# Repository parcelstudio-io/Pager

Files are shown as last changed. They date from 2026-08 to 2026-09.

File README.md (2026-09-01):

# Mochi Pager

Mochi Pager is a pager-sized, expressive voice AI companion. The first product target is a rounded handheld device with two large round eyes, curious idle gaze, a sliding live caption, microphone, speaker, Wi-Fi, BLE, and optional standalone 4G LTE—and exactly two physical controls: the top conversation button and a power slide switch. The conversation button deliberately opens or closes a visibly live session; while it is open, the user and assistant can speak in a full-duplex, voice-interruptible conversation without pressing for each turn, while the assistant's words slide through the caption below its face. A companion mobile app onboards the device over BLE (Wi-Fi credentials, cellular APN, account claiming) and shows an encrypted local cache of opt-in cloud conversation history. The pager connects through a private gateway to the OpenAI Realtime API; it does not run the language model on the device.

The current phase is V1 interaction implementation plus EVT (engineering validation) planning. A zero-dependency local session broker and browser device simulator now provide the first runnable full-duplex slice; embedded firmware, the mobile app, cloud history, and cellular work remain staged behind it.

## Start here

- [Product concept](docs/design/0001_mochi_pager_product_concept.md)
- [V1 prototype high-level design](docs/prototype/0001_v1_high_level_design.md)
- [V1 beginner build guide and exact materials](docs/prototype/0002_v1_beginner_build_guide.md)
- [Companion app and synchronization architecture](docs/design/0002_companion_app_and_sync_architecture.md)
- [Carrier board hardware design](docs/design/0003_mochi_carrier_board_design.md)
- [MVP requirements](docs/requirements/0001_mvp_requirements.md)
- [Component sources and staged BOM](docs/research/0001_component_sources_and_bom.md)
- [Shared-conversation and video source audit](docs/research/0002_reference_observations.md)
- [Independent verification and corrections](docs/research/0003_independent_verification_and_corrections.md)
- [35-project-day build plan plus companion-app track](scrum/20260830/task_0001/daily_plan.md)
- [Technical decision log](docs/decisions/README.md)
- [Beginner IoT and electrical-engineering course](edu/README.md)

## Current verdict

The interaction mule is already ordered: one full M5Stack CoreS3 K128, recorded in the [daily log](scrum/20260830/task_0001/daily_log.md). Confirm only a known-good data-capable USB-C cable now; do not buy a second CoreS3. First run the laptop V1-A slice, then use the K128's documented full-duplex audio path to measure simultaneous capture/playback, AEC feasibility, voice barge-in, on-device captions, and truthful session indication. Use Wi-Fi and then a phone hotspot before adding radio complexity. Buy the separate SIM7600G-H cellular mule only after the Wi-Fi full-duplex vertical slice passes its gate. Do not buy a final battery, custom display, bare cellular module, or 5G hardware yet.

This ordering protects the project from three expensive early mistakes: choosing an enclosure before measuring the parts, choosing a battery before measuring modem peaks, and integrating RF onto the first PCB.

The major load-bearing claims reviewed in the 2026-08-30/31 verification pass, its corrections, and its explicitly unverifiable items are logged in [research 0003](docs/research/0003_independent_verification_and_corrections.md). That pass also added requirements the first draft missed: the sliding caption, companion app, and two-control constraint.

## Run V1-A now

Node.js 20 or newer and an OpenAI API project are required. The standard API key stays in the local server process.

```bash
cp .env.example .env
# Edit .env and replace OPENAI_API_KEY=replace_me
npm test
npm start
```

Then open `http://localhost:3000`. No `npm install` is required because V1-A has no runtime package dependencies. The idle face begins calm and centered: its first curious gesture arrives after 3–5 seconds, later gestures follow 6–12 second pauses, and every synchronized up/down glance, side-to-side look-around, or clockwise/counterclockwise roll returns to center. Each gesture now uses brief saccades separated by still fixations instead of continuous pupil drift; the cream eye aperture follows vertical gaze like an eyelid opening, while speaking no longer produces a rhythmic eye bob. Conversation and battery state take priority. Face animation loads as an optional enhancement after Start/Stop is wired, so an animation import or initialization failure leaves a static face without disabling conversation control. The gateway renders the versioned [`prompt/mochi-realtime.ftl`](prompt/mochi-realtime.ftl) on the server, so the browser cannot inject history or system instructions. The localhost default has no real account/history service and truthfully marks that context unavailable. API use may incur charges; set a conservative project budget before testing. The [beginner build guide](docs/prototype/0002_v1_beginner_build_guide.md) contains the complete safety, setup, acceptance, and CoreS3 bring-up sequence.

## Repository organization

```text
docs/
  decisions/       numbered architecture decision records (ADRs)
  design/          product and industrial-design specifications
  requirements/    measurable product requirements
  research/        source audits, comparisons, and BOMs
edu/               progressive IoT and electrical-engineering course for software engineers
prompt/            version-controlled server-side Realtime instruction templates
scrum/
  YYYYMMDD/
    task_NNNN/      task brief, daily plan, evidence, and retrospective
hardware/           future PCB and mechanical source files
src/                production device, gateway, companion-app, and cloud code only
tests/              automated tests spanning production components
tools/              simulators, fixtures, flashing, and developer utilities
```

Create directories only when they gain real content. When implementation begins, a sensible source split is `src/device/`, `src/gateway/`, `src/app/` (the companion mobile app), and `src/cloud/`. Hardware design should live in `hardware/pcb/` and `hardware/mechanical/`, not under `src/`.

Task IDs are repository-wide, zero-padded, and monotonically increasing. Decision records have their own monotonically increasing sequence because a decision's history is independent of sprint/task history. Never renumber an accepted or superseded record.

## Reference boundary

The shared ChatGPT post exposes only one answer, which proposes a **95 × 60 × 30 mm** enclosure. The earlier conversation is not present in the public page, so this repository treats that size as a maximum envelope rather than inventing unavailable prior decisions.

The visual reference is Huy Vector's [Tiny Pocket AI Assistant](https://www.youtube.com/watch?v=25RGnr407PM) and its [build guide](https://www.huyvector.org/robots-kinetic/pocket-ai-assistant). We borrow its face-first charm, blinking eyes, compact status text, and cheeky personality. We do not copy its exposed battery, conductive frame, cloud service, or electronics as a product architecture.

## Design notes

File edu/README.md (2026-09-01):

# Educational notes

This folder is a small course for a software engineer who is new to electronics, embedded systems, and Internet of Things (IoT) products. It assumes you can read code, reason about APIs, and debug distributed software. It does **not** assume you know what voltage, ground, a GPIO pin, a modem, or a printed circuit board does.

Start with lesson `0000`. Do not skip it because its concepts are the vocabulary used by every later lesson.

## If your goal is to design a PCB in KiCad

Follow the [PCB design path](PCB_DESIGN_PATH.md). It turns the general course into staged work with evidence gates:

1. learn the electrical foundations in lesson `0000`;
2. learn the [core circuit patterns used in real schematics](CORE_CIRCUITS_FOR_PCB_DESIGN.md);
3. design, fabricate, and measure the [LED and button board](labs/0001_led_button_board.md);
4. design and bring up the [compute-module carrier](labs/0002_module_carrier_board.md); and
5. only then capture and review a modular Mochi carrier.

The goal is not merely to operate KiCad. It is to make a board whose circuit was calculated, whose exact parts and footprints were verified, whose manufacturing files were inspected, and whose physical behavior was measured safely.

## How these lessons teach

Each lesson should:

- define a physical or networking concept before using its acronym;
- connect it to a familiar software idea, then state where that analogy stops working;
- include a concrete Mochi example or calculation;
- separate general teaching from the exact product decision;
- end with questions you can answer without memorizing prose.

Hardware ultimately follows physics and component datasheets, not an analogy. Examples such as voltages, resistor values, current, and battery life are explicitly illustrative unless they cite a measured prototype or accepted requirement.

## Reading order

0. [Start here: IoT and electrical fundamentals](0000_start_here_iot_and_electrical_fundamentals.md) — circuits, voltage, current, power, ground, digital pins, regulators, sensors, actuators, safe measurements, and the device/network/service loop.
1. [System architecture from a button press](0001_system_architecture.md) — how to divide one physical product into local state, realtime data paths, networks, and services.
2. [Modules, buses, and embedded audio](0002_modules_buses_and_audio.md) — how boards and chips communicate, and how microphone and speaker samples move on time.
3. [Printed circuit boards and manufacturing](0003_pcb_fundamentals_and_manufacturing.md) — how a schematic becomes physical copper, an assembled board, and a controlled first power-on.
4. [Cellular, radio, power, and certification](0004_cellular_rf_power_and_certification.md) — how a modem reaches a carrier, why antennas and current bursts are physical design problems, and what module approval does not cover.
5. [Realtime voice, memory, and privacy](0005_realtime_voice_memory_and_privacy.md) — sampled sound, streaming, full duplex, echo cancellation, interruption, gateway trust, and distinct kinds of memory.
6. [Companion apps, Bluetooth setup, and synchronization](0006_companion_app_provisioning_and_sync.md) — provisioning, claiming, Bluetooth Low Energy, secret paths, authoritative revisions, history cursors, and deletion tombstones.
7. [Reading the Mochi carrier schematic](0007_reading_the_carrier_schematic.md) — pin budgets, voltage domains, burst-current arithmetic, tuned decoupling, and what desk verification can and cannot prove.

Use the [plain-language glossary](GLOSSARY.md) whenever a later document introduces an unfamiliar term. The lesson must still explain important terms inline; the glossary is a backup, not required pre-reading.

The [KiCad lab index](labs/README.md) links the hands-on exercises. These are fabrication exercises, so each has a completion gate; do not treat a clean screenshot, ERC, or DRC as a passing result.

## A practical first pass

If the complete course feels large, use this order:

1. Read sections 1–9 of lesson `0000` and answer its self-check.
2. Run the existing browser prototype; identify its device, network, and service boundaries using lesson `0001`.
3. With the purchased CoreS3 still unmodified, follow lesson `0000`'s measurement workflow and the beginner build guide. Do not begin by designing a battery charger or cellular PCB.
4. Read lessons `0002`–`0004` immediately before working with that hardware.
5. Read lessons `0005`–`0006` before changing the Realtime gateway, memory model, provisioning flow, or companion app.

When stuck on a hardware sentence, ask four questions:

```text
What supplies the energy?
What path does current take out and back?
Which component owns the signal or state?
What measurement would prove the claim?
```

Those questions turn words such as "rail," "bus," "ground," and "live" into testable statements.

## Teaching versus specification

Files in `edu/` explain mental models. They are not the product specification. Accepted product choices live in `docs/decisions/`, measurable requirements live in `docs/requirements/`, detailed designs live in `docs/design/`, and executable code lives in `src/` or `tools/`.

The primers link to those sources at the end. When a teaching example and an accepted requirement differ, the accepted requirement controls the product.

Add future lessons with the next monotonic prefix. Lesson `0000` is the one intentional prerequisite inserted before the original numbered series.

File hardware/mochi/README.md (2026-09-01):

# Mochi R1 Walter carrier

This directory contains a deterministic **electrical reference and placement study** for
the pager-size Mochi companion. It is intentionally useful for architecture review,
firmware pin contracts, component purchasing, and mechanical experiments. It is **not a
fabrication release**.

The current baseline is a 60 × 82 × 1.2 mm four-layer carrier around the orderable
QuickSpot Walter LTE-M/Wi-Fi/BLE/GNSS SoM. The previously proposed MIKROE-6396 Click was
removed because its official product page now reports it unavailable. The design decision
and alternatives are recorded in [ADR 0013](../../docs/decisions/0013_use_walter_family_for_rev_a_evt.md).

## Files

- [`mochi.kicad_sch`](mochi.kicad_sch) — KiCad system-level schematic.
- [`mochi.kicad_pcb`](mochi.kicad_pcb) — four-layer outline and reviewed component
  placement; intentionally unrouted.
- [`doc/design_manifest.json`](doc/design_manifest.json) — machine-readable electrical,
  configuration, and release-boundary contract.
- [`doc/bom.csv`](doc/bom.csv) — proposed parts and DNP state.
- [`doc/connectivity.csv`](doc/connectivity.csv) — exact named-net endpoints.
- [`doc/pin_map.csv`](doc/pin_map.csv) — Walter/ESP32 GPIO assignment.
- [`doc/bringup_and_validation.md`](doc/bringup_and_validation.md) — physical proof plan.
- [`doc/research_matrix.md`](doc/research_matrix.md) — dated primary-source comparison.
- [`reports/`](reports/) — KiCad/MCP and command-line check evidence.

The generated `Mochi_Reference.pretty` footprints are review geometry, except that the
Walter header pitch, pin order, pad centers, and antenna keepout follow QuickSpot's open
footprint. Every footprint must still be replaced or independently checked against the
exact ordered part and assembly process before fabrication.

## Reproduce the desk checks

From the repository root:

```bash
node tools/hardware/generate_mochi_reference.js
python3 tools/hardware/check_carrier_design.py
```

The current expected result is **66 passed, 2 warnings, 0 failed**. The warnings are
deliberate: the PCB has no routes, and the back-mounted Walter reference produces one
library-parity warning. KiCad ERC is zero. KiCad DRC otherwise reports the 168 expected
unconnected items and no unexpected physical-rule category.

KiCad MCP was also pointed at this exact project. Its full production quality gate is
expected to fail and is retained as useful evidence: a label-oriented system schematic
has zero explicit wires, the PCB is unrouted, and reference footprints are not a release
library. MCP did confirm clean ERC, 100% schematic-to-PCB named-pad transfer, matching
reference sets, a 60 × 82 mm frame, and zero courtyard issues.

## What the board connects

```text
USB-C charge only ─ protection ─ BQ25628E ─ SYS_ALWAYS ─ TPS22950 ─ SYS_SW ─ Walter VIN
                             │                    ▲                    └─ 200uF EVT reservoir
protected 1S pack + NTC ─────┘                    │
                                           latching slide

SYS_SW ─ TPS63802 ─ 3V3_PERIPH ─┬─ LCD + touch
                                ├─ MAX98357A ─ differential 8ohm speaker
                                ├─ TPS22918 ─ MIC_3V3 ─ PDM mic + isolation + cyan LED
                                └─ DNP TPS22918 ─ Arducam Mega + white LED
```

Walter contains the ESP32-S3, Wi-Fi/BLE, LTE-M/NB-IoT modem, nano-SIM, GNSS, RF front
end, and modem-to-ESP UART. The carrier therefore does not route a 50-ohm cellular trace,
SIM bus, 1.8 V modem GPIO, or user USB data.

## Stop conditions

Do not order a PCB from this directory until all of these are true:

- production symbols, footprints, land patterns, paste apertures, and exact order codes
  are frozen;
- the schematic is redrawn with conventional wires/hierarchy and peer-reviewed;
- the power stages are laid out from vendor reference layouts and the entire PCB is
  routed with zero unexplained ERC/DRC findings;
- enclosure CAD closes around the display, battery, speaker cavity, module, USB, switches,
  coax bends, and LTE antenna;
- a physical prototype passes the validation plan; and
- an RF/certification lab accepts the portable simultaneous-transmitter plan.

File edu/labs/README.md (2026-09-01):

# KiCad PCB labs

These labs convert the electrical lessons into fabrication evidence. Complete them in order:

1. [LED and button board](0001_led_button_board.md) — a low-voltage, through-hole, two-layer board whose behavior can be calculated and measured.
2. [Compute-module carrier](0002_module_carrier_board.md) — a modular embedded board with power, GPIO, connectors, debug access, decoupling, and test points.

Use the current stable KiCad release and the official [Getting Started in KiCad 10](https://docs.kicad.org/10.0/en/getting_started_in_kicad/getting_started_in_kicad.html) guide. The detailed [Schematic Editor](https://docs.kicad.org/10.0/en/eeschema/eeschema.html) and [PCB Editor](https://docs.kicad.org/10.0/en/pcbnew/pcbnew.html) manuals are the primary references for current controls. Menu names can move between versions, but the engineering sequence remains schematic → footprints → ERC → board rules → placement → routing/zones → DRC → fabrication outputs → inspection.

Do not skip a lab's gate. A rendered board image or clean DRC is not a working-board result.

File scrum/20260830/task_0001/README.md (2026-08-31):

# Task 0001 — Design and validate the Mochi Pager EVT path

Start date: 2026-08-30  
Status: In progress — Day 1 purchase made 2026-08-31, see [daily log](daily_log.md)
Owner: Project team

## Outcome

Produce an evidence-backed EVT that demonstrates a cute local face with a sliding live caption and a button-started, visibly live, full-duplex voice conversation through our secure OpenAI Realtime gateway. Inside the live session, capture and playback are concurrent and speech interrupts assistant output without a per-turn press; a second button press returns to private idle. The shipping interaction exposes exactly two physical controls: one illuminated conversation start/stop button and one latching power on/down switch. Also validate the hybrid companion architecture: foreground BLE for secure nearby provisioning/recovery, the gateway as the authority for account binding, non-secret settings, and opt-in history, Wi-Fi and phone-hotspot portability, and a separately measured standalone-LTE option. End with either a reviewed modular-carrier PCB order and validated assembled boards or a documented gate failure with the specific next experiment.

## In scope

- Product interaction and expression system, including the sliding caption (PR-07).
- ESP32-S3 interaction mule.
- Gateway and OpenAI Realtime integration.
- Companion-app Track B: foreground BLE provisioning (Security 2 with downgrade rejection), secure claiming/recovery, BLE/local-only custom Wi-Fi/APN/authentication secrets, cloud-delivered signed public carrier presets, binding-scoped revisioned configuration, and opt-in history synchronization (ADR 0007 and the companion-app requirements).
- Wi-Fi, hotspot, and conditional standalone 4G tests.
- Audio, latency, data, power, thermal, and reconnect measurements.
- Paper/foam and printed enclosure iterations.
- Conditional four-layer modular carrier PCB.
- Education, purchasing rationale, and ADR trail.

## Out of scope for this task

- Full 5G integration.
- Injection-mold tooling or production certification.
- Bare cellular LGA routing on the first PCB.
- Background always-listening/wake-word launch behavior or a production-grade guarantee that AEC works in every acoustic environment. Functional session-scoped full duplex is in scope and gated.
- A shipping/user-facing push-to-talk or half-duplex mode. Half-duplex may be measured only in developer fixtures to diagnose an acoustic failure; it fails Gate A rather than becoming a third interaction mode.
- General-purpose BLE pairing, audio, or accessory support; BLE is reserved for foreground commissioning/recovery in this EVT.
- Camera features, GPS-backed product features, and bulk component orders.
- Production launch, consumer data-policy sign-off, or carrier certification completion.

## Purchase ceilings before re-approval

- Gate A actual board purchase: one full CoreS3 K128 ($77.90 paid on 2026-08-31), plus a known-good cable ($5–10 observed if none is already available), tax/shipping. See the [daily log](daily_log.md).
- Acoustic mule, only after Day 8's concurrent local audio baseline: one compatible discrete digital mic ($8.95 observed), I²S amp ($5.95), speaker ($1.95), illuminated conversation control, latching power switch, and safe prototyping board/connectors; target $20–40 plus shipping after pin/power/reference-path review.
- Gate B, only after Day 13: one SIM7600G-H HAT ($97.99 observed), one compatible AUX/diversity LTE antenna (live quote), and **one** SIM/service path. Order a low-cost SIM first, read/check the received IMEI, then activate one month of suitable 5–10 GB-equivalent data. Soracom and direct-carrier plans are alternatives, not combined purchases.
- Instrumentation: a $15–30 USB meter may be bought for average energy only. Gate C peak evidence requires access to a bandwidth-appropriate oscilloscope/current probe or shunt/power analyzer and an adequate documented 5 V HAT supply; quote, borrow, or rent before purchase if these are not already available.
- Gate C: no PCB/enclosure order until a live quote, BOM, measured power budget, and DFM review are attached to the daily log. Quote rather than assume cost.
- 5G and bare production cellular modules: $0 in task 0001.

All prices were observed on 2026-08-30 and are not purchase guarantees. Recheck price, lead time, return policy, region, carrier/IMEI acceptance, and shipping at checkout.

## Success evidence

- A recorded live session with at least ten exchanges and no per-turn presses, concurrent capture/playback evidence, a caption that tracks speech and trims on interruption, speech-driven barge-in, explicit button stop, and recovery after network loss. The capture gate and its indicator fail low through reset, crash, bootloader, and OTA paths; hard-off prevents auto-resume and USB/debug/modem back-power.
- A recorded first-boot and recovery walkthrough: foreground Security 2 BLE provisioning with downgrade attempts rejected and no plaintext custom Wi-Fi/APN/authentication secrets in a BLE trace, cloud, durable app storage, or logs; provisioning remains alive through claim and new-recovery-proof acknowledgement; signed public carrier-preset metadata may come from the cloud; and the eight-second power-on boot chord is capture-gated but cannot steal or reclaim an owned pager. Factory bootstrap fails after first claim, every new binding rejects the prior owner's recovery code, and an online app opens claimed-device setup only after authenticated app→gateway authorization; offline setup uses the touchscreen or boot chord. Release/recovery erases local network/cellular credentials, and resale/loss/account-deletion flows handle physical-SIM removal or carrier deactivation explicitly.
- A recorded app synchronization walkthrough: binding-scoped app- and pager-origin `config_revision` conflict/idempotency handling plus default-off history opt-in/inspect/export/delete across two app installations, offline recovery, reinstall/restore, ordered cursor catch-up, and content-free deletion tombstones. It demonstrates expected-version conflicts, `oldest_available_seq` full reconciliation, a device-bound backup-excluded cache, retained-history access after future saving is disabled, derived-memory deletion cascades, and truthful account-deletion behavior across the at-most-24-hour offline authorization lease. Stored history contains only finalized machine transcripts, the assistant prefix known to have been heard (or an interruption marker), sanitized visible tool results, and no raw audio.
- Reviewed privacy copy that distinguishes Mochi-controlled storage from the current provider data-retention policy and does not promise zero provider retention without verified approved controls.
- At least 50 timed Wi-Fi speech segments, a 100-utterance endpoint-correctness corpus, 100 scripted barge-ins, 60 assistant-speaking minutes for false-interruption testing, a 65-minute duplex/provider-renewal soak, and a 30–60 minute phone-hotspot session.
- If Gate B opens: standalone LTE attach/reconnect, signal, data, average/peak current, temperature, GNSS trial, and one exact ESP32-S3 modem transport under concurrent encrypted voice/display/audio load.
- Current/energy measurements supporting the battery decision.
- Mechanical volume model plus measured AEC reference delay, residual echo, double-talk, false-interruption, and acoustic-layout observations.
- Reviewed schematic/layout/DFM evidence before any PCB purchase.
- Incoming inspection and bring-up records for any ordered PCBs.
- New ADRs for decisions that changed during execution.

## Planning sources

- [Product concept](../../../docs/design/0001_mochi_pager_product_concept.md)
- [Companion app and synchronization architecture](../../../docs/design/0002_companion_app_and_sync_architecture.md)
- [MVP requirements](../../../docs/requirements/0001_mvp_requirements.md)
- [Component research](../../../docs/research/0001_component_sources_and_bom.md)
- [Independent verification and corrections](../../../docs/research/0003_independent_verification_and_corrections.md)
- [Full-duplex interaction decision](../../../docs/decisions/0006_use_button_started_full_duplex_sessions.md)
- [Companion app decision](../../../docs/decisions/0007_use_companion_app_and_cloud_history_sync.md)
- [Two physical controls decision](../../../docs/decisions/0008_use_exactly_two_physical_controls.md)
- [Daily plan](daily_plan.md)

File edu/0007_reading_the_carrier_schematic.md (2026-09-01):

# 0007 — Reading Mochi's carrier design as a software engineer

This lesson teaches enough PCB/EE vocabulary to review the Mochi R0 reference without
pretending that reading a schematic makes someone an RF or power-layout engineer. Keep
the [design explanation](../docs/design/0003_mochi_carrier_board_design.md),
[schematic](../hardware/mochi/mochi.kicad_sch), and
[connectivity contract](../hardware/mochi/doc/connectivity.csv) open beside it.

## 1. Start with the right mental model

A schematic is closer to a typed dependency graph than to a map:

- a **component** is an object with named pins;
- a **net** is a shared variable connecting pins;
- a pin's electrical type is something like an interface contract;
- a data sheet is the component's API, limits, timing contract, and deployment guide;
- ERC is a type/lint check;
- a PCB is the physical implementation, where distance, geometry, heat, fields, and
  current return paths become behavior;
- DRC checks geometric rules, not whether the product has good RF, audio, or thermals.

Two wires with the same net label are electrically connected even if the schematic draws
them on different pages. Conversely, two traces that look close on a PCB are not connected
unless copper actually joins them.

R0 is intentionally a **module-level** graph. It names major ICs and high-risk interfaces
but omits the released inductors, feedback resistors, decoupling network, exact land
patterns, and routing that a fabrication design requires. Its PCB is a placement study
with ratsnest lines, not routed copper.

## 2. Voltage is state; current is flow; power is the bill

A software analogy that mostly holds:

- voltage resembles pressure or a value relative to a reference;
- current is the amount flowing per second;
- resistance impedes flow and creates voltage drop;
- capacitance stores a small amount of charge locally;
- power is `voltage × current` and turns into work or heat;
- energy is `power × time` and determines battery life.

Always ask “relative to which ground?” A net named `3V3` means about 3.3 V relative to
`GND`. Current also needs a **closed loop**: from a source, through the load, and back to
the source. PCB return-current geometry matters just as much as the outward signal trace.

Example: 900 mA at 3.8 V is 3.42 W. It is not the same claim as 900 mA at 5 V, and neither
is a battery-life number. If a converter supplies 5.5 W from a 3.3 V pack at 93%
efficiency:

```text
pack current = output power / (pack voltage × efficiency)
             = 5.5 W / (3.3 V × 0.93)
             ≈ 1.79 A
```

That is why a small LTE design can be limited by amperes and voltage sag even when its
average watt-hours look acceptable.

## 3. Read Mochi one rail at a time

Do not begin with every signal. Highlight the power rails in this order:

```text
VBUS_5V ── BQ25628E ── SYS_ALWAYS
PACK_P/N ─────┘             │
                            ├─ SW1/U5/U6 ── SYS_SW ── 3V3
                            └─ SW1/U7/U8 ── LTE_5V_RAW ── CELL_5V
3V3 ── U12 when CAPTURE_EN ── MIC_3V3
3V3 ── U15 when CAM_EN ────── CAM_3V3  (DNP)
```

`SYS_ALWAYS` is intentionally attached to the charger/power path, battery, fuel gauge,
and the inputs of the two switched trees. `SW1` drives enable pins; the large current goes
through semiconductor switches, not through a tiny front-panel contact.

When SW1 is off, all product/sensor rails must collapse. The charger and 7 µA-class gauge
may remain alive. This distinction prevents an imprecise promise such as “the battery is
physically disconnected.”

### Back-power is an unexpected import cycle

A supposedly dead rail can be energized backward through USB data protection, a debug
adapter, another module's I/O, or a second USB connector. This is called **back-powering**.
It can make a privacy claim false and can damage an unpowered IC.

Mochi's defenses are layered:

- TPS61236P truly disconnects its boost output in shutdown.
- TPS2001E blocks reverse current and discharges/limits `CELL_5V`.
- TS3USB3000 makes USB D+/D− high impedance when 3.3 V is absent.
- Fixture debug pins may not inject power.
- MIKROE-6396 diode D3 must be removed so its recovery USB cannot feed the modem.

The schematic says this should work. Verification means putting meters/supplies on every
entry path with SW1 off and measuring voltage/current, including fault cases.

## 4. Digital buses are protocols plus electrical rules

### UART: two streams, crossed names

UART has independent transmit and receive wires. A transmitter connects to the other
device's receiver:

```text
ESP IO41 TX  ── LTE_TX ──> Click physical RX
ESP IO42 RX  <── LTE_RX ── Click physical TX
ESP IO1  RTS ── LTE_RTS ─> Click RTS/CS
ESP IO2  CTS <── LTE_CTS ── Click CTS/INT
```

The first pair is crossed. RTS/CTS meanings depend on the modem contract, not a guess
based on English names; the official Click schematic confirms these directions. RTS/CTS
is hardware backpressure, analogous to a bounded queue signaling “stop writing.”

At 3 Mbaud with 8N1 framing, each payload byte consumes ten line bits:

```text
3,000,000 × 8 / 10 = 2,400,000 payload bits/s
```

That easily exceeds a compressed voice stream on paper. It does not prove PPP/socket
throughput, scheduling, or no dropped bytes while Wi-Fi, display, AEC, and flash run.

### I²C: one shared, addressed control bus

`I2C_SDA` carries data and `I2C_SCL` carries the clock. Devices share both wires and use
addresses, much like services sharing a bus with routing keys:

- BQ25628E charger: `0x6A`
- MAX17055 gauge: `0x36`
- TCA9534A expander: `0x20`
- CST816 touch controller: probably `0x15`; confirm the exact module variant

I²C lines are normally open-drain and need pull-ups. Their voltage domain, pull-up value,
bus capacitance, startup state, and behavior when one device is unpowered matter in the
released schematic even though the R0 module graph abstracts some of them.

### SPI: a fast shared bus with per-device selection

The LCD and DNP camera option share `SPI_SCK` and `SPI_MOSI`; each gets a distinct chip
select. The LCD does not need MISO, while a future camera might. Sharing saves GPIO, but
firmware must serialize transfers and each unselected device must release the bus.

### I²S and PDM: audio sample transport, not analog audio

I²S carries rendered samples from ESP32 to MAX98357A using bit clock, word clock, and data.
PDM carries a one-bit high-rate microphone stream using clock and data. The amplifier turns
samples into switched power for the speaker; the ESP decimates PDM into PCM samples.

The class-D output is **BTL (bridge-tied load)**. `SPK_P` and `SPK_N` both switch. Never
ground either speaker lead and never attach a normal ground-referenced oscilloscope probe
to one without a differential measurement plan.

## 5. Follow the privacy invariant in copper

The product invariant is:

```text
microphone can produce usable data  ⇒  cyan indicator is powered
```

In the schematic:

1. IO40 is `CAPTURE_EN`.
2. R7 pulls it down during reset, boot, and an undriven state.
3. U12 only creates `MIC_3V3` when that net is active.
4. `MIC_3V3` powers the microphone, the PDM isolation buffer, and D1's anode.
5. Therefore firmware has no second GPIO with which to lie about the cyan LED.

This is stronger than two adjacent software calls. It is not equivalent to a mechanical
microphone disconnect: malicious firmware can enable both truthfully, and an LED/load-
switch fault can break the implication. The latching system-power slide is the hard
physical boundary. Test the capture circuit through reset, crash, watchdog, recovery,
OTA, stuck pins, LED open, and switch short.

## 6. Understand the audio/AEC choice

Full-duplex conversation means the mic hears Mochi's own speaker. Acoustic echo
cancellation needs two time-aligned sequences:

- the microphone samples;
- the samples Mochi intended to render.

R0 sends the AEC the rendered PCM after software volume, mute, and cancellation decisions.
This is deterministic and does not require connecting an ADC to a switching BTL output.
It cannot capture every amplifier, speaker, enclosure, or clock imperfection. Only the
finished acoustic stack can answer whether echo return loss, double-talk, and barge-in are
good enough.

Software engineers should think about timestamps, bounded buffering, sample-rate
conversion, render cursor vs heard cursor, cancellation, and discontinuities. An EE or
acoustics engineer must also think about mic/speaker placement, leakage paths, chamber,
gaskets, distortion, clipping, and gain.

## 7. Read the component and GPIO contracts

Generated human-readable files are often easier to audit than clicking every KiCad pin:

- [`bom.csv`](../hardware/mochi/doc/bom.csv): exact proposed part/role, DNP state, source,
  and the warning that footprints are reference-only.
- [`connectivity.csv`](../hardware/mochi/doc/connectivity.csv): every net and endpoint.
- [`pin_map.csv`](../hardware/mochi/doc/pin_map.csv): ESP GPIO allocation.
- [`design_manifest.json`](../hardware/mochi/doc/design_manifest.json): machine-readable
  configurations, release status, limits, hard-off contract, and component pins.

When reviewing a net, ask:

1. Who drives it, and in which direction?
2. Who can pull it up or down before firmware runs?
3. What voltage domain is each endpoint in?
4. What happens if either side has no power?
5. Is it a fast edge or high current that layout can corrupt?
6. Is there a test point or measurable symptom?
7. Does a failure violate privacy, battery safety, or RF rules?

The full pin map avoids ESP IO35–37 because octal PSRAM uses them and avoids functional
loads on boot straps IO0/3/45/46. IO0 only reaches a pulled-up fixture boot net. USB is
fixed to IO19/20.

## 8. Schematic correctness is not PCB correctness

A routed PCB must add constraints the graph cannot express well:

- short, wide high-current loops around charger and converters;
- exact inductors/capacitors and their current/voltage/temperature derating;
- uninterrupted high-frequency return paths;
- USB 90 Ω differential geometry and ESD parts next to the connector;
- Kelvin sense traces that do not carry load current;
- ESP antenna keepout on every copper layer at a plastic edge;
- bottom microphone port with no copper/debris and an acoustic gasket;
- class-D output kept away from mic/PDM/RF;
- thermal copper and enclosure touch-temperature limits;
- verified production footprints, paste apertures, courtyard, assembly orientation, and
  accessible test points.

The carrier outline being 58 × 82 mm proves only two planar dimensions. The battery,
display, LTE Click, speaker chamber, sockets, antenna, cable bends, bosses, and plastics
must close in 3D.

## 9. The verification ladder

Each rung can catch a different class of mistake:

1. **Arithmetic/table audit** — addresses, GPIO, voltage, current, bandwidth, bands.
2. **Contract checker** — exact endpoints and invariants across generated artifacts.
3. **KiCad ERC** — parse/electrical rule consistency.
4. **KiCad DRC/visual review** — routing geometry, clearances, footprints, return paths.
5. **Manufacturer DFM/assembly review** — fabrication and placement capability.
6. **Bench power tests** — ramps, load steps, inrush, brownout, reverse/back-power, heat.
7. **Firmware integration** — USB, display/touch, audio, modem flow control and recovery.
8. **Acoustic/mechanical tests** — chamber, port, AEC, barge-in, drop/handling.
9. **RF tests** — VNA, TRP/TIS, desense, coexistence, hand/body effects.
10. **Compliance/carrier tests** — FCC/SAR/Part 15B, PTCRB, carrier, Bluetooth, battery.

Passing rung 3 cannot imply rung 10. R0 currently passes the desk contract and schematic
ERC. DRC deliberately reports unrouted connections because this is a placement reference.

Run the reproducible checks:

```bash
node tools/hardware/generate_mochi_reference.js
python3 tools/hardware/check_carrier_design.py
```

Expected current summary: 54 passes, two explicit warnings, zero failures. One warning is
that the PCB is not fabrication-ready; the other is that DRC remains non-zero for the
intentional opens/reference-footprint parity.

## 10. Review exercise

Without looking at the answer, trace these in `connectivity.csv`:

1. Which pins prove ESP transmit reaches Click receive?
2. Which downstream rail powers both microphone and cyan LED?
3. What components can still touch the pack with SW1 off?
4. Why does `CELL_5V` require both a true-disconnect boost and removal of the Click's D3?
5. Why can the speaker's `-` pin not connect to GND?
6. Which camera parts are DNP, and why is J6 not a promise of sensor compatibility?

Answers: `U10.IO41/J3.RX`; `MIC_3V3`; charger/power path and gauge; independent back-power
paths exist on both carrier and daughterboard; the amp is differential BTL; U15/J6/D3/R11
are DNP and the exact adapter/sensor pinout remains unfrozen.

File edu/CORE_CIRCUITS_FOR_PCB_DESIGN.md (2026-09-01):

# Core circuits for PCB design

This chapter turns the quantities in lesson `0000` into a small design toolkit. Treat a schematic as executable architecture with physical types: each wire has voltage, current, direction, timing, and ownership constraints.

All examples use low-voltage direct current. Numerical values are illustrative until verified against the exact component datasheet and measurement.

## 1. Nodes, branches, and loops

A **node** is a set of connected conductors that ideally share one voltage. A **branch** is one current path between nodes. A **loop** is a closed path that returns to its source.

Kirchhoff's current law (KCL) says current into a node equals current out. It is conservation of charge. If a 3.3 V regulator supplies a 20 mA sensor, 80 mA processor, and 10 mA LED in parallel, it supplies approximately `20 + 80 + 10 = 110 mA` before losses and transients.

Kirchhoff's voltage law (KVL) says voltage rises and drops around a closed loop sum to zero. For a 3.3 V supply, an LED dropping about 2.0 V, and a resistor dropping the rest:

```text
+3.3 V - 2.0 V - 1.3 V = 0 V
```

KCL finds missing current. KVL finds missing voltage. Both force you to draw the complete path rather than reason from a signal name alone.

## 2. A resistor limits LED current

An LED is polarized: its anode and cathode must be oriented correctly. Its forward voltage is not a fixed universal number, so use the exact LED datasheet.

For an illustrative 3.3 V rail, 2.0 V red LED, and desired 1.3 mA:

```text
R = (3.3 V - 2.0 V) / 0.0013 A ≈ 1000 Ω
resistor power = I²R ≈ 0.0017 W
```

A standard 1 kΩ resistor with a conventional 0.125 W or 0.25 W rating has ample power margin here. Repeat the calculation for minimum and maximum supply voltage and the LED's forward-voltage range. Never connect an ordinary LED directly across a supply.

## 3. Pull resistors define idle state

A digital input is high impedance: it observes voltage while drawing very little current. That makes an unconnected input vulnerable to leakage and coupled noise.

A common button circuit uses a 10 kΩ pull-up to 3.3 V and a normally open button to ground:

```text
released: input = 3.3 V, approximately no switch current
pressed:  input = 0 V, current through pull-up = 3.3 V / 10 kΩ = 0.33 mA
```

The button is **active-low** because pressing it produces logic low. Firmware can debounce the mechanical contacts, but the resistor supplies a safe state during reset before firmware runs.

## 4. Voltage dividers and loading

Two series resistors can produce a fraction of an input voltage:

```text
Vout = Vin × Rbottom / (Rtop + Rbottom)
```

For `Vin = 5 V`, `Rtop = 10 kΩ`, and `Rbottom = 20 kΩ`, the ideal unloaded output is about 3.33 V.

The word **unloaded** matters. A connected input draws some current and behaves like another resistance in parallel with the bottom resistor, changing the result. Dividers are suitable for measurement or bias when the receiving input impedance and transient behavior are known. They are generally not power supplies and are not automatically safe bidirectional logic-level translators.

## 5. Capacitors make circuits time-dependent

A capacitor stores charge. With a resistor it forms a resistance-capacitance (RC) network whose **time constant** is:

```text
τ = R × C
```

After one time constant a charging capacitor reaches about 63% of its final voltage; after roughly five it is near its final value. A 10 kΩ resistor and 100 nF capacitor have `τ = 1 ms`.

This explains why reset circuits, button filters, and power rails do not change instantaneously. It does not mean any random resistor-capacitor pair is a valid reset or debounce design: input thresholds, leakage, tolerances, startup ramps, and repeated presses matter.

A decoupling capacitor is a special use of local charge storage. Place it close to a chip's supply and ground pins so the fast current loop is physically small. Use the values and placement shown in the component's reference design.

## 6. Diodes protect direction and inductive loads

A diode conducts much more readily in one direction. Its schematic symbol, PCB footprint, and physical package must agree on polarity.

An inductive load such as a relay coil or motor resists a sudden current change. Switching it off can generate a damaging voltage. A **flyback diode** across a direct-current inductive load gives that current a controlled decay path. Its orientation, voltage rating, current rating, and effect on release time must be designed; copying a symbol without understanding the loop is not protection.

Protection diodes used for electrostatic discharge (ESD) are different parts selected for fast transients, capacitance, clamping behavior, and placement near the connector. Follow reference circuits for USB and exposed connectors.

## 7. A MOSFET lets a small signal control a larger load

A metal-oxide-semiconductor field-effect transistor (MOSFET) can act as an electronic switch. In a common low-side arrangement:

- the load connects to its positive supply;
- the load's other side connects to the MOSFET drain;
- the MOSFET source connects to ground; and
- a GPIO controls the gate through the documented network.

The GPIO controls the switch; it does not provide the load current. Choose a MOSFET whose on-resistance is specified at the actual gate voltage, not merely one whose threshold voltage looks low. Threshold means “barely begins conducting under a test condition,” not “fully on.” Check drain voltage, continuous and pulsed current, heat, startup state, and whether the load needs a flyback path.

For high-side switching, bidirectional power, audio, or protected load control, use a suitable load-switch or power-path integrated circuit rather than assuming the low-side pattern transfers unchanged.

## 8. Regulators trade voltage, current, efficiency, and heat

A linear regulator discards excess voltage as heat. Approximate dissipation is:

```text
Pheat = (Vin - Vout) × Iload
```

Converting 5 V to 3.3 V at 300 mA dissipates about `0.51 W`. Whether that is safe depends on the package, copper area, ambient temperature, and thermal resistance.

A switching regulator transfers energy with an inductor and switching elements and is usually more efficient for large voltage differences or current, but its layout and component selection are more demanding.

**Dropout voltage** is the minimum input-to-output headroom a regulator needs to maintain regulation under stated conditions. A “3.3 V regulator” cannot necessarily produce 3.3 V from a battery that has fallen to 3.4 V.

For either type, verify:

- input and output voltage range;
- peak load plus margin;
- dropout or duty-cycle limits;
- efficiency over the real load range;
- required input/output capacitor type, value, and placement;
- enable-pin default and shutdown leakage;
- thermal limits; and
- behavior during startup, short circuit, power-off, and reverse voltage.

## 9. Logic compatibility is a range comparison

Do not compare only labels such as “3.3 V logic.” Compare the driver's guaranteed output-low/output-high voltages with the receiver's guaranteed input-low/input-high thresholds under the stated supply and current conditions.

Also check:

- whether either side is open-drain and needs pull-ups;
- whether a powered device can drive an unpowered device;
- whether the signal is unidirectional or bidirectional;
- startup and reset states;
- maximum pin voltage; and
- speed and edge-rate requirements.

A resistor divider may work for one slow unidirectional signal under known loading. I²C, USB, SPI clocks, and bidirectional signals need interface-appropriate solutions.

## 10. Tolerance means design a range

A 10 kΩ resistor marked ±5% may be 9.5–10.5 kΩ. Supply voltage, LED forward voltage, capacitor value, regulator output, temperature, and component aging also vary.

Do not calculate only a typical case. For each limit:

1. identify variables that can increase stress or reduce margin;
2. use datasheet minimum and maximum values where available;
3. calculate credible worst cases;
4. compare them with recommended operating conditions; and
5. measure representative boards under expected modes.

Worst-case arithmetic is the hardware equivalent of testing boundary values, except several inputs may reach unfavorable values together.

## 11. Reading a datasheet in the right order

For every selected part, inspect:

1. **Part-number table:** confirms the exact variant, voltage, temperature grade, and package.
2. **Pin description:** defines direction, power domain, internal pulls, and special startup behavior.
3. **Absolute maximum ratings:** damage boundaries, not design targets.
4. **Recommended operating conditions:** the range where normal behavior is promised.
5. **Electrical characteristics:** guaranteed thresholds, currents, accuracy, leakage, timing, and test conditions.
6. **Typical application and reference design:** required external parts and layout intent.
7. **Power-up/down sequence:** conditions that avoid undefined behavior or back-powering.
8. **Package drawing:** body dimensions, pin numbering, exposed pads, and orientation mark.
9. **Recommended land pattern:** starting dimensions for the footprint; reconcile these with assembly capabilities.

Create a one-row design record for each critical component:

| Exact manufacturer part number | Supply | Peak current | Logic | Package | Datasheet revision/link | Verified by/date |
|---|---:|---:|---|---|---|---|
| Fill this before fabrication | | | | | | |

## 12. Copper is not an ideal wire

A PCB trace has resistance. Current through it causes voltage drop and heat:

```text
Vdrop = I × Rtrace
Pheat = I² × Rtrace
```

Trace resistance depends on copper thickness, length, width, and temperature. Required width also depends on permitted temperature rise and the fabricator's process. Use an accepted calculator and the chosen fabricator's constraints, then measure voltage at the load during peak current. A wide outgoing power trace with a poor return path is still a poor circuit.

Fast digital signals add capacitance and inductance effects, so geometry and return continuity matter even when average current is tiny. Start from module and chip layout guidance; do not invent USB, antenna, or switching-regulator layout from appearance.

## 13. Connector failures are system failures

For each connector document pin 1, mating orientation, polarity, voltage, maximum current, signal direction, hot-plug behavior, cable construction, and what happens when either side is off.

Check for:

- a reversed or one-pin-shifted insertion;
- exposed power pins touching ground;
- back-power through signal pins;
- ESD from a user-accessible cable;
- insufficient current rating;
- missing strain relief; and
- silkscreen labels hidden after assembly.

Connectors cross ownership boundaries, so review them like public APIs with an adversarial client.

## Readiness self-check

Before beginning the first KiCad lab, explain and calculate:

1. Where does current flow when the LED is on?
2. Why does KCL make parallel load currents add at the regulator?
3. Why does a button input need a hardware default before firmware starts?
4. Why does a voltage divider's result change when loaded?
5. What does a 1 ms RC time constant say—and not say—about a digital input?
6. Why is MOSFET threshold voltage not proof that a 3.3 V GPIO fully turns it on?
7. What happens thermally when a linear regulator drops 5 V to 3.3 V at 300 mA?
8. Why is an absolute maximum rating not a normal operating target?
9. Which physical documents prove that a symbol pin and footprint pad represent the same lead?
10. Why must power integrity be measured at the load, not only at the bench supply?

If any answer is vague, repeat that section with an actual datasheet and a hand-drawn current loop. Then proceed to [Lab 1](labs/0001_led_button_board.md).

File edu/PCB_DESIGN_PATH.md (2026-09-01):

# PCB design path: from software engineer to a reviewed Mochi carrier

This path has one concrete outcome: design, order, assemble, and bring up a small printed circuit board (PCB), then apply the same process to a modular Mochi carrier in KiCad.

Learning KiCad's controls is the smaller part. The larger job is learning enough electronics to know what to draw and enough manufacturing discipline to know whether the drawing matches a real part. A passing electrical rules check (ERC) or design rules check (DRC) is like a clean compile: useful evidence, not proof that the product behaves correctly.

## What transfers from software engineering

| Software concept | PCB equivalent | Where the analogy stops |
|---|---|---|
| Architecture diagram | Schematic | A schematic also declares physical voltages and current paths. |
| Function or module | Circuit block | Blocks interact through power, heat, noise, and timing as well as named signals. |
| Variable or connection | Electrical net | A physical net has resistance, capacitance, inductance, and a return path. |
| Package API | Symbol and component pins | Connecting legal pin names can still violate electrical limits. |
| Package implementation | Physical part and footprint | A one-digit package or pin-number error can make the board unusable. |
| Compiler checks | ERC | ERC checks declared rules, not whether the circuit is fit for purpose. |
| Static analysis | DRC | DRC checks geometry against configured rules, not signal or power quality. |
| Build artifact | Gerbers, drill files, BOM, and placement file | The artifact can be manufactured exactly and still embody a design mistake. |
| Deployment | Fabrication and assembly | Hardware changes require rework or a new board revision. |
| Logs and debugger | Test points, multimeter, oscilloscope, and debug header | Observability must be designed into the board before it fails. |

## A realistic progression

These are learning estimates, not deadlines. Prior experience, board complexity, assembly method, and review quality change them substantially.

| Goal | Focused learning time |
|---|---:|
| Navigate KiCad and read schematics | 3–6 hours |
| Create a schematic and simple two-layer PCB | 10–20 hours |
| Order and bring up a basic working board | 25–50 hours |
| Design a reviewed modular four-layer Mochi carrier | 80–160 hours |
| Design integrated cellular radio-frequency circuitry | Not a suitable first solo PCB; involve an RF engineer |

Working part-time, a first reviewed carrier may take 6–12 weeks. Plan for at least one board revision. The schedule is less important than passing each evidence gate below.

## The staged path

### Stage 0 — Learn the physics you will use

Read:

1. [IoT and electrical fundamentals](0000_start_here_iot_and_electrical_fundamentals.md).
2. [Core circuits for PCB design](CORE_CIRCUITS_FOR_PCB_DESIGN.md).
3. Sections 1–8 of [PCB fundamentals and manufacturing](0003_pcb_fundamentals_and_manufacturing.md).

Gate: you can calculate LED current, explain a pull-up, identify a complete current loop, distinguish a pin's recommended conditions from its absolute maximum ratings, and explain why a GPIO cannot power a speaker.

### Stage 1 — Make a deliberately simple board

Complete [Lab 1: LED and button board](labs/0001_led_button_board.md). It uses only an externally regulated low-voltage supply, through-hole parts, a button, an LED, connectors, and mounting holes.

Learn symbols, footprints, net labels, annotation, board outline, placement, routing, ground fill, ERC, DRC, 3D inspection, 1:1 paper inspection, and fabrication outputs. Do not make Mochi your first KiCad project.

Gate: the assembled board passes its documented unpowered and powered measurements, and the measured LED current agrees reasonably with the calculation.

### Stage 2 — Build a module carrier

Complete [Lab 2: compute-module carrier](labs/0002_module_carrier_board.md). This introduces a replaceable microcontroller module, debug access, decoupling, test points, connectors, and a controlled external load without adding a charger or radio-frequency layout.

Gate: every pin and footprint has been checked against the exact module documentation, all rails pass bring-up, the button and indicator work, and each connector is exercised independently.

### Stage 3 — Capture the provisional Mochi schematic

Divide the product into hierarchical sheets:

- power input, power switching, and regulated rails;
- ESP32 compute module;
- display and touch;
- microphones and speaker interface;
- listening button and capture indicator;
- USB, programming, and debug; and
- modular cellular connector and power control.

Each sheet needs named voltage domains, expected typical and peak current, interface direction, test points, exact part numbers, and links to primary datasheets. Mark every unverified block:

```text
TBD — DO NOT FABRICATE
```

Gate: no such marker remains; every interface has a voltage, owner, startup state, current budget, exact pinout, and validation result from modules or a breadboard.

### Stage 4 — Lay out and review Mochi Revision A

Use the measured module prototype to validate pinouts, voltage levels, startup states, audio behavior, and current peaks. Then:

1. Configure the board stack-up and design rules from the chosen fabricator before routing.
2. Place mechanics, connectors, switches, display, module keep-outs, and antennas first.
3. Place power conversion and decoupling around the loads they serve.
4. Route critical and high-current loops, then ordinary signals.
5. Preserve continuous return paths and inspect every layer transition.
6. Run ERC and DRC, resolving rather than hiding every exception.
7. Compare every footprint with its datasheet and, for large parts, the physical component.
8. Inspect the board in 3D and print it at 1:1 scale.
9. Inspect exported Gerbers and drill files in an independent viewer.
10. Obtain review from an experienced electrical engineer before ordering 5–10 boards.

Gate: the [pre-order workflow](0003_pcb_fundamentals_and_manufacturing.md#12-beginner-pre-order-workflow) is complete and the reviewer has no unresolved safety, power, footprint, or interface findings.

## Subjects you must be able to use, not merely recognize

- voltage, current, resistance, power, and energy;
- Kirchhoff's current and voltage laws;
- pull resistors, voltage dividers, and loading;
- capacitors, resistance-capacitance timing, and decoupling;
- diodes and transistor or metal-oxide-semiconductor field-effect transistor (MOSFET) switches;
- regulators, dropout, efficiency, and heat;
- logic thresholds and level translation;
- I²C, SPI, I²S, UART, and USB electrical roles;
- ground planes and return-current paths;
- trace current, resistance, voltage drop, and temperature rise;
- battery charging and power-path management at the integration level;
- footprints, tolerances, assembly clearances, and test access; and
- reference schematics, datasheets, ERC, DRC, and manufacturing outputs.

## Scope boundaries for the first Mochi PCB

- Keep cellular on a certified, replaceable module with its intended antenna connection and keep-out rules.
- Reuse a proven protected battery pack and reviewed charging/power-path solution; do not invent a lithium-cell charger.
- Do not route mains voltage.
- Do not connect a speaker, motor, bright lamp, or radio power rail directly to a GPIO.
- Use an external current-limited supply for first power-on.
- Do not order a board with an unverified pinout, footprint, polarity, voltage domain, or `TBD — DO NOT FABRICATE` marker.

The attainable first goal is a modular carrier that connects proven modules safely and observably. A compact production LTE product remains a multidisciplinary electrical, radio-frequency, mechanical, compliance, firmware, and manufacturing project.

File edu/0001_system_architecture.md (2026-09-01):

# 0001 — System architecture: from a button press to a live conversation

## Prerequisite

Read [0000 — Start here: IoT and electrical fundamentals](0000_start_here_iot_and_electrical_fundamentals.md) first. It introduces voltage, current, power, energy, digital signals, firmware, networks, and the basic shape of an Internet of Things (IoT) system.

This lesson assumes you can build a web service, but not that you have written firmware or designed electronics.

## Learning goals

By the end, you should be able to:

- draw Mochi as a set of physical and software components;
- decide which behavior belongs on the device and which belongs in the cloud;
- describe a conversation with states and events;
- explain why listening and speaking are independent, concurrent activities—a pattern called full duplex;
- trace audio, control messages, credentials, history, and electrical power separately;
- turn a vague requirement such as “it should feel fast” into a latency budget; and
- predict safe behavior when one component fails.

## Start with one user action

Imagine the user presses Mochi's conversation button and says, “What should I cook tonight?” Several different systems participate:

1. A physical switch changes an electrical signal.
2. Firmware on the device notices that signal and changes local state.
3. The device establishes an encrypted network session with Mochi's gateway, the server-side mediator between the pager and outside services.
4. The gateway authenticates the device—verifies its claimed identity—and connects to OpenAI Realtime, the provider's live audio conversation service.
5. A microphone continuously converts sound into digital samples.
6. Those samples travel to the model while returned speech travels in the other direction.
7. The device plays the reply, moves the eyes, and scrolls the caption.
8. If the user interrupts, the device must stop the old reply while continuing to capture the correction.

To the user, this is one conversation. Architecturally, it is concurrent work across electronics, firmware, networks, backend services, and an artificial-intelligence provider.

**System architecture** is the map of those components, their responsibilities, and their boundaries. It is comparable to a service diagram for a distributed application, except some components are constrained by batteries, clocks, wires, radios, and physical safety.

## The first useful system map

The arrows below are data paths unless marked as power:

```text
                         Internet
                  encrypted audio + events
                 ┌──────────────────────────┐
                 │                          v
person       ┌──────────┐              ┌───────────┐        ┌─────────────────┐
voice ─────> │          │              │ Mochi     │ <────> │ OpenAI Realtime │
button ─────>│  pager   │ <==========> │ gateway   │        │ live session    │
eyes/speaker │          │              └─────┬─────┘        └─────────────────┘
<────────────│          │                    │
             └────┬─────┘                    │ durable configuration/history
                  ^                          v
                  │ short-range setup   ┌───────────┐
                  └ - - - - - - - - -  │ companion │
                    Bluetooth only      │ app/cloud │
                                       └───────────┘

battery ── electrical power ──> pager electronics
```

`<====>` represents a long-lived, two-way network connection. The dotted Bluetooth path is for nearby setup, not for live conversation audio.

This diagram is deliberately incomplete. Its job is to answer “what talks to what?” before we discuss implementation details.

## Boundaries are more important than boxes

A **boundary** is a place where assumptions change. In software, crossing from one process to another changes latency and failure behavior. Hardware adds more kinds of boundaries.

### Execution boundary: device versus network

The pager must own behavior that has to remain immediate or truthful when the network is slow:

- reading the conversation button;
- opening and closing the physical microphone capture path;
- rendering the face and caption;
- stopping local playback when the user interrupts; and
- showing that the connection is unavailable.

The gateway owns work that requires Internet connectivity or a protected server environment:

- keeping the OpenAI credential off the pager;
- authenticating devices and accounts;
- translating provider events into Mochi's stable protocol;
- validating tool requests; and
- synchronizing opted-in history and configuration.

This resembles choosing between browser code and backend code. The analogy stops at the physical boundary: a browser cannot usually energize a microphone rail or continue emitting sound after its process crashes, but embedded hardware can do both unless the circuit and firmware are designed to fail safely.

### Trust boundary: model output is a proposal

The model may generate speech, an expression hint, or a request to use a tool. It is not allowed to decide whether the microphone is electrically enabled, whether the network is healthy, or whether a purchase should occur.

The gateway validates a proposed tool's name, input shape, user authorization, idempotency identifier, timeout, and result size. **Idempotency** means that retrying the same request does not repeat a side effect. This is the same rule used around payment or job-processing APIs: generated output is untrusted input until deterministic code accepts it.

### Persistence boundary: live context versus durable history

A live model session is **ephemeral**: it exists for the current connection and then disappears. Conversation history is **durable** only if Mochi deliberately stores it in its own service with user consent.

The pager may hold a small working context in memory during a session. The gateway and companion app handle opted-in durable records. Bluetooth setup does not become a hidden history channel. Keeping these roles separate makes deletion, account transfer, and offline behavior understandable.

### Electrical privacy boundary: software “mute” versus no capture

A user-visible “not listening” state must mean more than “the application promises not to upload samples.” A **capture gate** is an electronic switch that permits or blocks the microphone signal or power path. Mochi uses a hardware capture-enable command that defaults inactive before firmware starts. Reset, a crash, recovery, or a failed update must leave it inactive. The same command controls the visible listening indicator so the indicator and capture path cannot intentionally disagree.

The latching power switch is stronger still: **latching** means the switch mechanically remains in its chosen position. Its off position physically removes system power, including microphone power. This is a circuit property, not a user-interface animation.

> **Mochi product decision:** The shipping device has exactly two physical controls: one conversation start/stop button and one latching power switch. Power-on returns to private idle. It does not resume listening automatically. See [architecture decision record (ADR) 0008](../docs/decisions/0008_use_exactly_two_physical_controls.md).

## Model behavior as a state machine

A **state machine** describes a component using:

- a finite set of states;
- events that arrive while it is in a state;
- transitions caused by those events; and
- actions performed during a transition.

This is familiar from reducers, workflow engines, or a connection protocol. The important embedded difference is that some transition actions change physical outputs.

Mochi's top-level conversation state can begin simply. Writing each event next to its own transition avoids hiding which event causes which move:

```text
PRIVATE_IDLE
  └── button press ───────────────────────> CONNECTING

CONNECTING
  ├── session ready before deadline ──────> LIVE
  └── failure or timeout ─────────────────> PRIVATE_IDLE

LIVE
  └── button press or unsafe failure ─────> PRIVATE_IDLE

POWER_OFF
  └── physical switch on ──> boot ────────> PRIVATE_IDLE

any powered state
  └── physical switch off ────────────────> POWER_OFF
```

While `CONNECTING`, the face may immediately show that work started, but microphone capture remains closed. Capture opens only after device authentication and the live provider session are ready. The measured electrical and audio settling time then passes before the first microphone frame is sent.

Why not represent everything with one large enum such as `USER_TALKING` or `MOCHI_TALKING`? Because full-duplex conversation permits both at once. Inside `LIVE`, use independent state dimensions:

| Dimension | Possible states | Question answered |
|---|---|---|
| Input | `QUIET`, `USER_SPEAKING` | What is arriving from the microphone? |
| Output | `IDLE`, `GENERATING`, `PLAYING` | What is Mochi producing or playing? |
| Connection | `READY`, `RECONNECTING` | Can media safely reach the current session? |

`USER_SPEAKING + PLAYING` is valid for a short time when the user interrupts. Treating it as impossible creates bugs in interruption handling.

### Decide who owns each truth

Distributed systems become unreliable when two components believe they are authoritative for the same state. For Mochi:

| Truth | Authority |
|---|---|
| Physical power is on | Latching power circuit |
| Microphone capture is enabled | Device gate and local firmware |
| Samples have actually reached the speaker | Device playback cursor |
| Device/account is authenticated | Gateway |
| Model response exists | OpenAI live session, mediated by gateway |
| Durable history order | Mochi history service |
| Suggested emotional accent | Model or local mood system, below safety/activity state |

A **playback cursor** is a counter of samples actually rendered by the speaker path. Bytes downloaded or queued are not proof that the user heard them.

## Full duplex means two pipelines run at once

**Full duplex** means Mochi can capture input and play output simultaneously. It is like a video call, not like sending alternating voice messages.

Firmware usually expresses concurrent work as **tasks**: independently scheduled loops with narrow responsibilities. They are similar to operating-system threads or asynchronous workers, but they run with tighter memory and timing limits.

The audio paths look like this:

```text
CAPTURE
air -> microphone -> digital samples -> echo/noise processing
     -> bounded capture queue -> network upload

PLAYBACK
network download -> response-specific jitter queue -> decoder
     -> volume limiter -> speaker samples -> speaker -> air
                               |
                               └──> synchronized echo reference
```

A **queue** lets a producer and consumer run at slightly different moments. A **bounded queue** has a fixed maximum size. The bound matters because an unbounded queue can consume all memory or make a reply seconds late.

A **jitter queue** absorbs small variations in network arrival time. More queued audio reduces gaps but increases delay. “Add buffering” is therefore a trade-off, not a universal fix.

The **decoder** turns the received audio representation back into speaker samples. The **limiter** caps their maximum level. The synchronized echo reference is a time-aligned copy of those playback samples used to recognize Mochi's own sound in the microphone.

Media should not share one blocking loop with caption, configuration, or network-control work. If a configuration request stalls the microphone task, the result is not merely a slow API response; samples are permanently lost.

## Audio frames and control events are different data

An **audio frame** is a short block of samples. It is high-volume, ordered, and time-sensitive. A **control event** is a small structured message such as:

- session opened or closed;
- user speech started or stopped;
- response generation began;
- caption text arrived;
- response was interrupted at a playback position; or
- network health changed.

Separating media and control is similar to separating a video stream from its player commands. They can share one secure connection, but they need different queueing and retry rules. Retrying a configuration update may be safe; replaying old microphone audio after an outage is not.

Useful event fields include:

- `conversation_id`: which conversation owns the event;
- `session_epoch`: which connection attempt within that conversation;
- `input_segment_id`: which user utterance;
- `response_id`: which assistant response;
- `sequence`: ordering within one stream; and
- `device_timestamp`: when the device observed it.

These identifiers play the same role as trace identifiers and sequence numbers in backend services. They let us reject a late audio chunk from a canceled response rather than accidentally play it during the next response.

## Walk through one live conversation

Now we can expand the original button press without hiding the important boundaries:

1. The device **debounces** the button, meaning it turns several rapid electrical transitions from one physical press into one software event.
2. Firmware enters `CONNECTING` and updates the face locally. The capture gate remains inactive.
3. The device authenticates to Mochi's gateway over an encrypted connection. The gateway establishes the OpenAI live session.
4. When both sessions are ready, firmware enables the coupled capture-and-indicator signal. After the hardware settles, microphone frames begin flowing.
5. OpenAI detects speech boundaries and returns generated audio. The gateway tags each response and streams it to the pager.
6. The device buffers a small amount, plays the audio, advances the playback cursor, and scrolls transcript text as a caption. It also gives a copy of the played samples to acoustic echo cancellation, processing that removes Mochi's own speaker sound from its microphone input.
7. If local post-cancellation voice detection sees the user during playback, the device stops the current response immediately. It records the heard playback position and removes unheard caption text. The gateway cancels the generation and rejects late chunks.
8. Capture remains active for the correction. The user does not press again between utterances.
9. The next conversation-button press closes capture first, cancels active work, clears queued output, and returns to `PRIVATE_IDLE`.

As introduced above, the **gateway** is Mochi's Internet-facing backend. It protects service credentials, authenticates clients, applies product policy, and adapts provider-specific messages. The pager talks to the gateway instead of embedding a valuable provider credential in firmware.

## Latency is a sum, not one mystery number

**Latency** is elapsed time between a cause and a visible or audible effect. Different interactions have different latency budgets.

The button should feel immediate because the face update is local. A spoken reply must cross several boundaries:

```text
speech-end-to-reply = speech-end detection
                    + device and gateway handling
                    + model first-audio generation
                    + downlink travel
                    + playback buffering
```

**Downlink** means network data traveling toward the pager; **uplink** means data traveling from the pager toward the service.

Interruption has another budget:

```text
speech-onset-to-stop = local voice detection after echo cancellation
                     + audio-task scheduling
                     + queued Direct Memory Access (DMA) playback clear
```

Do not measure only “request duration.” Timestamp each phase and attach the identifiers from the previous section. Device and server clocks are not automatically identical, so prefer durations whose start and end use the same clock. If clocks are synchronized, record the expected synchronization error as part of the measurement.

> **Mochi product decision:** The local face acknowledges a conversation-button press within 100 milliseconds. During a recoverable live connection failure, capture closes immediately. A single non-extendable 10-second deadline allows authenticated reconnection; after that, live intent is cleared and another press is required. These are requirements to verify, not universal IoT constants.

## Connectivity and setup are separate from conversation

**Bluetooth Low Energy (BLE)** is a short-range radio protocol designed for low-power devices. **Wi-Fi** provides the pager's normal Internet route. A future **Long-Term Evolution (LTE)** modem could provide fourth-generation cellular fallback.

On first setup, the phone sends Wi-Fi credentials to the nearby pager using Espressif's authenticated `protocomm Security 2` setup protocol over BLE. The pager stores private network credentials in its protected local credential store. The app does not persist custom Wi-Fi passwords or cellular authentication secrets, and Mochi's cloud does not need them.

After setup, BLE shuts down. Live audio and history use their authenticated Internet services instead. This reduces the number of protocols that can access sensitive content.

Changing from Wi-Fi to cellular is not like changing a local variable. The old network connection is no longer valid. The device must close capture, discard uncommitted input and stale output, choose a route, perform name resolution—turning a service name into a network address—set up encryption, and authenticate again. It then reconstructs only committed context. It must never record speech during the gap for later automatic upload.

> **Mochi product decision:** A factory-fresh pager may advertise setup automatically while capture remains closed. An already-owned pager requires an authorized, time-limited setup window or the documented boot-time **recovery chord**, a physical button-and-power gesture recognized only during startup. BLE setup cannot transfer ownership or reveal old history. See [ADR 0007](../docs/decisions/0007_use_companion_app_and_cloud_history_sync.md).

## Durable synchronization is its own distributed system

The companion app and pager are two clients of Mochi's gateway. The gateway gives accepted configuration changes a revision number and durable history events a server sequence. A client asks for events after its last **cursor**, which is a token marking its synchronization position.

Retries can deliver the same source event more than once, so the service deduplicates it before assigning a durable identifier. Deletion is synchronized with a content-free **tombstone**: a record saying an item was deleted without retaining its deleted content. A client whose cursor is too old performs a complete authenticated reconciliation: it downloads and compares the current authorized state instead of trusting an incomplete event range.

This is intentionally more like database replication than Bluetooth file copying. The pager remains authoritative for physical capture and playback; the cloud remains authoritative for durable record ordering.

## Failure behavior is part of the architecture

For each component, ask: “If this stops responding now, what state is still truthful?”

| Failure | Safe, understandable behavior |
|---|---|
| Network or live session disappears | Close capture, discard uncommitted input and stale output, show reconnecting, then require a new press if the deadline expires |
| Echo cancellation becomes unreliable | End the live session and return to private idle rather than pretending full duplex still works |
| Provider stalls | Cancel on timeout and restore a usable local state |
| Authentication is rejected | Stop aggressive retries and enter a service/setup state |
| Speaker queue runs dry | Record the underflow, recover playback, and keep buttons responsive |
| History or tool service fails | Continue the conversation without that optional capability |
| Firmware update fails | Boot a previously verified image with capture inactive |

The face is an operational signal. Honest offline or reconnecting eyes are better than a cheerful frozen face.

## Names used in the design documents

Other Mochi documents group the responsibilities above into five **planes**. A plane is a conceptual category, not necessarily a process, task, server, or circuit:

| Plane | Responsibilities already introduced |
|---|---|
| Interaction | Button semantics, face, caption, local user-visible state |
| Media | Timed microphone and speaker frames, buffers, playback cursor |
| Control | Versioned session, speech, caption, interruption, and health events |
| Connectivity | BLE setup, Wi-Fi/cellular routes, reconnect behavior |
| Service | Gateway authentication, provider adapter, tools, configuration, durable history |

Starting with the end-to-end flow makes these names useful labels instead of abstract boxes.

## Applying this architecture to the prototype

Do not test every unknown at once. Here a **mule** is an intentionally rough prototype that isolates one risky subsystem, and a **carrier board** is a custom circuit board that mechanically and electrically connects prebuilt modules:

- The interaction mule tests the button, eyes, caption, capture truth, and full-duplex audio over Wi-Fi.
- A desktop client tests gateway events and OpenAI integration before constrained embedded hardware is involved.
- The companion-app slice tests secure BLE setup, account binding, configuration revisions, and cursor-based history synchronization.
- The cellular mule later tests route changes, antenna behavior, peak power, latency, and data use.
- A custom carrier board tests the final power, connector, acoustic, and mechanical integration.

This is the hardware equivalent of testing a database adapter, application programming interface (API), and user interface independently before one large integration test.

## Self-check

Try to answer these before opening the answers:

1. Why must the face react to the conversation button before the cloud responds?
2. Why are `USER_SPEAKING` and `PLAYING` not mutually exclusive?
3. Which component is authoritative for how much assistant audio the user actually heard?
4. Why should old microphone frames be discarded rather than retried after reconnection?
5. What is the difference between a live model session and durable Mochi history?
6. Why can the model suggest an eye expression but not enable microphone capture?

<details>
<summary>Answers</summary>

1. Local feedback stays responsive even when the network is slow or unavailable, and it truthfully reports the device's own transition.
2. Full duplex allows the user to interrupt while assistant audio is still playing.
3. The device's playback cursor, because it counts samples rendered rather than downloaded.
4. Retrying stale speech can violate privacy, confuse ordering, and cause the model to act on words spoken during an outage.
5. The live session is temporary provider state; durable history is an explicit, consented Mochi service record.
6. Capture is a privacy and hardware state governed by deterministic local policy; model output is untrusted input.

</details>

Continue with [0002 — Modules, pins, buses, and real-time audio](0002_modules_buses_and_audio.md). For the formal product decisions, see [ADR 0003](../docs/decisions/0003_use_secure_realtime_gateway.md), [ADR 0006](../docs/decisions/0006_use_button_started_full_duplex_sessions.md), the [companion-app and synchronization architecture](../docs/design/0002_companion_app_and_sync_architecture.md), and the [minimum viable product (MVP) requirements](../docs/requirements/0001_mvp_requirements.md).

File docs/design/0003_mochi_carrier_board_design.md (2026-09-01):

# Mochi R0 carrier — modular pager companion reference design

Status: Reference design only — **not released for fabrication**
Date: 2026-09-01
KiCad project: [`hardware/mochi/`](../../hardware/mochi/)

## 1. Outcome

The safest first custom Mochi board is a **58 × 82 mm, four-layer modular carrier**. It
integrates the ESP32-S3, charging, switched power, microphone, speaker amplifier,
display connector, controls, and test access. North-American cellular is a removable
**MIKROE-6396 4G LTE 3 Click** on the back of the carrier, not a raw LGA modem.

This keeps the first board debuggable and agrees with
[ADR 0005](../decisions/0005_build_modular_carrier_before_integrated_rf.md). It also
keeps a Wi-Fi-only build valid. The raw-radio integration proposed earlier is deferred
until a cellular mule, antenna, enclosure, and US compliance plan pass their gates.

The checked-in KiCad files are useful now for electrical review, firmware pin contracts,
mechanical stacking, and purchasing experiments. They are deliberately a **module-level
schematic and unrouted placement study**. Generated footprints, regulator support
passives, stack-up-specific routing, and antenna/enclosure work are not production
released. Sending this directory to a PCB factory would be a category error.

### Recommended configurations

| Configuration | Populate | Use |
|---|---|---|
| **A — Wi-Fi/BLE first** | Everything except J3, U2, U15, J6, D3, R11 | First power, USB, display, audio, privacy, and AEC bring-up |
| **B — North-America LTE EVT** | A plus MIKROE-6396 at J3; its logic jumper at 3.3 V | AT&T/Verizon lab and field experiments after power tests |
| **C — camera experiment** | DNP U15/J6/D3/R11 plus a reviewed adapter | Future still images only; prohibited in the MVP by PR-06 |
| **D — Type-C current detection** | U2 fitted and R1/R2 removed | Later engineering option; not verified in R0 |

Configuration B has one mandatory daughterboard ECO: **remove the MIKROE-6396's D3
(Click USB VBUS to regulator-input diode), then verify it is open circuit**. The Click's
USB-C connector must not be exposed in the enclosure. This prevents a second USB cable
from energizing the modem while Mochi's power slide is off.

## 2. System architecture

```text
                    Mochi USB-C
                 5 V power + USB 2
                          │
                 ESD / TVS protection
                          │
           ┌──────────────┴───────────────┐
           │ BQ25628E charger + NVDC path │
           └────────┬───────────┬─────────┘
                    │ BAT       │ SYS_ALWAYS
     protected 1S 1500 mAh      ├── MAX17055 fuel gauge
          pack + NTC             │
                                SW1 latching slide
                                  │ PWR_SW_ON
                 ┌────────────────┴────────────────┐
                 │                                 │
        TPS22992S load switch             TPS61236P 5 V boost
                 │ SYS_SW                          │ LTE_5V_RAW
        TPS63802 3.3 V buck-boost         TPS2001E limit/gate
                 │ 3V3                             │ CELL_5V
       ┌─────────┼───────────┐                     │
       │         │           │               MIKROE-6396
 ESP32-S3    touch LCD   audio/privacy        LEXI-R10401D
 Wi-Fi/BLE                               Cat 1bis + SIM + U.FL
       │                                      │
       └──────── 3 Mbaud UART + RTS/CTS ──────┘
```

The board has two radio systems with different jobs:

- The **ESP32-S3-WROOM-1-N16R8** supplies compute, 2.4 GHz Wi-Fi, and Bluetooth LE.
- The **LEXI-R10401D on MIKROE-6396** supplies LTE data and SMS. It does not replace
  ESP Wi-Fi, and its Wi-Fi scan capability is positioning assistance rather than a Wi-Fi
  data link. This design does not claim native phone calls, VoLTE, or GNSS.

Wi-Fi is preferred; LTE is failover. Firmware should avoid simultaneous maximum Wi-Fi
transmit, LTE transmit, full-volume playback, and battery charging because the small pack
has limited current and thermal margin.

## 3. Why these parts

| Function | Baseline part | Reason and tradeoff |
|---|---|---|
| Compute/Wi-Fi/BLE | [ESP32-S3-WROOM-1-N16R8](https://www.espressif.com/sites/default/files/documentation/esp32-s3-wroom-1_wroom-1u_datasheet_en.pdf) | Module reduces RF-layout risk; 16 MB flash and 8 MB octal PSRAM support assets, networking, and audio buffers. It is not a Linux computer: local large-model inference is out of scope. |
| US cellular | [MIKROE-6396](https://www.mikroe.com/4g-lte-3-click-for-north-america) | Replaceable Cat 1bis daughterboard with LEXI-R10401D, SIM, logic translation, 3.8 V regulator, bulk capacitance, U.FL, and recovery USB. It costs thickness and board area but removes raw-LGA, SIM, RF-trace, and 1.8 V translator risk from Rev A. |
| Charger/power path | [BQ25628E](https://www.ti.com/product/BQ25628E) | Current 1-cell, 2 A NVDC charger with input limiting, NTC support, ADC, and I²C. R0 remains conservative at 500 mA USB input and no more than 1.0 A battery charge. |
| Main 3.3 V | [TPS63802](https://www.ti.com/product/TPS63802) | Buck-boost keeps 3.3 V while a 1S pack moves above and below 3.3 V. Its real output capability and thermal margin depend on input voltage, inductor, layout, and load—not the headline current alone. |
| LTE 5 V | [TPS61236P](https://www.ti.com/product/TPS61236P) + [TPS2001E](https://www.ti.com/product/TPS2001E) | Dedicated boost gives regulated 5 V in battery and USB modes, true disconnect, soft-start/current limiting, reverse blocking, discharge, and fault reporting. It is less compact than reusing a charger boost node but has much clearer handoff behavior. |
| Fuel gauge | [MAX17055](https://www.analog.com/en/products/MAX17055.html) + 10 mΩ Kelvin shunt | Counts current and estimates time/age. Its low-side sense polarity is `CSP = pack negative`, `CSN = system ground`; reversing those silently reverses current sign. |
| Microphone | [IM69D129F](https://www.infineon.com/part/IM69D129F) | Small, high-SNR PDM microphone with a bottom acoustic port. It avoids an analog codec but makes PCB/enclosure port geometry important. |
| Playback | [MAX98357A](https://www.analog.com/en/products/max98357a.html) | I²S-input mono class-D amplifier; no codec control bus or MCLK needed. Its output is bridge-tied: neither speaker lead is ground. |
| Speaker | [PUI AS01808AO-SC18-WP-R](https://puiaudio.com/file/specs-AS01808AO-SC18-WP-R.pdf) | 18 × 13 × 2.5 mm, 8 Ω, 1 W, spring-contact part. Plan roughly a 1 cm³ sealed rear chamber and validate the final gasket/vent. |
| Display/touch | [Waveshare SKU 27057](https://www.waveshare.com/wiki/1.69inch_Touch_LCD_Module) | 1.69-inch, 240 × 280 ST7789V2 SPI LCD with CST816S/T I²C touch. At about 33.13 × 41.13 mm, it is a realistic face/display module for this enclosure. |
| EVT battery | [BatterySpace CU-J450-V3](https://www.batteryspace.com/Polymer-Li-Ion-battery-3.7V-1500mAh-5.55Wh-3A-rate-703562-2C-2.aspx) | Protected 1S, 1500 mAh/5.55 Wh, nominally 68 × 35 × 7.5 mm, 10 kΩ NTC, 1.4 A max charge, 3 A max discharge. It is an EVT source, not yet production-qualified. |

The pack uses housing `5023510300`: pin 1 `PACK+`, pin 2 `NTC`, pin 3 `PACK−`.
The carrier uses the right-angle [Molex 5023520300](https://www.molex.com/en-us/products/part-detail/5023520300)
mate. Obtain the exact assembled-pack UN 38.3 test summary, IEC 62133-2 evidence,
protection thresholds/delays, full NTC curve, traceability, and change-notification terms
before DVT.

## 4. Power and true-off behavior

### 4.1 USB and charging

Two 5.1 kΩ `Rd` resistors make J1 a basic Type-C sink. They do not magically grant a
particular current. R0 therefore fixes the charger's hardware input limit at a conservative
500 mA until firmware and source detection are proven. The BQ25628E charge current must
be programmed to **≤ 1.0 A**, below the selected pack's 1.4 A maximum.

U2, a TUSB320LAI current-advertisement detector, is DNP. If it is later used, R1/R2 are
removed because the controller supplies the Type-C termination. That option needs a
reviewed truth table plus a safe hardware fallback if firmware is absent.

USB D+/D− go only to the ESP32-S3 native USB pins through TPD4E05U06 ESD protection and
a TS3USB3000 switch. For normal operation the switch has `SEL=0`, `OE=0`; when its 3.3 V
supply disappears its `Ioff` behavior makes every data path high impedance. Charger
D+/D− detection is not shared with this port.

### 4.2 The power slide

SW1 does not carry every ampere. It applies `SYS_ALWAYS` to `PWR_SW_ON`, which enables
the main load switch, 3.3 V converter, LTE boost, and LTE current-limit switch. A 100 kΩ
pull-down makes the default off.

With SW1 off, `SYS_SW`, `3V3`, `MIC_3V3`, `LTE_5V_RAW`, `CELL_5V`, and `CAM_3V3` are
dead. The BQ25628E power path and the MAX17055 remain attached to the pack intentionally;
“off” means that the system and sensors are electrically isolated, not zero battery
current. Bench tests must try to back-power the board from all USB ports, debug pads, and
the modem socket.

R0 cuts LTE immediately. That is private and deterministic, but it gives the modem no
graceful network/power-down interval. A production revision may add a hardware off
sequencer with a bounded timeout; it must never turn “off” into an indefinitely
firmware-controlled promise.

### 4.3 LTE current budget

The current LEXI-R10 data sheet reports about **540 mA typical and 900 mA maximum averaged
over connected LTE data Tx/Rx at maximum transmit power** on the module's 3.8 V rail.
Those are not described as microsecond “peaks.” The integration guidance asks for at least
twice typical current, or 1.08 A, at the modem supply. R0 targets 1.5 A on `CELL_5V` to
cover the Click regulator, bulk-capacitor charging, cable/copper loss, and uncertainty.

At low state of charge, an illustrative LTE-only pack current is:

```text
5.0 V × 1.1 A / (0.93 boost efficiency × 3.3 V pack) ≈ 1.79 A
```

Adding ESP32, display, audio, and conversion loss makes **2.6–2.9 A plausible**, nearly
the selected pack's 3 A protection rating. This arithmetic says “EVT may be possible,”
not “the power design works.” Cold and aged cells, connector resistance, load steps,
boost start-up, and thermal limits must be measured. Firmware needs load shedding.

The earlier idea of feeding LTE from a BQ25895 `PMID` node is rejected for R0. With USB
present, PMID can follow an input whose automated charger negotiation may exceed 5 V;
battery OTG also has a handoff delay. A dedicated boost avoids putting a possible 9/12 V
node on a 5 V Click board.

## 5. Cellular connection, pin by pin

The [MIKROE schematic](https://download.mikroe.com/documents/add-on-boards/click/4g-lte-3-click-north-america/4g-lte-3-click-schematic.pdf)
shows an easy-to-miss naming convention: the physical mikroBUS `TX` pin carries data
*from* the Click to the host, and physical `RX` carries data *to* the Click. The carrier
therefore crosses TX/RX but not RTS/CTS names:

| ESP32-S3 | Carrier net | J3 physical pin | Direction/purpose |
|---|---|---|---|
| IO41 UART TX | `LTE_TX` | `RX` | ESP → Click → module RXD |
| IO42 UART RX | `LTE_RX` | `TX` | module TXD → Click → ESP |
| IO1 UART RTS | `LTE_RTS` | `RTS/CS` | ESP output → module RTS input |
| IO2 UART CTS | `LTE_CTS` | `CTS/INT` | module CTS output → ESP input |
| IO38 | `LTE_RI` | `RI/PWM` | ring/URC indication → ESP |
| TCA9534 P2 | `LTE_PWR_PULSE` | `PWR/AN` | active-high host command; Click transistor pulls module `PWR_ON` low |
| TCA9534 P3 | `LTE_RESET` | `RESET` | reset control; confirm inactive default at bring-up |
| U8 output | `CELL_5V` | `5V` | modem power through the Click's 3.8 V LDO |
| 3.3 V | `3V3` | `3V3` | Click TXB0106 host-side logic only; set JP1 to 3.3 V |

The `RTS/CS` signal is shared with ClickID access. Firmware must never talk to ClickID
while modem hardware flow control is active.

LEXI-R10 supports up to 3 Mbaud. With 8N1 framing, `3,000,000 × 8/10 = 2.4 Mbit/s` of
payload in each full-duplex direction before PPP/AT/socket overhead. That is ample on
paper for 20–64 kbit/s Opus audio, but it is below the radio's advertised 10.3 Mbit/s
downlink. Stress-test the exact firmware path with RTS/CTS, encrypted sockets, display,
AEC, and reconnects; do not infer full Cat 1bis throughput from the radio badge.

## 6. Audio and capture truth

```text
IO40 CAPTURE_EN ─┬─ 100 kΩ pull-down
                 └─ TPS22918 ── MIC_3V3 ─┬─ IM69D129F microphone
                                         ├─ SN74LVC2G125 PDM isolation
                                         └─ cyan LED + resistor

ESP I2S rendered PCM ── MAX98357A ── OUTP/OUTN ── 8 Ω speaker
             └──────── same post-volume/post-mute PCM ── AEC reference
```

`CAPTURE_EN` is a direct ESP pin with a hardware pull-down. When it is inactive, the mic
has no power and the PDM clock/data paths are isolated. The cyan LED is powered from the
downstream `MIC_3V3` rail, so firmware cannot turn on the mic without also energizing the
indicator or command the indicator independently.

That is a strong **electrical truth coupling**, not a malware-proof privacy switch: hostile
firmware could assert both, and component faults can disagree. The latching power slide is
the certain physical privacy control. Fault-injection tests still need to cover open LED,
shorted load switch, stuck GPIO, boot, crash, watchdog, recovery, and OTA.

The AEC reference is the rendered digital stream **after software volume, mute, and
cancellation decisions**. Do not connect an ADC divider casually to MAX98357A's class-D
speaker outputs: both leads switch and neither is ground. A digital reference misses some
amplifier/speaker nonlinearity, so final enclosure work must prove echo-return loss,
double-talk, barge-in, clock alignment, and acoustic isolation. If it fails, choose a
synchronized codec/reference design from measurements rather than asserting that a
post-class-D tap is automatically better.

## 7. Display, controls, camera, and buses

Mochi exposes exactly two exterior controls:

- SW1: latching power slide.
- SW2: active-low conversation button on IO39 with a pull-up.

The display shares SPI clock/MOSI with the DNP auxiliary camera connector. Each device has
its own chip select. Touch, charger, gauge, and the slow GPIO expander share I²C:

| Device | Address |
|---|---:|
| BQ25628E | `0x6A` |
| MAX17055 | `0x36` |
| TCA9534A | `0x20` |
| CST816 touch | likely `0x15`; confirm the exact populated S/T variant |

TCA9534 P0/P1 are fault inputs; P2/P3 command modem power/reset; P4/P5 reset LCD/touch;
P6 drives the amber session-intent indicator; P7 enables the DNP camera rail. Fast modem
UART/flow-control, PDM, I²S, touch IRQ, conversation, and privacy signals stay on direct
ESP GPIO.

The optional J6 connector is only a **generic SPI/I²C experiment contract**. No camera
sensor or production pinout is selected. A module requires its own adapter review and a
white indicator powered from the downstream camera rail. The common Arducam M0031 OV2640
is a 24-pin DVP camera consuming roughly twelve GPIO and is not directly compatible with
J6. Camera absence remains the production/MVP decision.

The complete GPIO assignment is generated in
[`hardware/mochi/doc/pin_map.csv`](../../hardware/mochi/doc/pin_map.csv). IO35–37 are
unused because N16R8's octal PSRAM consumes them. IO3/45/46 are avoided as strapping pins;
IO0 reaches only a pulled-up fixture test net. Native USB remains on IO19/20.

## 8. Mechanical and RF layout plan

The 58 × 82 mm carrier fits the maximum 95 × 60 × 30 mm product envelope. It does not yet
prove the 80 × 56 × 26 mm stretch target. The 57.15 × 25.4 mm Click, 68 × 35 × 7.5 mm
battery, display, speaker chamber, connectors, antenna cable, and fasteners form a stacked
mechanical system that is likely to consume most of the 30 mm height.

Four layers should ultimately be used as:

1. top: components and short critical signals;
2. inner 1: uninterrupted ground reference;
3. inner 2: power distribution, with controlled breaks only after return-path review;
4. bottom: LTE daughterboard/socket and low-risk routing.

The checked-in PCB has a no-copper keepout on all four layers under the ESP module antenna
and places it at a board edge. The final design also needs the exact Espressif land pattern,
edge/antenna clearance, stitching vias, USB 90 Ω differential routing, short switcher
loops, Kelvin shunt routing, a clean bottom-port microphone opening, and a gasketed speaker
chamber. None is released in R0.

For LTE EVT, use the Click's U.FL and start with a known external antenna covering 617 MHz.
The [Taoglas FXUB16](https://www.taoglas.com/product/fxub616-wideband-cellular-flex-pcb-antenna-617-6000mhz-with-90-feed-black-150mm-1-37-cable-and-i-pex-mhf1/)
covers 617–6000 MHz but its roughly 90 × 15 mm flex is mechanically awkward. The compact
[PCS.55.A](https://www.taoglas.com/product/pcs-55-a-small-fr4-wideband-4g-lte-antenna/)
is easier to package but its published low-band efficiency is weak; it is a measurement
candidate, not a verified choice. The final antenna must be tuned in the real plastic,
next to the battery/display/speaker and a hand/body, then tested for VNA match, TRP/TIS,
Wi-Fi/LTE desense, coexistence, and SAR.

## 9. US network and certification reality

The current MIKROE/LEXI configuration covers LTE bands 2, 4, 5, 12, 13, 14, 66, and 71,
which is a much better North-American starting set than many small global modules. Public
sources show module-level AT&T/FirstNet and Verizon work, including a
[Verizon Open Development listing](https://opendevelopment.verizonwireless.com/design-and-build/approved-modules/module/32280).
Freeze the exact LEXI order code, hardware revision, firmware, TAC, FCC identifier, and
carrier applicability in writing before buying a lot. A current public, exact T-Mobile
approval for this module was not located, so T-Mobile remains unverified rather than
assumed.

Most importantly, **module approval is not finished-product approval**. The LEXI modular
grant/integration conditions are for mobile/fixed separation and a certified antenna/feed
implementation. A pocket/body-worn pager plus a Click, U.FL cable, internal antenna,
four-layer host, Wi-Fi transmitter, and new enclosure changes the RF exposure and
simultaneous-transmitter case. Plan for:

- FCC intentional-radiator integration review, host Part 15B, labeling/manual language,
  permissive-change or new certification path, and portable-device SAR;
- PTCRB device certification and each target carrier's device/onboarding process;
- simultaneous LTE + Wi-Fi/Bluetooth transmitter evaluation and coexistence;
- Bluetooth SIG qualification/declaration;
- battery transport/safety evidence and charger/system safety review.

Use the FCC's [KDB 996369 module guidance](https://apps.fcc.gov/oetcf/kdb/forms/FTSSearchResultPage.cfm?id=44637&switch=P),
[KDB 447498 RF-exposure guidance](https://apps.fcc.gov/oetcf/kdb/forms/FTSSearchResultPage.cfm?id=20676&switch=P),
[PTCRB certification process](https://www.ptcrb.com/get-certified/),
[AT&T IoT device process](https://iotdevices.att.com/iot-accelerator.aspx), and
[Verizon certification process](https://opendevelopment.verizonwireless.com/get-certified)
with an accredited lab early. These are design inputs, not paperwork to add after routing.

LEXI-R10401D also lacks band 25 and is not a basis for claiming current T-Mobile/Starlink
Direct-to-Cell compatibility. Any satellite feature needs explicit module, firmware, SIM,
plan, carrier, and certification evidence.

## 10. Alternatives researched

| Alternative | What it improves | Why not R0 |
|---|---|---|
| Raw LEXI-R10401D | Smallest eventual board, exact band set | Reintroduces 1.8 V translation, SIM/ESD, RF feed, transient supply, assembly, antenna-equivalence, and certification risk simultaneously. Revisit after Gate D. |
| [Telit LE310Q1-SN](https://www.telit.com/devices/le310q1/) | Compact 15 × 18 mm Cat 1bis second-source candidate | Not footprint/firmware/certification drop-in; public power and exact carrier evidence need a fresh freeze review. |
| [Quectel EG800Q-NA](https://www.quectel.com/product/lte-standard-eg800q-series/) | Widely supported Cat 1bis family | North-American variant lacks bands 14 and 71; heavier source requirement. |
| [SIMCom SIM7672G](https://www.simcom.com/product/SIM7672G.html) | Global Cat 1bis alternative | Larger and the public band set lacks 14/71 for this baseline. |
| LTE-M module | Lower average power and potentially GNSS | Half-duplex radio scheduling, latency, sustained session behavior, and carrier plan must be field-proven against full-duplex interaction. It is not rejected on bitrate arithmetic alone. |
| Cat 4 module | Mature broadband and USB | More power, area, and usually a second antenna; unnecessary for compressed conversational audio. |

## 11. Updates to the earlier proposal

The earlier Claude research made several durable contributions: choose Cat 1bis rather
than Cat 4, reserve octal-PSRAM GPIO, use four layers, keep hardware flow control, make
power integrity and certification first-class, and preserve a real capture indicator.
R0 changes the implementation where later evidence exposed risk:

- raw LEXI integration → removable MIKROE-6396 for the first carrier;
- battery-direct modem rail → isolated, regulated 5 V Click rail;
- “900 mA peak” → 900 mA maximum **averaged connected LTE data current**;
- modem-side 1.8 V translators → the Click's validated onboard TXB0106;
- analog post-class-D AEC tap → known rendered digital PCM reference;
- 1.28-inch round display → exact 1.69-inch touch module;
- assumed SPI camera → DNP generic connector, no MVP sensor;
- vague small LiPo → exact protected 1500 mAh EVT pack and mating connector;
- inherited module certification → explicit portable-device US certification program.

[ADR 0011](../decisions/0011_integrate_lexi_r10401d_on_four_layer_carrier.md)
records why the integrated proposal was rejected for Rev A; [ADR 0012](../decisions/0012_use_modular_north_american_cat1bis_click_for_rev_a.md)
records the modular choice.

## 12. What has actually been verified

| Check | Result | Meaning |
|---|---|---|
| Deterministic contract check | 54 pass, 2 expected warnings, 0 fail | BOM/manifest/net parity, exact LTE directions, hard-off topology, MAX17055 polarity, capture coupling, GPIO/address budgets, current/throughput arithmetic |
| KiCad schematic ERC | 0 violations | KiCad parses the schematic and sees no rule violation at this module-level abstraction |
| KiCad PCB DRC | Expected `unconnected_items` and one generated-library mismatch only | Placement geometry has no additional detected error; the board is intentionally unrouted and reference footprints are unreleased |
| Four-layer/outline/keepout audit | 58 × 82 × 1.6 mm, four copper layers, four ESP antenna keepouts | The generated placement contract matches the document |
| Primary-source review | Current vendor data, Click schematic, carrier/FCC processes checked 2026-09-01 | Selected interfaces and risks are traceable; commercial approvals still need written confirmation |

Reproduce the desk checks with:

```bash
node tools/hardware/generate_mochi_reference.js
python3 tools/hardware/check_carrier_design.py
```

The check intentionally returns success while warning that PCB DRC is non-zero for
unrouted nets. It would be misleading to suppress those opens or call the board DRC-clean.

No physical PCB exists, so the configuration is **not verified to work in hardware**.
Before fabrication release, all of the following remain blocking:

1. complete vendor-reference inductors, feedback/limit networks, bypassing, ESD, pull-ups,
   exact production symbols/footprints, and derating calculations;
2. obtain the exact Click, modem, display, pack, speaker, switches, and connector samples;
3. continuity/back-power matrix with battery, Mochi USB, Click USB, and debug fixture;
4. 3.0–4.35 V battery emulator plus 500 mA/1.5 A/3 A USB source tests, LTE load steps,
   inrush, charger/boost stability, cold/low-SOC sag, and thermal soak;
5. Wi-Fi-only full-duplex audio/AEC/barge-in and privacy fault-injection gates;
6. modem attach, SIM/APN, PPP/socket, 3 Mbaud RTS/CTS, recovery, handoff, and reconnect;
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

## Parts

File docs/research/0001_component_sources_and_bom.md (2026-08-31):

# 0001 — Component sources, staged BOM, and online tests

Status: Purchase research complete; prices and stock must be rechecked at checkout  
Observed: 2026-08-30  
Working checkout assumption: United States, inferred only from the workspace timezone. Confirm the actual test country, carriers, and future markets before Gate B; the North American production options below are exploratory.

## Purchase summary

### Buy now — Gate A

| Qty | Item | Observed price | Source | Why now |
|---:|---|---:|---|---|
| 1 | M5Stack CoreS3, K128 — **purchased 2026-08-31, $77.90** | $59.90 list | [Amazon, M5Stack Official Store](https://www.amazon.com/M5Stack-CoreS3-ESP32S3-IoT-Develpment/dp/B0C7G5GPGC) (bought); [DigiKey K128](https://www.digikey.com/en/products/detail/m5stack-technology-co-ltd/K128/18839257) at list | Integrated screen, touch, dual microphones, speaker/amp, synchronized speaker-feedback input, battery, microSD, Wi-Fi/BLE, IMU, and ESP32-S3 let us validate the concurrent interaction/audio path without breadboard noise. The full K128 was chosen over the K128-LITE for its 500 mAh cell (vs 200 mAh) and additional expansion; see the [ADR 0001 amendment](../decisions/0001_use_esp32s3_interaction_mule.md). |
| 1 | Known-good USB-C data cable | $5–10 | Existing cable or reputable local supplier | Power-only cables cause misleading flash/debug failures. |

The CoreS3 family shares one design (M5Stack publishes a single `Sch_M5_CoreS3_v1.0.pdf` schematic across it): a 2-inch 320 × 240 capacitive display, 16 MB flash, 8 MB PSRAM, two microphones, I²S audio, a 1 W speaker, Wi-Fi, BLE, GC0308 camera, BMI270 IMU, and AXP2101 PMIC. The Lite (K128-LITE, 54 × 54 × 16.5 mm) carries a 200 mAh cell and a magnetic backplate; the full K128 carries a 500 mAh cell and M5Stack's base module. The audio subsystem — the part this project actually depends on — is identical. M5Stack describes its ES7210/AW88298 path as a [full-duplex audio solution](https://docs.m5stack.com/en/core/CoreS3-Lite), and its [reference implementation](https://github.com/m5stack/StackChan/blob/main/firmware/main/hal/board/cores3_audio_codec.cc) opens simultaneous receive/transmit and selects the ES7210 MIC3 reference lane. Those facts justify an early AEC experiment; they do not prove usable double-talk in Mochi's enclosure. The internal cell is for untethered demonstrations, not evidence for final runtime.

Do **not** add a separate display, audio board, final battery, custom PCB, GPS board, or 5G modem to this order.

### Buy only after the CoreS3 concurrent-audio baseline — Gate A acoustic/privacy mule

If Day 8 verifies simultaneous I²S receive/transmit, the MIC3 reference lane, and enough resource headroom, order one compatible relocatable digital microphone, I²S amplifier, 8-ohm speaker, illuminated conversation control, a switched-microphone gate with state-coupled indicator (bench instrumentation for capture-gate/fault-injection measurements per [ADR 0008](../decisions/0008_use_exactly_two_physical_controls.md) — not a product control), and safe prototyping interconnect. The current target is $20–40 plus shipping. Recheck pins, voltage, clocks, reference strategy, capture-gate/indicator topology, stock, and landed price before purchase; take a shipping pause rather than advancing to the cellular gate without this evidence.

### Buy after the Wi-Fi full-duplex voice gate — Gate B

| Qty | Item | Observed price | Source | Purchase condition |
|---:|---|---:|---|---|
| 1 | SIM7600G-H 4G HAT, 56.21 × 65.15 mm | $97.99 | [Waveshare](https://www.waveshare.com/product/iot-communication/sim7600g-h-4g-hat.htm) | End-to-end Wi-Fi full-duplex voice passes its acoustic/privacy/stability gate and region/model compatibility is checked. This is an external bench mule, not an enclosure board. The listed package includes one LTE MAIN antenna and one GNSS antenna; its AUX/diversity connector needs a separate compatible LTE antenna. |
| 1 | Compatible LTE AUX/diversity antenna | Live quote required | Confirm connector, bands, gain, cable, and approval with Waveshare/seller | Cat 4 evaluation should use the vendor-recommended MAIN plus diversity receive configuration rather than treating the included GNSS antenna as a second LTE antenna. |
| 1 | **One** SIM/service path: Soracom plan-US **or** a direct-carrier SIM/plan | Soracom physical SIM $5 plus usage; T-Mobile prepaid data-only $20/month for 5 GB or $30/month for 10 GB plus a one-time $25/line connection charge; AT&T prepaid data-only from $35/month (15 GB); Verizon from $40/month (5 GB); T-Mobile-network MVNOs from about $10–15/month (observed 2026-08-31) | [Soracom plan-US](https://store.soracom.io/product/soracom-plan-us-iot-ecosim-card/), [carrier/plan coverage](https://developers.soracom.io/en/docs/reference/carriers/), [T-Mobile](https://prepaid.t-mobile.com/prepaid-internet), [AT&T](https://www.att.com/prepaid/mobile-hotspot-tablet/), or [Verizon](https://www.verizon.com/prepaid/plans/data-only-plans/) | These are alternatives, not stackable plans. The observed plan-US store SKU includes only a 1 MB monthly allocation and base coverage is US-only; voice needs a permitted larger bundle. Canada needs a suitable international/local profile. Commit after reading the modem IMEI and confirming acceptance. |
| 1 | Average-energy meter and access to transient instrumentation | USB meter $15–30 typical; scope/current probe/shunt varies | Reputable electronics/test supplier or borrowed/rented lab equipment | A USB meter can measure input average/energy. A bandwidth-appropriate oscilloscope plus suitable probe/shunt or specified logger is required to claim modem-rail peak evidence. |

SIM7600G-H remains purchasable and vendor-supported in 2026 (not EOL; observed 2026-08-31), but it is a previous-generation Qualcomm design, and community reports document T-Mobile "registration denied" for SIM7600-based devices with uncertified IMEIs — which is why the IMEI-acceptance check below precedes any plan purchase. Two current alternatives are worth quoting at Gate B: the Waveshare SIM7670G LTE Cat-1/GNSS HAT ($44.99 direct, observed 2026-08-31 — an earlier ~$28 figure in this document was wrong and did not match any current SKU) rehearses the single-antenna Cat 1bis-class architecture the production direction targets at under half the price, and the Sixfab Raspberry Pi 4G/LTE Modem Kit ($140 observed) offers the US-carrier-certified Telit LE910C4-NF, which directly de-risks IMEI acceptance. SIM7600G-H provides broad regional LTE Cat 4 coverage, USB/UART, antenna connectors, and GNSS for evaluation; “global” does not guarantee carrier acceptance. The bare modem's [hardware design guide](https://files.waveshare.com/upload/5/52/SIM7600G%28-H%29_SIM7600NA%28-H%29_Hardware_Design_V1.08.pdf) specifies a 3.4–4.2 V rail capable of roughly 2 A transients, while the evaluation HAT accepts its documented 5 V input. Do not feed 3.4–4.2 V into the HAT's 5 V input. Follow its manual and use a known-good adequately rated source/cable. A laptop USB test can prove basic networking, but it proves neither the final battery supply nor the ESP32-S3's modem interface/driver capacity.

Use a phone hotspot before buying this stage. It cheaply screens how the experience behaves over mobile backhaul, but the phone may be using 4G or 5G, another carrier/profile, and completely different RF hardware. Log the phone's carrier and radio access technology when available; target-modem coverage and acceptance remain unresolved until physical modem tests.

## Deferred or gate-conditioned candidates

| Subsystem | Candidate and source | Observed price/status | Verdict |
|---|---|---|---|
| Compact compute | [Seeed XIAO ESP32-S3, 113991114](https://www.seeedstudio.com/XIAO-ESP32S3-p-5627.html) | $7.49; 21 × 17.8 mm; observed available | Good later Wi-Fi/BLE compute module for a custom carrier; it lacks the integrated UX needed now. |
| Narrow all-in-one | [M5StickS3, K150](https://shop.m5stack.com/products/m5sticks3-esp32s3-mini-iot-dev-kit?variant=47548831072513) | $21.50; 48 × 24 × 15 mm; observed available | Too narrow for the selected face and weaker for acoustic experiments. |
| Rounded display | [Waveshare 1.69-inch Touch LCD, SKU 27057](https://www.waveshare.com/1.69inch-Touch-LCD-Module.htm) | $14.99; board about 33.13 × 41.13 mm; observed available | Attractive 240 × 280 touch candidate after face/layout measurements; do not lock it now. |
| Audio reference | [Seeed ReSpeaker Lite, 107990273](https://www.seeedstudio.com/ReSpeaker-Lite-p-5928.html) | $24.90; 35 × 86 mm; observed in stock | Optional independent USB/I²S AEC/noise/AGC comparator if the CoreS3 result needs diagnosis; too long for the product and not part of the initial order. |
| Digital mic | [Adafruit ICS-43434, product 6049](https://www.adafruit.com/product/6049) | $8.95; observed available | Day 8-conditioned I²S candidate for the relocatable acoustic mule. **Design flag (2026-08-31): Adafruit's own page states the ICS-43434 is discontinued by TDK and names the SPH0645LM4H ([product 3421](https://www.adafruit.com/product/3421)) as the replacement.** Buying 6049 for a bench mule is fine; do not carry a discontinued MEMS part into the carrier BOM without an explicit lifetime decision. Evaluate the SPH0645LM4H, or a currently-produced TDK/Knowles equivalent, before Gate C freezes the microphone. |
| I²S amp | [Adafruit MAX98357A, product 3006](https://www.adafruit.com/product/3006) | $5.95; observed available | Day 8-conditioned acoustic-mule module. Its bridge-tied outputs must never be grounded. |
| Speaker | [Adafruit 8 ohm, 1 W speaker, product 3923](https://www.adafruit.com/product/3923) | $1.95; observed available | Day 8-conditioned acoustic test part; enforce volume/amplitude so a 5 V amplifier cannot overdrive it. Enclosure cavity matters more than its catalog line. |
| Battery | [Adafruit protected 2500 mAh LiPo, product 328](https://www.adafruit.com/product/328) | $14.95; 50 × 60 × 7.3 mm; observed available | Energy/volume reference, not a production recommendation. It has protection but no thermistor, must be charged at no more than 1.2 A per the supplier, must not be charged/used unattended, and needs external temperature policy/power-path validation. |
| Power slide switch | [C&K JS102011SAQN](https://www.digikey.com/en/products/detail/c-k/JS102011SAQN/1640095) | $0.85 observed 2026-08-31 | Latching-slide candidate, recast per [ADR 0008](../decisions/0008_use_exactly_two_physical_controls.md) as the product power switch (off de-energizes the system). The Day-12 bench rig (ordered after Day 8) still uses a switched microphone gate for instrumentation, not as a product control. |
| Conversation button | [C&K PTS645VL39-2 LFS, DigiKey CKN9103-ND search](https://www.digikey.com/en/products?keywords=PTS645VL39-2%20LFS) | ~$0.31 observed 2026-08-31 (search-snippet price; DigiKey blocks automated fetches — confirm in browser at checkout) | Day 8-conditioned tactile mechanism candidate for start/stop; force and cap geometry require an ergonomic mock-up, and the live-state light and capture-enable coupling require separate parts and circuitry. |
| GNSS | [u-blox MAX-M10 series](https://www.u-blox.com/en/product/max-m10-series?legacy=Current) | Exact regional MPN, stock, and price not selected | Only if the SIM7600 GNSS trial proves a user feature worth the power/privacy cost. |

An approximate 2,500 mAh, 3.7 V cell stores 9.25 Wh. At 85% conversion efficiency that is only about 3.9 hours at a 2 W average load or 2.0 hours at 4 W. Those are arithmetic examples, not a runtime forecast; modem bursts, sleep duty cycle, conversion loss, temperature, aging, and usable cutoff all matter.

## Production cellular direction, not a shopping order

For a North American integrated prototype, the 16 × 16 mm LEXI-R10 LTE Cat 1bis family is the leading size/power architecture candidate. The cellular business has transferred from u-blox to Trasna; [Trasna reports the family in production](https://www.trasna.io/blog/u-blox-cellular-modules), and current documentation is now obtainable (observed 2026-08-31): the [Trasna LEXI-R10 product page](https://www.trasna.io/product/lexi-r10-cellular-iot-module) and R18 public data sheet confirm the 16 × 16 mm, 133-pin LGA form factor, with regional order codes including LEXI-R10401D for North America — the module carried by the [MIKROE 4G LTE 3 Click for North America](https://www.mikroe.com/4g-lte-3-click-for-north-america), a $129-class evaluation board, not a final form factor. Cat 1bis offers one receive antenna and sufficient nominal throughput for compressed voice. Before using it, revalidate regional SKU, operator approvals, supply, and reference design with Trasna. Treat SGP.32 support as a later modem/eUICC/carrier-system evaluation, not a Gate B dependency; the physical-SIM EVT comes first ([ADR 0007](../decisions/0007_use_companion_app_and_cloud_history_sync.md)).

Do not purchase a tray of bare LGA modules. Distributor availability observed during this research ranged from no stock/MOQ 500 to small authorized quantities, which is a supply-chain risk as much as an electrical decision. Telit's [LE910Cx-NF certification announcement](https://www.telit.com/press/telit-le910cx-nf-lte-iot-modules-now-certified-by-the-three-largest-u-s-mobile-network-operators/) documents another mature US-carrier fallback.

The first custom PCB keeps cellular on a replaceable breakout. Before PCB freeze, one exact host path—not an ambiguous “USB/UART” placeholder—must demonstrate independently flowing encrypted uplink/downlink audio plus simultaneous capture, playback, AEC, and display load on the intended embedded host. The carrier should mechanically support the selected vendor board and leave RF on that board's documented antenna connectors unless a reviewed interface says otherwise. Only a later EVT integrates a bare module, after attach, host-driver, power, heat, RF placement, carrier, and compliance risks have been measured.

### Why not 5G now

The [Quectel RM520N series](https://www.quectel.com/product/5g-rm520n-series/) is approximately 30 × 52 mm before its carrier, requires multiple RF paths and a demanding high-speed/power/thermal design, and is already much of a pager's footprint. A [Sixfab Raspberry Pi 5G development kit](https://sixfab.com/product/raspberry-pi-5g-development-kit-5g-hat/) is useful for network experiments but is not an enclosure path — the kit is now sold as "5G Development Kit v2" at $195 excluding the 5G module itself, so a working setup lands in the $300+ range (observed 2026-08-30).

5G RedCap may eventually fit the product better. The [Quectel RG255C series](https://www.quectel.com/product/5g-redcap-rg255c-series/) is smaller and retains LTE fallback, but current evaluation hardware is expensive (the DigiKey-listed 5G-REDCAP-EVB-KIT is ~$421 and excludes the module; observed 2026-08-30) and availability is immature. LTE is the decision until measured latency, coverage, carrier sunset policy, or a customer requirement disproves it. Standard Starlink can only be an external dish/router whose Wi-Fi the pager uses. Starlink Direct to Cell is now a conditional participating-carrier IoT path for compatible Cat-1/Cat-1-bis/Cat-4 modems and bands, but it is not the MVP baseline until an exact country, partner carrier, SIM/plan, modem, and realtime-session profile pass Gate B; see [ADR 0002](../decisions/0002_use_wifi_first_and_4g_lte_failover.md).

### Companion app: no hardware purchase, native-bridge spike required

The [ADR 0007](../decisions/0007_use_companion_app_and_cloud_history_sync.md) companion app adds nothing to the hardware BOM. React Native is only the current UI candidate. Bridge Espressif's official iOS and Android provisioning libraries and prove Security 2, custom endpoints, permissions, foreground behavior, failure recovery, memory use, and licenses on both platforms before freezing the stack. Third-party wrappers may be evaluated as spike accelerators, but none is a selected production dependency.

## Reference build: inspiration, not BOM

Huy Vector's [build guide](https://www.huyvector.org/robots-kinetic/pocket-ai-assistant) text lists an ESP32-C3, OLED, microphone module, a “98357BGA”-labelled amplifier entry, phone speaker, battery, Type-C charger, and switch. Its current linked products, diagram, and video resolve these to an ESP32-C3 SuperMini, 0.96-inch OLED, INMP441-class I²S microphone, MAX98357A-class I²S amplifier, and 14250 cell. The guide links browser flashing; the video demonstrates temporary-AP/captive-portal provisioning. The video does not demonstrate cellular, GPS, OpenAI, battery life, acoustic echo cancellation, certification, or production safety.

The guide links a compiled firmware binary but does not supply corresponding source or a license for that artifact. Treat it as untrusted reference-only: do not use it on a trusted network, redistribute it, or base product firmware on it until provenance, license, endpoints, credentials, and network behavior are audited. The upstream [XiaoZhi ESP32 project](https://github.com/78/xiaozhi-esp32) is MIT-licensed, but that does not establish the license of Huy's binary or rights to the xiaozhi.me hosted service. The video's hosted-service UI also labels its “Open Source” tier for learning/noncommercial use and warns that commercial features may require licensing; treat that as service UI evidence, not an interpretation of the upstream firmware license.

Do not reproduce the visible removal of the cell wrapper, direct soldering to a cell, or use of an exposed metal frame as a ground bus. Use a protected/tabbed cell or approved connector, insulation, strain relief, a qualified charger/power path, and an RF-aware enclosure.

## New York sourcing: where to actually buy each part

Observed 2026-08-31 for a New York City buyer. Amazon, DigiKey, Mouser, Waveshare, and Micro Center all block automated fetches, so prices marked *unconfirmed* came from search snippets or could not be read at all; confirm in a browser at checkout. **Amazon is not an authorized Adafruit distributor** ([distributor list](https://www.adafruit.com/distributors) names DigiKey, Mouser, Jameco, and Micro Center), so every "Adafruit" Amazon listing is a third-party reseller.

### The headline: Micro Center Brooklyn changes the plan

[Micro Center Brooklyn](https://www.microcenter.com/site/stores/brooklyn.aspx), 850 3rd Ave, Sunset Park, is the only place in New York City where this project's parts can be bought over a counter. Mon–Sat 10:00–21:00, Sun 11:00–18:00, 18-minute in-store pickup. It stocks **genuine Adafruit-branded** product, including every acoustic-mule part: [ICS-43434 mic](https://www.microcenter.com/product/691530/adafruit-industries-i2s-mems-microphone-breakout-ics-43434), [MAX98357A amp](https://www.microcenter.com/product/613583/adafruit-industries-max98357a-i2s-3w-class-d-amplifier-breakout) at $5.95, [Mini Oval Speaker](https://www.microcenter.com/product/612827/adafruit-industries-mini-oval-speaker-8-ohm-1-watt), and the [2500 mAh LiPo](https://www.microcenter.com/product/454401/adafruit-industries-lithium-ion-polymer-battery-37v-2500mah) at $14.99. Buying the cell in person also sidesteps lithium shipping rules entirely. Always check the Brooklyn store's stock toggle before travelling — a catalog listing is not shelf stock.

### Per-part sourcing

| Part | Amazon? | Best source for NYC | Delivery |
|---|---|---|---|
| CoreS3 interaction mule — superseded sourcing note | The original Lite search found no Amazon listing | **Do not buy another board.** The full CoreS3 K128 was purchased from M5Stack's official Amazon storefront on 2026-08-31; see the purchase record above and [daily log](../../scrum/20260830/task_0001/daily_log.md). The former K128-LITE/DigiKey option is retained only as historical research. | Purchased K128 arrival was recorded for 2026-09-02 |
| USB-C data cable | Yes, commodity | Amazon Same-Day, Best Buy, or B&H | Same day |
| Adafruit ICS-43434 (6049) | **No US listing.** Every cheap "I²S MEMS mic" on Amazon is a different chip (usually INMP441) | Micro Center Brooklyn, or [Adafruit direct](https://www.adafruit.com/product/6049) $8.95 | Same day walk-in, or next-day ground from Brooklyn |
| Adafruit MAX98357A (3006) | [B01K5GCFA6](https://www.amazon.com/Adafruit-I2S-Class-Amplifier-Breakout/dp/B01K5GCFA6), third-party reseller, price unconfirmed | Micro Center Brooklyn or Adafruit direct, both $5.95 | Same day walk-in |
| Adafruit speaker (3923) | [B07KKP4YP7](https://www.amazon.com/Adafruit-Mini-Oval-Speaker-Watt/dp/B07KKP4YP7), reseller | Add to the Adafruit order, $1.95 | With the rest |
| Adafruit 2500 mAh LiPo (328) | [B01NAX9XYG](https://www.amazon.com/Adafruit-328-Battery-Lithium-Polymer/dp/B01NAX9XYG), reseller — **high risk** | Micro Center Brooklyn $14.99 (no shipping rules), or Adafruit $14.95 ground-only | Same day walk-in |
| C&K JS102011SAQN power switch | [B00M1S2NUO](https://www.amazon.com/dp/B00M1S2NUO), unconfirmable seller/price | [DigiKey 1640095](https://www.digikey.com/en/products/detail/c-k/JS102011SAQN/1640095) $0.85, no minimum — buy ~10 in one order with the tactile switch | Next day |
| C&K PTS645VL39-2 LFS | [B0748MGX1J](https://www.amazon.com/COMPONENTS-PTS645SL502LFS-Compact-Through-Tactile/dp/B0748MGX1J), reseller | [DigiKey CKN9103-ND](https://www.digikey.com/en/products/detail/c-k/PTS645VL39-2-LFS/1146765) ~$0.31 | Next day |
| Illuminated conversation button (prototype) | — | [Adafruit 16 mm illuminated pushbutton #1477](https://www.adafruit.com/product/1477) $1.95, LED independently drivable | Next day |
| Waveshare SIM7600G-H HAT | [B0BD544MRN](https://www.amazon.com/dp/B0BD544MRN) $120.99 from Waveshare's **official** store | [Waveshare direct](https://www.waveshare.com/sim7600g-h-4g-hat.htm) $97.99 — Amazon is a 23.5% markup with no speed benefit | Direct: 5–10 days from Shenzhen |
| Waveshare SIM7670G HAT | [B0CXP7ZPVL](https://www.amazon.com/dp/B0CXP7ZPVL) $59.99 official store | Waveshare direct $44.99 — Amazon is a 33% markup | 5–10 days |
| LTE AUX/diversity antenna | [B07ZYXDSDK](https://www.amazon.com/dp/B07ZYXDSDK) Bingfu 2-pack $9.89, brand storefront, FBA | Same — best option. **Does not cover Band 71 (600 MHz)** | Prime next-day |
| USB power meter | [B0D9B93YDQ](https://www.amazon.com/dp/B0D9B93YDQ) Eversame PD3.1 $15.99, accumulates mAh/Wh | Same; B&H stocks a Plugable VAMETER3 at $29.95 for same-day, but it does not accumulate | Next day |
| Sixfab 4G Modem Kit | Listing exists but **out of stock**, and cannot be configured with the Telit module | [Sixfab direct](https://sixfab.com/product/raspberry-pi-4g-lte-modem-kit/) $140, ships from Texas via UPS | Next-day available |
| Seeed XIAO ESP32-S3 | Official Seeed store exists; multiple confusable ASINs | [DigiKey 113991114](https://www.digikey.com/en/products/detail/seeed-technology-co-ltd/113991114/19285530) $7.49, zero markup. **The plain board already has 8 MB PSRAM — do not pay for Sense**, which only adds a camera/PDM mic/SD | Next day |
| Seeed ReSpeaker Lite | **No Amazon listing** | [Seeed direct](https://www.seeedstudio.com/ReSpeaker-Lite-p-5928.html) $24.90, select US warehouse | Domestic |
| Waveshare 1.69" Touch LCD | [B0D17CN13C](https://www.amazon.com/1-69inch-LCD-Module-Touch-Communication/dp/B0D17CN13C) official store | Amazon is genuinely best here — next-day beats a China ship. **Verify the ASIN is the touch version**; several near-identical Waveshare 1.69" ASINs are SPI-only non-touch | Next day |

### Cellular antenna trap

The plain SIM7600G-H HAT (P/N 17372) uses **SMA female** jacks; the **(B) variant uses IPEX-1/u.FL** and costs the same $97.99. The two are easy to confuse and need different antennas. Confirm which variant is in the cart before ordering antennas.

### Adafruit logistics

Adafruit moved out of Manhattan in 2024 and is now at Industry City, Brooklyn ([announcement](https://blog.adafruit.com/2024/08/08/adafruit-industry-city/)). **There is no will-call or public storefront** — do not travel there. Orders placed by 11:00 ET ship the same day, and Brooklyn-to-NYC ground is a one-zone lane that typically lands next day. A [$30 flat same-day courier](https://www.adafruit.com/sameday) exists (11:00 cutoff, Mon–Fri, all four boroughs) but is rarely worth it given next-day ground. Free shipping starts at $199.

### Instrumentation: borrow the oscilloscope

Gate C requires a bandwidth-appropriate oscilloscope for modem transient capture — a significant purchase. [Fat Cat Fab Lab](https://fatcatfablab.org/electronics), 224 W 4th St in the West Village, publishes an equipment list including an oscilloscope, bench power supplies, a function generator, soldering stations, and a reflow oven, with 24/7 member access at a reported ~$99–110/month (confirm directly; their site blocks automated checks). One month of membership costs far less than a scope. [NYC Resistor](https://www.nycresistor.com/participate/) in Boerum Hill runs free public Craft Nights every Monday and Thursday at 18:30 — the cheapest way to meet people with test gear, though a current bench scope there was not confirmed.

### Venues to rule out

- **Tinkersphere's Lower East Side storefront is closed.** Their site states the current office "is not open to the public." Online-only; do not travel there.
- **Best Buy** is, for this BOM, essentially a cable-and-storage backstop. Its Arduino/Pi listings are largely third-party Marketplace fulfilment, not shelf stock.
- **B&H Photo** is useful for cables, power supplies, storage, and some test gear with 30-minute Midtown pickup, but carries no breakout boards — and it is **closed every Saturday and after 14:00 Friday**, with the website also offline over that window.
- **NYU and Columbia makerspaces** are restricted to affiliates.
- **Amazon Same-Day** is fine for cables, enclosures, and tools, but its inventory skews to anonymous marketplace sellers — precisely the channel through which cloned ESP32 boards and mislabelled I²S microphones enter.

## Online and pre-hardware test matrix

| Question | Cheapest valid test | What it cannot prove |
|---|---|---|
| Does the face feel alive? | Build the state machine in the [LVGL PC simulator](https://docs.lvgl.io/9.1/integration/ide/pc-simulator.html); test timings and screen recordings. | Display viewing angle, touch feel, GPU/MCU contention, and physical scale. |
| Does the conversation/prompt work? | Use the [OpenAI Realtime Playground](https://platform.openai.com/playground/realtime), then a desktop/browser client through our gateway; exercise semantic VAD, speech-driven interruption, cancellation, and truncation. | Embedded AEC/audio drivers, render-cursor accuracy, enclosure acoustics, and real network transitions. |
| Does event/network logic fit ESP32? | Use [Wokwi ESP32 simulation](https://docs.wokwi.com/guides/esp32) for the session toggle, parallel input/output states, generation/cursor handling, Wi-Fi logic, and failure injection. | Cellular RF, real audio fidelity/AEC, current peaks, antennas, and thermals. |
| Is the schematic electrically coherent? | Run ERC and simple analog/power checks in [EasyEDA](https://docs.easyeda.com/en/Simulation/Chapter1-Introduction/) or KiCad plus a circuit simulator. | RF certification, acoustic feedback, and layout-dependent power integrity. |
| Does the board fit? | Exchange STEP models between ECAD and CAD; print a 1:1 paper/foam model; order a cheap shell from [JLC3DP](https://jlc3dp.com/3d-printing-quote) or [Xometry](https://www.xometry.com/). | Drop life, RF detuning, finish, and injection molding behavior. |
| Does voice tolerate mobile backhaul? | First use a phone hotspot and log its carrier/RAT when available. Then use SIM7600G-H by USB with one selected SIM/service path. Log latency, data, signal, reconnects, average energy, and temperature. | The phone does not prove target-modem LTE coverage. Linux USB does not prove the embedded host/interface, final antenna, carrier approval, peaks, SAR, or battery life. |

No online simulator honestly validates antenna placement, network attach, RF coexistence, acoustic echo, enclosure vibration, modem current spikes, heat, or battery runtime. These require physical mules and instrumentation.

## PCB suppliers for the later gate

- [JLCPCB order flow](https://jlcpcb.com/help/article/how-do-i-place-an-order) and [PCBA pricing components](https://jlcpcb.com/help/article/pcb-assembly-price): good low-quantity economics and integrated parts/3D-print workflow; obtain a live quote.
- [PCBWay assembly](https://www.pcbway.com/pcb-assembly.html): useful second quote and assembly option.
- [MacroFab](https://www.macrofab.com/platform): higher-touch North American prototype/production option.
- [Seeed Fusion PCBA FAQ](https://support.seeedstudio.com/knowledgebase/topics/150804-fusion-pcb-assembly-faq): another small-batch comparison.

At Gate C, quote 5–10 assembled four-layer carrier boards plus two bare boards. Compare landed cost, component substitutions, inspection/X-ray, stencil/NRE, electrical test, lead time, and import/shipping—not the headline PCB promo alone.
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

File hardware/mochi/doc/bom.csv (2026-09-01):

reference | value_or_mpn | manufacturer | role | population | datasheet | footprint_status
J1 | USB4105-GF-A | GCT | User USB-C charge-only receptacle | FIT | https://gct.co/connector/usb4105 | REFERENCE_ONLY_VERIFY_BEFORE_FAB
U1 | TPD2EUSB30 | Texas Instruments | USB-C CC1/CC2 ESD protection | FIT | https://www.ti.com/product/TPD2EUSB30 | REFERENCE_ONLY_VERIFY_BEFORE_FAB
D4 | ESDA7P60-1U1M | STMicroelectronics | USB VBUS TVS | FIT | https://www.st.com/en/protections-and-emi-filters/esda7p60-1u1m.html | REFERENCE_ONLY_VERIFY_BEFORE_FAB
F1 | 1206L075/24 | Littelfuse | Resettable USB input fuse | FIT | https://www.littelfuse.com/products/polyswitch-resettable-pptcs/surface-mount/1206l | REFERENCE_ONLY_VERIFY_BEFORE_FAB
R1 | 5.1k 1% | Generic | USB-C CC1 Rd | FIT |  | REFERENCE_ONLY_VERIFY_BEFORE_FAB
R2 | 5.1k 1% | Generic | USB-C CC2 Rd | FIT |  | REFERENCE_ONLY_VERIFY_BEFORE_FAB
U3 | BQ25628E | Texas Instruments | 1-cell 2A NVDC charger and power path | FIT | https://www.ti.com/lit/ds/symlink/bq25628e.pdf | REFERENCE_ONLY_VERIFY_BEFORE_FAB
L1 | 1uH XGL4020-102 | Coilcraft | BQ25628E power-path inductor | FIT | https://www.coilcraft.com/en-us/products/power/shielded-inductors/xgl/xgl4020/ | REFERENCE_ONLY_VERIFY_BEFORE_FAB
C1 | 1uF 25V X7R | Generic | BQ VBUS bypass | FIT |  | REFERENCE_ONLY_VERIFY_BEFORE_FAB
C2 | 10uF 25V X7R | Generic | BQ PMID bulk | FIT |  | REFERENCE_ONLY_VERIFY_BEFORE_FAB
C3 | 100nF 25V X7R | Generic | BQ PMID high-frequency bypass | FIT |  | REFERENCE_ONLY_VERIFY_BEFORE_FAB
C4 | 47nF 25V X7R | Generic | BQ bootstrap capacitor | FIT |  | REFERENCE_ONLY_VERIFY_BEFORE_FAB
C5 | 4.7uF 10V X7R | Generic | BQ REGN bypass | FIT |  | REFERENCE_ONLY_VERIFY_BEFORE_FAB
C6 | 10uF 10V X7R | Generic | BQ SYS bulk 1 of 2 | FIT |  | REFERENCE_ONLY_VERIFY_BEFORE_FAB
C7 | 10uF 10V X7R | Generic | BQ SYS bulk 2 of 2 | FIT |  | REFERENCE_ONLY_VERIFY_BEFORE_FAB
C8 | 10uF 10V X7R | Generic | BQ BAT bypass | FIT |  | REFERENCE_ONLY_VERIFY_BEFORE_FAB
R3 | 4.99k 1% | Generic | BQ input-current limit, about 500mA | FIT | https://www.ti.com/lit/ds/symlink/bq25628e.pdf | REFERENCE_ONLY_VERIFY_BEFORE_FAB
R4 | 5.23k 1% | Generic | BQ TS upper resistor for 103AT-class NTC | FIT | https://www.ti.com/lit/ds/symlink/bq25628e.pdf | REFERENCE_ONLY_VERIFY_BEFORE_FAB
R5 | 30.1k 1% | Generic | BQ TS lower resistor for 103AT-class NTC | FIT | https://www.ti.com/lit/ds/symlink/bq25628e.pdf | REFERENCE_ONLY_VERIFY_BEFORE_FAB
J2 | Molex 5023520300 | Molex | Protected pack connector | FIT | https://www.molex.com/en-us/products/part-detail/5023520300 | REFERENCE_ONLY_VERIFY_BEFORE_FAB
RS1 | 10m 1% Kelvin | Vishay or equivalent | Fuel-gauge low-side shunt | FIT |  | REFERENCE_ONLY_VERIFY_BEFORE_FAB
U4 | MAX17055ETB+T | Analog Devices | Fuel gauge with current and time estimation | FIT | https://www.analog.com/en/products/MAX17055.html | REFERENCE_ONLY_VERIFY_BEFORE_FAB
C9 | 100nF 10V X7R | Generic | Fuel-gauge bypass | FIT |  | REFERENCE_ONLY_VERIFY_BEFORE_FAB
SW1 | LATCHING POWER SLIDE | C&K or Alps TBD | Only latching hardware power control | FIT |  | REFERENCE_ONLY_VERIFY_BEFORE_FAB
R6 | 100k 1% | Generic | Power-enable fail-safe pull-down | FIT |  | REFERENCE_ONLY_VERIFY_BEFORE_FAB
U5 | TPS22950 | Texas Instruments | Reverse-blocking adjustable-current-limit master load switch | FIT | https://www.ti.com/lit/ds/symlink/tps22950.pdf | REFERENCE_ONLY_VERIFY_BEFORE_FAB
R7 | 523R 1% | Generic | TPS22950 nominal about 2.4A current limit | FIT | https://www.ti.com/lit/ds/symlink/tps22950.pdf | REFERENCE_ONLY_VERIFY_BEFORE_FAB
C10 | 1uF 10V X7R | Generic | Master-switch input bypass | FIT |  | REFERENCE_ONLY_VERIFY_BEFORE_FAB
C11 | 10uF 10V X7R | Generic | Master-switch output bulk | FIT |  | REFERENCE_ONLY_VERIFY_BEFORE_FAB
U6 | TPS63802 | Texas Instruments | 2A 3.3V peripheral buck-boost | FIT | https://www.ti.com/lit/ds/symlink/tps63802.pdf | REFERENCE_ONLY_VERIFY_BEFORE_FAB
L2 | 0.47uH XFL4015-471 | Coilcraft | TPS63802 buck-boost inductor | FIT | https://www.coilcraft.com/en-us/products/power/shielded-inductors/xfl/xfl4015/ | REFERENCE_ONLY_VERIFY_BEFORE_FAB
R8 | 511k 1% | Generic | TPS63802 3.3V feedback upper | FIT |  | REFERENCE_ONLY_VERIFY_BEFORE_FAB
R9 | 91k 1% | Generic | TPS63802 3.3V feedback lower | FIT |  | REFERENCE_ONLY_VERIFY_BEFORE_FAB
C12 | 10uF 10V X7R | Generic | TPS63802 input bulk | FIT |  | REFERENCE_ONLY_VERIFY_BEFORE_FAB
C13 | 22uF 6.3V X7R | Generic | TPS63802 output bulk | FIT |  | REFERENCE_ONLY_VERIFY_BEFORE_FAB
R10 | 4.7k 1% | Generic | I2C SDA pull-up | FIT |  | REFERENCE_ONLY_VERIFY_BEFORE_FAB
R11 | 4.7k 1% | Generic | I2C SCL pull-up | FIT |  | REFERENCE_ONLY_VERIFY_BEFORE_FAB
U10 | WALTER P000000100 N16R2 | QuickSpot/DPTechnics | ESP32-S3 Wi-Fi/BLE plus Sequans GM02SP LTE-M/NB-IoT/GNSS SoM | FIT | https://quickspot.io/datasheet/walter_datasheet.pdf | REFERENCE_ONLY_VERIFY_BEFORE_FAB
C14 | 100uF 6.3V low-ESR | Panasonic or equivalent | Walter VIN EVT reservoir 1 of 2 | FIT |  | REFERENCE_ONLY_VERIFY_BEFORE_FAB
C15 | 100uF 6.3V low-ESR | Panasonic or equivalent | Walter VIN EVT reservoir 2 of 2 | FIT |  | REFERENCE_ONLY_VERIFY_BEFORE_FAB
C16 | 10uF 10V X7R | Generic | Walter VIN local bypass | FIT |  | REFERENCE_ONLY_VERIFY_BEFORE_FAB
C17 | 100nF 10V X7R | Generic | Walter VIN high-frequency bypass | FIT |  | REFERENCE_ONLY_VERIFY_BEFORE_FAB
SW2 | ILLUMINATED CONVERSATION BUTTON | TBD | Only momentary user control; amber LED is D2 | FIT |  | REFERENCE_ONLY_VERIFY_BEFORE_FAB
R12 | 10k 1% | Generic | Conversation-button pull-up | FIT |  | REFERENCE_ONLY_VERIFY_BEFORE_FAB
D2 | AMBER BUTTON LED | TBD | Connecting and session-intent indicator inside SW2 | FIT |  | REFERENCE_ONLY_VERIFY_BEFORE_FAB
R13 | 1.5k 1% | Generic | Amber LED current limit | FIT |  | REFERENCE_ONLY_VERIFY_BEFORE_FAB
U12 | TPS22918 | Texas Instruments | Hardware microphone rail gate | FIT | https://www.ti.com/lit/ds/symlink/tps22918.pdf | REFERENCE_ONLY_VERIFY_BEFORE_FAB
R14 | 100k 1% | Generic | Capture-enable fail-safe pull-down | FIT |  | REFERENCE_ONLY_VERIFY_BEFORE_FAB
C18 | 1uF 6.3V X7R | Generic | Switched microphone-rail bypass | FIT |  | REFERENCE_ONLY_VERIFY_BEFORE_FAB
U13 | SN74LVC2G125 | Texas Instruments | PDM clock and data isolation with Ioff | FIT | https://www.ti.com/lit/ds/symlink/sn74lvc2g125.pdf | REFERENCE_ONLY_VERIFY_BEFORE_FAB
MK1 | IM69D129F | Infineon | Bottom-port PDM microphone | FIT | https://www.infineon.com/part/IM69D129F | REFERENCE_ONLY_VERIFY_BEFORE_FAB
D1 | CYAN CAPTURE LED | TBD | Hardware-coupled capture truth indicator | FIT |  | REFERENCE_ONLY_VERIFY_BEFORE_FAB
R15 | 1.5k 1% | Generic | Cyan LED current limit | FIT |  | REFERENCE_ONLY_VERIFY_BEFORE_FAB
U14 | MAX98357AETE+T | Analog Devices | I2S mono class-D amplifier | FIT | https://www.analog.com/en/products/max98357a.html | REFERENCE_ONLY_VERIFY_BEFORE_FAB
R16 | 100k 1% | Generic | Amplifier shutdown pull-down | FIT |  | REFERENCE_ONLY_VERIFY_BEFORE_FAB
C19 | 10uF 6.3V X7R | Generic | Amplifier local bulk | FIT |  | REFERENCE_ONLY_VERIFY_BEFORE_FAB
C20 | 100nF 6.3V X7R | Generic | Amplifier high-frequency bypass | FIT |  | REFERENCE_ONLY_VERIFY_BEFORE_FAB
J4 | AS01808AO-SC18-WP-R | PUI Audio | 8ohm 1W spring-contact speaker | FIT | https://puiaudio.com/file/specs-AS01808AO-SC18-WP-R.pdf | REFERENCE_ONLY_VERIFY_BEFORE_FAB
J5 | WAVESHARE 1.69IN TOUCH LCD 27057 | Waveshare | GH1.25 12-pin 240x280 ST7789V2 LCD and CST816S touch module | FIT | https://www.waveshare.com/wiki/1.69inch_Touch_LCD_Module | REFERENCE_ONLY_VERIFY_BEFORE_FAB
U15 | TPS22918 DNP CAMERA | Texas Instruments | Optional camera rail gate | DNP | https://www.ti.com/lit/ds/symlink/tps22918.pdf | REFERENCE_ONLY_VERIFY_BEFORE_FAB
R17 | 100k 1% DNP | Generic | Camera-enable fail-safe pull-down | DNP |  | REFERENCE_ONLY_VERIFY_BEFORE_FAB
J6 | ARDUCAM MEGA 3MP B0400 DNP | Arducam | Six-wire SPI still-camera experiment; too large for baseline enclosure | DNP | https://docs.arducam.com/Arduino-SPI-camera/MEGA-SPI/MEGA-SPI-Camera/ | REFERENCE_ONLY_VERIFY_BEFORE_FAB
D3 | WHITE CAMERA POWER LED DNP | TBD | Hardware-coupled camera-power indicator | DNP |  | REFERENCE_ONLY_VERIFY_BEFORE_FAB
R18 | 1.5k 1% DNP | Generic | Camera indicator current limit | DNP |  | REFERENCE_ONLY_VERIFY_BEFORE_FAB
TP1 | DEBUG_TX | Generic | Factory UART TX pad; never supply power | FIT |  | REFERENCE_ONLY_VERIFY_BEFORE_FAB
TP2 | DEBUG_RX | Generic | Factory UART RX pad; verify no off-state injection | FIT |  | REFERENCE_ONLY_VERIFY_BEFORE_FAB
TP3 | WALTER_DFU_N | Generic | Factory boot and DFU pad | FIT |  | REFERENCE_ONLY_VERIFY_BEFORE_FAB
TP4 | WALTER_RESET_N | Generic | Factory reset pad | FIT |  | REFERENCE_ONLY_VERIFY_BEFORE_FAB
TP5 | MAIN_FAULT_N | Generic | Master-switch fault pad | FIT |  | REFERENCE_ONLY_VERIFY_BEFORE_FAB
TP6 | 3V3_POWER_GOOD | Generic | Peripheral-rail validation pad | FIT |  | REFERENCE_ONLY_VERIFY_BEFORE_FAB
TP7 | BQ_INTERRUPT | Generic | Charger-interrupt validation pad | FIT |  | REFERENCE_ONLY_VERIFY_BEFORE_FAB
TP8 | GROUND | Generic | Factory measurement ground | FIT |  | REFERENCE_ONLY_VERIFY_BEFORE_FAB
TP9 | WALTER_3V3_OUT | Generic | Walter switched 3.3V output measurement only; never tie to 3V3_PERIPH | FIT |  | REFERENCE_ONLY_VERIFY_BEFORE_FAB
TP10 | GAUGE_ALERT | Generic | Fuel-gauge alert validation pad | FIT |  | REFERENCE_ONLY_VERIFY_BEFORE_FAB
TP11 | BQ_POWER_GOOD | Generic | Charger power-good validation pad | FIT |  | REFERENCE_ONLY_VERIFY_BEFORE_FAB

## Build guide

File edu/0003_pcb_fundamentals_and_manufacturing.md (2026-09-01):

# 0003 — Printed circuit board fundamentals: from a diagram to a working board

Start with [0000 — Internet of Things and electrical fundamentals](0000_start_here_iot_and_electrical_fundamentals.md). It introduces voltage, current, resistance, power, ground, regulators, and the idea that current always needs a complete loop. This chapter assumes those ideas, but not previous printed circuit board experience. [0002 — Modules, buses, and audio](0002_modules_buses_and_audio.md) is also useful before choosing Mochi's connectors.

## Prerequisites

You should be able to:

- distinguish voltage from current;
- use a multimeter to measure a low-voltage direct-current rail;
- explain why a load needs both a supply path and a return path; and
- recognize that a 3.3 V pin must not automatically be connected to a 5 V pin.

Do not design a lithium-battery charger from this chapter alone. For an early Mochi prototype, use a protected cell and a documented charger or power module, then validate the exact combination on the bench.

## Learning goals

By the end, you should be able to:

1. explain the difference between a schematic and a board layout;
2. read the path from a component pin, through a **net**, to another pin;
3. explain why a schematic symbol and a physical **footprint** are separate;
4. describe what copper layers, ground planes, return paths, and decoupling capacitors do;
5. name the files used to fabricate and assemble a board; and
6. bring up a new board in small, measurable steps instead of powering everything at once.

## 1. What a printed circuit board actually does

A **printed circuit board (PCB)** is a rigid or flexible sheet that holds components and connects them with patterned copper. The fiberglass material provides mechanical support and electrical insulation. The copper replaces most of the loose jumper wires used on a breadboard.

A populated board is a **printed circuit board assembly (PCBA)**. The extra `A` matters:

```text
PCB   = the manufactured board, with copper and holes but no parts
PCBA  = the PCB after components have been soldered onto it
```

A PCB does not decide what the circuit should do. It makes a circuit repeatable, compact, and mechanically stable. A wrong connection becomes a repeatable wrong connection.

For a software engineer, a useful first analogy is:

| Hardware artifact | Software analogy | Where the analogy stops working |
|---|---|---|
| Schematic | Typed source code | Wires have physical resistance and noise that the drawing does not show |
| Electrical rules | Type checker or linter | A valid connection can still be badly placed or under-sized |
| Layout | Compilation plus resource placement | Millimetres, heat, fields, and current paths affect behavior |
| Manufacturing files | Build artifacts | Fabricating another revision costs money and days, not seconds |
| Board bring-up | Integration test on real hardware | A bad test probe can itself change or damage the circuit |

Use the analogy to organize the workflow, not to assume hardware is deterministic software drawn with lines.

## 2. The small vocabulary that unlocks a schematic

Consider the simplest indicator circuit. `3V3` is a conventional net name for a 3.3 V supply, and `GND` is the name of its ground return:

```text
3V3 ---- R1, 1 kΩ ---->| D1 ---- GND
                   light-emitting diode
```

Current can flow from the 3.3 V supply, through resistor `R1`, through light-emitting diode `D1`, and back through ground (`GND`). The resistor limits current so the diode is not damaged.

The drawing introduces the core objects:

| Term | Meaning | Example |
|---|---|---|
| **Component** | A real part with an electrical job | resistor, display connector, microcontroller |
| **Reference designator** | A unique name for one component | `R1`, `C7`, `U2`, `J3` |
| **Pin** | One electrical connection on a component | pin 1 of `J3` |
| **Schematic symbol** | The logical drawing of a component and its pins | a zig-zag resistor symbol |
| **Net** | Every pin intended to be electrically connected together | the `3V3` net or `GND` net |
| **Pad** | Exposed copper where a component lead is soldered | pad 1 under `R1` |
| **Footprint** | The physical pattern of pads, holes, outline, and clearances for a part | the exact land pattern for a board-edge connector |
| **Trace** | A routed strip of copper joining pads on one layer | copper from `R1` to `D1` |
| **Via** | A plated hole that connects copper on different layers | a connection from a top trace to the ground plane |

### A net is a connection, not a packet stream

In software, a network link carries messages between endpoints. In a schematic, a **net** means that its pins are the same electrical node. These two drawings state the same intent:

```text
U1 pin 8 -------- U2 pin 3

U1 pin 8 --[BUTTON_SIGNAL]  [BUTTON_SIGNAL]-- U2 pin 3
```

The second form uses matching net labels to avoid a long line. Renaming only one label silently disconnects the intended circuit, so net names deserve the same care as public application programming interface (API) names.

Power names such as `VBAT` (battery voltage), `5V0` (5.0 V), `3V3` (3.3 V), and `GND` are nets too. They are not global magic. A board can deliberately have several grounds or supplies, and joining or separating them is an engineering decision.

## 3. Schematic: describe electrical intent

The **schematic** records:

- which exact components exist;
- which pins connect to which nets;
- resistor, capacitor, and other component values;
- supply voltages and power domains;
- connector pin assignments;
- required pull-up, pull-down, reset, and boot behavior; and
- notes that a reviewer or assembler must know.

The schematic should be readable as a story. For example:

```text
battery -> protection -> charger/power path -> regulators -> loads
                                                     |-> compute module
                                                     |-> display
                                                     |-> audio amplifier
                                                     `-> cellular module connector
```

This is Mochi's **power tree**. Drawing it before detailed circuitry makes it easier to find missing rails, incompatible voltages, and unrealistic current budgets.

An **electrical rules check (ERC)** is an automated schematic check. It can catch an output connected to another output, an input left unconnected, or a power pin that appears unpowered. It cannot know that:

- a connector has been drawn backwards;
- an amplifier return current will add noise to the microphone path;
- the cellular supply is too weak for a short transmit burst; or
- a power-off Universal Serial Bus (USB) path can accidentally keep the device partly alive.

Treat ERC like a compiler warning pass: run it, resolve every warning deliberately, and still perform a human design review.

## 4. Symbol versus footprint: logic meets mechanics

A symbol says what pins mean. A footprint says where copper pads physically exist.

```text
schematic symbol       footprint on the PCB       real component

  1 --[ U1 ]-- 4       o  ############  o        must match pad pitch,
  2 --[    ]-- 3       o  ############  o        pin numbering, and body
```

One schematic symbol can map to several packages. A 10 kΩ resistor could be a large through-hole part or a tiny surface-mount part; its logical job is unchanged, but its footprint is completely different.

A wrong footprint can pass ERC and the board layout rules, yet make assembly impossible. This is similar to calling a native library with the right function name but the wrong application binary interface: the logical interface looks plausible while the physical contract is incompatible.

Before using a footprint:

1. confirm the exact manufacturer part number, not just a product family;
2. compare pad numbers with the datasheet's pin table;
3. compare pad sizes and pitch with the recommended land pattern;
4. verify pin 1 and polarity marks;
5. check connector mating direction and board-edge location;
6. check the real body height and keep-out area; and
7. print the board view at 1:1 scale and place large connectors/modules on it.

Manufacturer-provided computer-aided design models are useful starting points, not proof. Independently inspect them.

## 5. Layout: turn ideal nets into physical copper

The **layout** places each footprint at an exact coordinate and turns each net into copper. This is where an ideal schematic connection gains length, resistance, capacitance, inductance, heat, and electromagnetic coupling.

**Inductance** is a property of a current path that resists rapid changes in current; among other effects, it can create a voltage disturbance when current changes quickly. **Electromagnetic coupling** means a changing electric or magnetic field around one conductor transfers unwanted energy into another conductor. In software terms, layout creates hidden shared channels between otherwise separate-looking interfaces. Unlike a software dependency, the strength of that channel changes with distance, geometry, current, and switching speed.

The usual flow includes a three-dimensional (3D) mechanical review:

```text
requirements and measurements
          |
          v
power tree -> schematic -> ERC -> assign/verify footprints
                                      |
                                      v
mechanical outline -> placement -> routing -> DRC -> 3D review
                                                   |
                                                   v
                                          manufacturing files
```

A **design rules check (DRC)** tests physical rules: trace width, spacing, hole size, copper-to-edge clearance, and whether all required nets were routed. Like ERC, it verifies configured rules, not whether those rules fit the product.

### Placement comes before routing

Routing a poor placement produces a neatly connected poor board. Place in this order:

1. board outline, mounting holes, display, buttons, external connectors, and antennas;
2. compute, audio, power, and modem-module connector blocks;
3. decoupling and local support parts next to the pins they support;
4. short high-current and noise-sensitive loops;
5. slower control signals and remaining passive components.

For Mochi, mechanics, antenna clearances, microphone/speaker acoustics, power paths, and the final two physical controls constrain placement before most signal traces are drawn.

## 6. Copper layers and why Mochi starts with four

A board can contain multiple copper sheets separated by insulating material. In the cross-section below, `L1` means layer 1, and so on:

```text
outside
  L1  components + short critical signals
       insulating material
  L2  mostly continuous GND copper plane
       insulating core
  L3  power distribution + slower signals
       insulating material
  L4  components + remaining signals
outside
```

The complete material and thickness definition is the **stack-up**. The board fabricator supplies supported stack-ups. Trace geometry and its nearby reference plane together determine impedance for fast interfaces, so do not invent a stack-up after routing.

For Mochi's first custom carrier, the decision is a four-layer board with a mostly continuous ground plane on layer 2. Four layers cost more than two, but make power distribution and predictable return paths much easier. This is especially valuable around audio, USB, radios, and bursty loads.

### A plane is just a large copper region

A **ground plane** is a broad sheet of copper connected to `GND`. It reduces the resistance and inductance of the shared return path and gives fast-changing signals an adjacent reference.

A **power plane** is a broad copper region for a supply such as `3V3`. It can carry more current with less voltage drop than a narrow trace, although its exact capacity still depends on copper thickness, geometry, temperature, vias, and airflow.

## 7. Return paths: every outgoing current comes back

This is the most important physical idea in board layout.

When a signal changes, current travels out through its signal conductor and returns through some path, usually the nearby ground plane. The circuit is a loop:

```text
driver ---- outgoing trace ---- receiver
  ^                                |
  `------- nearby GND return ------'
```

At low frequency, current tends toward paths with low resistance. As edge speed increases, the return current tends to stay close beneath the outgoing trace because that loop has lower impedance. **Edge speed**, not merely how often messages are sent, makes a digital trace electrically fast.

If the outgoing trace crosses a gap in its ground reference, the return current must detour:

```text
good:  signal  -------------------->
       GND     =====================

bad:   signal  -------------------->
       GND     ======= gap ========
                         ^ return detours, loop grows
```

The larger loop can radiate more noise, receive more interference, and distort the signal. Therefore:

- keep the ground plane continuous beneath USB and other fast signals;
- do not split the reference plane under a fast trace;
- use nearby ground vias when a signal changes layers and its return needs to follow; and
- keep high-current loops short and wide so their voltage drops do not disturb audio or logic.

Ground is a shared reference and a return conductor, not a hole into which current disappears.

## 8. Decoupling: a tiny local energy buffer

A microcontroller does not draw perfectly steady current. Millions of internal transistors switch, creating very short current demands. A long path back to the regulator cannot respond instantly because every trace has some resistance and inductance.

A **decoupling capacitor** is placed between a component's supply pin and ground, physically close to those pins:

```text
regulator ---- 3V3 trace -----------+---- integrated-circuit supply pin
                                    |
                                  [ C ]  decoupling capacitor
                                    |
GND plane --------------------------+---- integrated-circuit ground pin
```

During a fast demand, the capacitor supplies some current through a very small local loop. The regulator replenishes it afterward. A software analogy is a small local cache in front of a slower backing service. The analogy stops at sizing: a capacitor's value, construction, voltage bias, placement, and loop inductance all matter.

Practical rules:

- start with the component vendor's reference schematic and layout;
- place each small ceramic decoupling capacitor next to the supply pins it serves;
- route its supply-to-capacitor-to-ground loop with short, wide copper and a close ground via;
- add larger **bulk capacitance** near loads that change current more slowly, such as a modem; and
- do not treat a large capacitor as a substitute for a capable battery, regulator, connector, or power path.

Capacitor values are not universal decoration. Follow the exact regulator, codec, compute-module, and modem documentation, then verify the rail with measurements.

## 9. Mochi's first carrier board: what is intentionally modular

Mochi's first custom board is a **carrier**: it connects already-tested modules and implements product-specific power, controls, audio, connectors, and test access. It does not put a bare cellular modem chip and a custom radio-frequency path directly on revision A.

That decision limits the number of new problems introduced at once. A bare cellular modem would add fine-pitch assembly, multi-amp transient power, subscriber identity module protection, high-speed USB, radio-frequency feed geometry, antenna matching, regional variants, and carrier approval simultaneously.

The first carrier should preserve these Mochi decisions:

- use four copper layers with a mostly continuous ground plane;
- keep the large SIM7600G-H board as an external cellular bench mule, then choose an exact smaller replaceable modem module before enclosure commitment;
- prove the exact compute-to-modem interface before freezing the carrier;
- use one fail-low capture-enable command that also drives the cyan listening indicator;
- use a latching power switch that physically de-energizes the system and prevents USB, debug, or modem connections from back-powering it;
- expose labelled test access for power rails, reset, boot, programming, slow buses, and modem controls; and
- avoid casual test-pad stubs on USB differential pairs or future radio-frequency traces. Those need impedance-safe probe structures reviewed with the stack-up.

The finished product has exactly two physical controls: conversation start/stop and power. Temporary development connectors and test points are instrumentation, not extra user controls.

See [architectural decision record 0005 — Build a modular carrier before integrated radio frequency](../docs/decisions/0005_build_modular_carrier_before_integrated_rf.md) and [architectural decision record 0008 — Use exactly two physical controls](../docs/decisions/0008_use_exactly_two_physical_controls.md).

## 10. From layout files to an assembled board

Two different businesses may be involved:

1. A **board fabricator** makes the bare PCB: copper, insulation, drilled holes, solder mask, and printed labels.
2. An **assembler** applies solder paste, places components, heats the board in a reflow oven, adds special hand-soldered parts, inspects it, and may program or test it.

Some vendors provide both services. A low bare-board quote does not include components or assembly.

### What the colored board features are

| Feature | Purpose |
|---|---|
| Copper | Carries current and signals |
| Plated hole or via | Connects copper layers; some holes also hold component leads |
| Solder mask | Insulating coating that exposes only intended solder areas |
| Silkscreen | Printed reference names, polarity, warnings, and board identity |
| Surface finish | Protects exposed pads and makes them solderable |

### Manufacturing outputs

| Output | Plain-language purpose |
|---|---|
| Gerber or ODB++ files | Geometry for each copper, solder-mask, and silkscreen layer |
| Drill files | Hole locations, sizes, and plated/non-plated intent |
| Bill of materials (BOM) | Exact manufacturer part numbers, quantities, references, and approved substitutions |
| Component placement list (CPL) | X/Y position, rotation, and board side for each machine-placed part |
| Assembly drawing | Human-readable polarity, orientation, special handling, and do-not-fit notes |
| Stack-up and impedance notes | Required layer construction and any controlled trace geometry |
| Test specification | What should be powered, programmed, measured, or inspected before shipment |

Open the generated fabrication files in an independent viewer. Check that the outline, holes, copper, text, and solder-mask openings match the source design. Generated files are release artifacts; keep them tied to a source revision and exact BOM.

### Three reviews with different questions

- **Design for manufacture (DFM):** Can the fabricator reliably make these trace widths, gaps, holes, clearances, and layers?
- **Design for assembly (DFA):** Can the assembler orient, place, solder, inspect, and rework the selected components?
- **Design for test (DFT):** After assembly, can we safely measure important rails and control signals and program the board?

These acronyms are not paperwork for its own sake. They are three attempts to make failures observable before ordering boards.

## 11. Test points are hardware observability

Test points are the hardware equivalent of logs, metrics, and debugger attachment points. Add them while designing; they are difficult to add after a failure.

For the modular Mochi carrier, provide accessible, labelled points for:

- ground clips;
- battery input and every regulated power rail;
- reset, boot, and programming signals;
- the capture-enable/cyan-indicator command and the actual gated microphone rail;
- appropriate low-speed buses and interrupts;
- modem enable, reset, and power control; and
- current-measurement jumpers or zero-ohm links around major load branches.

Do not put them under an installed battery or another module. Do not add ordinary branch stubs to radio-frequency or USB traces just to fit a probe; fast-net observability must be designed with signal integrity in mind.

## 12. Beginner pre-order workflow

### The current KiCad project workflow

In current KiCad projects, the `.kicad_pro` file stores project settings, `.kicad_sch` stores the schematic, and `.kicad_pcb` stores the physical board. Keep them together in version control.

Use this tool sequence:

```text
Create project
  → draw and annotate schematic
  → select and verify exact footprints
  → run ERC and manually review the circuit
  → update PCB from schematic
  → configure stack-up and fabricator design rules
  → define outline and place components
  → route traces and fill copper zones
  → run DRC and manually inspect return/power paths
  → inspect 3D and print at 1:1
  → generate Gerbers, drills, BOM, and required placement data
  → inspect manufacturing outputs independently
```

ERC is the **electrical rules check** for declared schematic relationships. DRC is the **design rules check** for configured board geometry. Neither determines whether a resistor value is sensible, a regulator handles a transient, a connector is viewed from the correct side, or a chosen footprint matches the ordered part.

Configure board clearances, widths, holes, vias, annular rings, copper-to-edge limits, and stack-up from the selected fabricator before routing. Defaults are not a manufacturing contract. For practice, follow [Lab 1](labs/0001_led_button_board.md) and [Lab 2](labs/0002_module_carrier_board.md) rather than beginning with the complete Mochi board.

Perform this workflow before paying for assembly:

1. **Freeze measured interfaces.** Record the exact module, connector, cable, voltage, current, pinout, and host/device role used on the bench.
2. **Draw the power tree.** List every rail and each load's typical and peak current. Treat initial numbers as estimates until measured.
3. **Capture the schematic.** Use exact manufacturer part numbers and documented alternates.
4. **Run ERC.** Resolve every warning; then manually review connector direction, polarity, voltage domains, boot pins, and power-off paths.
5. **Verify footprints.** Compare pin numbers and dimensions with each datasheet and actual large parts.
6. **Bench-test risky circuits.** Validate charger, regulator, fuel gauge, power path, protection, and capture gate before copying them onto the carrier.
7. **Place from constraints.** Begin with mechanics, antenna keep-outs, audio, connectors, and high-current loops.
8. **Route and run DRC.** Inspect return paths and power widths manually; a passing DRC is necessary but not sufficient.
9. **Review in 3D and at 1:1.** Check enclosure clearances, cable exits, button access, battery space, and assembly order.
10. **Generate and inspect outputs.** View fabrication files independently and reconcile the BOM and placement list.
11. **Ask for DFM/assembly review.** Do this before ordering, and approve every component substitution deliberately.
12. **Order a learning quantity.** Mochi's plan is 5–10 assembled carriers plus two bare boards. Expect a second revision.

A revision that produces a clear measurement and an unambiguous correction is useful engineering, not failure.

## 13. Bring-up: first power without the smoke

**Bring-up** is the controlled process of turning a newly assembled board into a known-working system. Do not attach the battery, modem, display, audio, and USB simultaneously and hope.

Useful equipment:

- schematic and board layout on-screen;
- magnifier or microscope and bright light;
- digital multimeter with sharp probes;
- current-limited bench power supply;
- USB programmer/debugger and a known-good data cable;
- oscilloscope for startup droop, ripple, clocks, and fast faults;
- temperature probe or thermal camera if available; and
- insulated tweezers and appropriate soldering/rework tools.

Use eye protection and a nonflammable work surface. Stop if a lithium cell swells, heats unexpectedly, leaks, or is physically damaged. Do not learn battery-pack construction by experimenting on the product board.

### Bring-up sequence

1. **Record identity.** Photograph both sides and record board revision, serial number, BOM variant, and assembler substitutions.
2. **Inspect unpowered.** Look for solder bridges, missing parts, shifted packages, reversed diodes/capacitors, and connector damage.
3. **Check rails against ground.** Measure resistance from each power rail to ground and compare boards. A brief low reading that rises can be a capacitor charging from the meter; investigate rather than relying only on the continuity beeper.
4. **Remove optional loads.** Leave the modem and other replaceable modules disconnected.
5. **Apply current-limited power.** Start with the documented voltage and a conservative current limit. If the limit engages or a part heats, switch off and investigate.
6. **Measure the power tree.** Confirm each rail at its test point, in dependency order, and record current draw.
7. **Check reset and boot.** Confirm reset level and clocks where appropriate; then flash minimal diagnostic firmware.
8. **Exercise one interface at a time.** Test a button, display, microphone, speaker, storage, and network module separately before combined load.
9. **Verify privacy hardware.** Across reset, crash/watchdog, recovery, and firmware update, prove capture remains gated until an authenticated live session asserts the coupled cyan command.
10. **Verify true power-off.** With the latching switch off, connect battery/charger, USB, debug, and modem paths one at a time. Neither the system nor microphone rail may rise through back-power.
11. **Add the modem last.** Use the instrumented external mule first and measure its burst power separately.
12. **Run combined stress tests.** Only after blocks pass alone, run full-duplex audio, display/caption animation, network traffic, charging, and weak-network tests together.

## 14. What to measure and write down

Use a table, not memory. Initial targets are hypotheses until measured on the exact board.

| Test | Tool | Probe location | Evidence to save |
|---|---|---|---|
| Unpowered rail-to-ground resistance | multimeter | each rail test point to a labelled ground point | stable value or time behavior, per board |
| Regulated rail voltage | multimeter | at the load and regulator output | minimum/typical/maximum across modes |
| Startup and load-step droop | oscilloscope | directly at the affected component supply pins with a short ground connection | screenshot, trigger condition, lowest voltage |
| Total and branch current | bench supply/current measurement point | board input and major load branches | off, boot, idle, listening, speaking, charging |
| Capture gate | oscilloscope or multimeter | command, indicator, and microphone rail | reset/boot/live/stop/crash timing |
| Power-off isolation | multimeter | system and microphone rails | voltage/current with each external cable attached |
| Component temperature | temperature probe | regulator, charger, amplifier, modem connector region | ambient, operating mode, peak and steady state |
| Interface behavior | debugger or suitable instrument | test points defined for that bus | pass/fail, rate, errors, and firmware revision |

Probe the component pins or nearest intended test point when investigating power integrity. A measurement at the bench supply can hide a voltage drop in the cable, connector, fuse, switch, or trace.

## 15. Prototype, design validation, and production validation

Teams often separate hardware maturity into:

- **Engineering validation test (EVT):** Does the architecture and engineering work?
- **Design validation test (DVT):** Does a near-product design work across enclosure, environment, radio, compliance pre-scan, and reliability conditions?
- **Production validation test (PVT):** Can the factory build and test it repeatedly with acceptable yield?

The names vary between organizations. The important idea is that a working hand-built prototype does not prove that a factory can make thousands safely and consistently.

## Self-check

Try to answer without looking back:

1. What is the difference between a schematic net and a copper trace?
2. Why can a correct symbol with the wrong footprint pass automated checks but fail physically?
3. Why does a fast signal need a nearby return path?
4. What does a decoupling capacitor do, and what can it not repair?
5. What is the difference between PCB fabrication and PCBA assembly?
6. Why should a new board be powered from a current-limited supply before attaching all modules?
7. Which Mochi functions must remain off when its latching power switch is off?

### Answer check

1. A net states which pins must share an electrical node; a trace is one physical piece of copper used to implement that connection.
2. The symbol and automated net checks describe logical pins, while the footprint controls real pad position, size, numbering, and mechanics.
3. Current always completes a loop; a nearby return keeps loop area and impedance small, reducing noise and signal distortion.
4. It supplies brief local current and keeps the supply stable at the load. It cannot make an inadequate battery, regulator, connector, or long resistive path adequate.
5. Fabrication makes the bare layered board; assembly solders components onto it and may inspect, program, and test it.
6. Current limiting confines the energy available to an unknown short or wrong part and makes faults easier to observe one rail at a time.
7. The entire system, including the microphone rail, must be physically de-energized; USB, debug, charger, or modem connections must not back-power it.

Next, [0004 — Cellular, radio-frequency, power, and certification](0004_cellular_rf_power_and_certification.md) applies these board and measurement ideas to the most electrically demanding optional module in Mochi.

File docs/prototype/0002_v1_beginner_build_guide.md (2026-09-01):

# 0002 — V1 beginner prototype build guide

Status: Ready for the first software and hardware bring-up
Date: 2026-08-31

This guide turns the existing Mochi Pager design into the smallest useful first build. It deliberately proves the conversation experience on a laptop before moving it to the purchased M5Stack CoreS3 K128. No soldering, custom PCB, external battery, cellular modem, BLE provisioning, or mobile app is needed for this build.

The repository originally selected the CoreS3 Lite as the interaction mule. The unit actually purchased is the full CoreS3 K128. Its screen, ESP32-S3, memory, Wi-Fi/BLE, and audio path cover the same first experiments, so **use the K128 already purchased and do not buy a second CoreS3 Lite**. See [ADR 0001](../decisions/0001_use_esp32s3_interaction_mule.md) and the [staged BOM](../research/0001_component_sources_and_bom.md).

## What this first build proves

The build has two deliberately separate checkpoints:

1. **Day-2 interaction/device simulator on the laptop:** run a local gateway and browser UI, start one live full-duplex session, talk without pressing for each turn, interrupt the assistant by speaking, and see an assistant caption slide below the face.
2. **CoreS3 incoming inspection and stock bring-up:** confirm the purchased board, cable, display, touch, microphones, speaker, and Wi-Fi are healthy before replacing vendor firmware. The face, caption, and live-audio path move to this board only after the browser checkpoint works.

Passing the browser checkpoint is not proof of CoreS3 audio, acoustic echo cancellation (AEC), battery life, embedded performance, or product privacy hardware. Passing the stock CoreS3 checks is not yet the complete pager. These two inexpensive checkpoints remove different kinds of uncertainty.

## Control boundary: exactly two in the product

The product still has exactly two physical controls:

1. An illuminated conversation button: press once to start listening; press again to stop.
2. A latching power slide switch: physically on or off.

The first development build uses temporary substitutes:

| Build stage | Conversation control | Power control | What this means |
|---|---|---|---|
| Laptop simulator | One on-screen `Start listening` / `Stop listening` button | Laptop power is outside the simulated pager | The on-screen button tests the interaction contract; it is not a third product control. |
| Stock CoreS3 bring-up | Touchscreen action may temporarily stand in for the conversation button | CoreS3's stock PMIC power button | Both are development-mule substitutes. The stock PMIC button is not the final latching hard-off switch. |
| Later product-like mule | One illuminated physical conversation button | One latching physical power slide switch | This is the required two-control product arrangement. |

Do not add volume, push-to-talk, reset, or mode buttons. Development settings can live on the laptop or touchscreen. The normal conversation control never becomes hold-to-talk; if full duplex fails, record the failure instead of quietly changing the interaction.

## Exact shopping list for this build

### Required electronics

| Qty | Item | Status / observed cost | Notes |
|---:|---|---|---|
| 1 | M5Stack CoreS3 K128 | Already purchased for $77.90 on 2026-08-31 | Use this board; do not also order the Lite. The price is a historical receipt value, not a current quote. |
| 1 | Known-good USB-C **data** cable | Existing cable or $5–10 observed | A charge-only cable can power the board while making it look unflashable. Mark a proven data cable. |
| 1 small piece | Removable opaque sticker or nonconductive tape | Use an existing supply; verify price before buying | Cover the camera aperture during EVT. This physical cover does not replace disabling camera initialization in later firmware. |

If the cable is already available, no further electronics order is needed for this first build. Prices, stock, tax, and shipping can change; verify them before any purchase. OpenAI API usage is separate and is not estimated here—check current pricing, create a dedicated project, and set a conservative usage alert/limit before the first live session.

### Equipment and access to prepare

These are required but are not pager BOM parts:

- A laptop running Node.js 20 or newer, with Git and a current browser.
- A working laptop microphone and speaker.
- A normal Wi-Fi network with internet access and credentials you are allowed to use.
- An OpenAI API project and API key stored only in the local gateway environment.
- A clean, dry, nonconductive work surface with good lighting.
- A notebook or text file for the board label, test date, pass/fail results, and observations.

### Optional now

- A phone and hotspot plan for one mobile-backhaul comparison after normal Wi-Fi works.
- Wired headphones for diagnosing laptop echo. Headphones can isolate a software problem, but they do not prove the eventual pager's speaker/microphone AEC.
- A second known-good USB-C data cable for comparison if enumeration fails.
- A phone camera for recording the face, caption, and interruption test.

### Explicitly deferred—do not buy for this build

- External digital microphone, I²S amplifier, speaker, breadboard, illuminated button, and latching switch. These are ordered only after the CoreS3 concurrent-audio baseline passes and its accessible pins are confirmed.
- SIM7600G-H or any other 4G/5G modem, SIM/data plan, LTE antenna, or Starlink hardware. A phone hotspot comes first; standalone cellular is a later Gate B experiment.
- Final battery, charger, power-path board, or loose LiPo cell.
- Custom display, custom PCB, production enclosure, GPS/GNSS module, or 3D print.
- Soldering station, oscilloscope, logic analyzer, or bench supply. None is needed for the no-wiring first build. Borrow/rent appropriate instruments when a later measured gate actually calls for them.
- Mobile-app or BLE-provisioning hardware. Those are later software tracks and add nothing to this shopping list.

## Preflight safety and privacy check

Before plugging in the CoreS3:

- Inspect the enclosure and USB connector. Do not power a crushed, cracked, wet, swollen, punctured, leaking, unusually warm, or chemically smelling unit.
- Do not open the CoreS3, remove battery insulation, solder to its cell, or replace its internal battery during this build.
- Work on a nonconductive surface, away from loose metal, liquid, and flammable clutter.
- Cover the camera aperture with removable opaque material. Later device firmware must also omit camera driver/clock initialization.
- Start speaker volume low to protect hearing and reduce acoustic feedback.
- Charge and test while present. If the board or battery becomes abnormally hot, swells, smells unusual, or behaves erratically, disconnect USB if it is safe to do so and stop using it.
- Keep the standard OpenAI API key only in the laptop's `.env`. Never paste it into browser code, CoreS3 firmware, screenshots, logs, chat, or a Git commit.
- Treat cyan/live as “microphone audio may leave the machine.” Use the stop action before discussing anything private, and close the page/server after testing.

No cellular antenna, bare battery, mains wiring, or exposed speaker-amplifier output is involved in this build.

## Part 1 — Run the laptop interaction/device simulator

The simulator is the fastest way to check the live-conversation design. It uses the laptop microphone/speaker and a local session broker. The standard API key remains on the server side; with the selected unified WebRTC flow, the browser sends its SDP offer to that broker and receives only the SDP answer—not the standard API key or a client credential.

### Step 1: verify Node.js

Open a terminal and run:

```bash
node --version
npm --version
```

The Node.js major version must be 20 or newer. Install or update Node before continuing if it is older or the commands are missing.

### Step 2: enter the repository

```bash
cd /home/jaewoo-jang/Desktop/Projects/Pager
```

Run the remaining commands from this directory.

### Step 3: create the local environment file

```bash
cp .env.example .env
```

Open `.env` in a text editor and find this line among the documented defaults:

```dotenv
OPENAI_API_KEY=replace_me
```

Replace only `replace_me` with the real key from the dedicated API project; the server intentionally refuses to run a live session while the placeholder remains. Do not add quotes unless the example file asks for them. Save the file, close the editor, and never commit `.env`. The prototype has zero runtime package dependencies, so no `npm install` step is required.

### Step 4: run the automated checks

```bash
npm test
```

Do not move on if a test fails. Copy the complete error into the test notebook, check the Node version, and try the basic fixes in the troubleshooting section.

### Step 5: start the local gateway and UI

```bash
npm start
```

Leave that terminal open. Open this exact address in a current browser:

```text
http://localhost:3000
```

Use `localhost`; do not open the HTML file directly with a `file://` URL. The first page should show the Mochi face, one conversation start/stop control, and a private/idle state. The caption position below the eyes is intentionally invisible while empty: there is no “Captions appear here” prompt, border, or tinted panel.

Before starting, confirm that both dark pupils are centered inside calm ivory eyes with subtle outer-eye motion. The first large idle gesture should begin after 3–5 seconds. After it returns to center, later gestures wait 6–12 seconds. Both pupils and apertures move together: they may look up, down, side to side, toward any of four screen corners, or make a 1.6–2.4 second clockwise/counterclockwise scan, and every path ends at center. The injected-randomness tests cover every gesture family and both timing bands, so a short manual watch need not sample them all. There is no mouth.

Face animation is optional: the conversation button is wired first, and a failed animation import or initialization leaves a static centered face rather than breaking Start/Stop. A later cosmetic fault likewise cannot remove that already-wired control. Enable the operating system/browser reduced-motion preference and reload once: idle gestures should stop and poses should become static. Turn that preference back off for the remaining motion test if desired. If the browser exposes the optional Battery Status API, a low host battery intentionally produces a dim, downward, less-active face; otherwise automated tests are the V1-A battery evidence. The CoreS3 port will use its PMIC/fuel gauge instead.

### Step 6: start one live session

1. Press `Start listening` once.
2. Allow microphone access when the browser asks.
3. Check that the UI shows a connecting state before a live state. Microphone capture must not be presented as live while connection setup is incomplete.
4. Say a short sentence, then stop speaking naturally.
5. Listen for the assistant response and watch its first words slide in from beyond the right edge at one steady, deliberately slow speed. Short and long captions use the same entrance. The visual caption may trail audio/token arrival and queue new text ahead, but arriving words must not restart, ease, or change the track's speed.
6. Continue for at least ten short exchanges without pressing once per utterance.

The microphone remains available while assistant audio plays. That simultaneous input/output behavior—not alternating turns—is the experiment.

Watch the face as well: listening draws the pupils attentively inward, thinking uses one side-to-side saccade sequence, and assistant speech changes the subtle alive rhythm. A model-selected allowlisted emotion should change aperture height, width, tilt, spacing, asymmetry, pupil size, and motion without speaking or captioning its control metadata. Starting speech must immediately cancel any large idle gesture, while the cyan/amber/off indicator remains the only listening truth.

### Step 7: test voice interruption

While the assistant is speaking, say a clear new sentence such as “Wait—let me correct that.” The audible assistant output should stop promptly, should not resume from the cancelled response, and the caption should not continue presenting unheard words. Continue speaking without pressing the button again.

This first pass is an observation, not the final 250 ms p95 barge-in measurement. The cancelled caption should disappear immediately rather than continuing its slow crawl. Record whether interruption felt immediate, whether the laptop heard its own speaker, and whether any old audio or caption text returned.

### Step 8: stop locally

Press `Stop listening` once while the assistant is idle, then repeat during assistant playback:

- Microphone capture and assistant playback should stop locally.
- The UI should return to private/idle.
- Talking afterward should not create a response.
- A page refresh or server restart must not automatically resume listening.

Stop the development server with `Ctrl+C` in the terminal when finished.

### Step 9: make the optional hotspot comparison

Only after the normal Wi-Fi session works:

1. Stop the conversation.
2. Connect the laptop to a phone hotspot.
3. Start the server/session again and repeat a short conversation plus one interruption.
4. Record the phone, carrier, location, and whether the phone reported LTE or 5G, if visible.

This tests the experience through that phone's mobile backhaul. It does **not** validate a pager modem, SIM/APN, LTE power bursts, antenna, cellular failover, BLE provisioning, or Starlink Direct to Cell.

## Part 2 — Inspect and baseline the CoreS3 K128

Do this when the purchased unit arrives. Preserve the vendor firmware until the baseline is recorded; otherwise a firmware bug and a delivery fault are hard to distinguish.

### Step 1: inspect before power

1. Photograph the sealed package and the board from all sides.
2. Record the exact product marking, board revision/serial information that is safe to retain, package contents, and arrival date.
3. Confirm the received unit is the expected full CoreS3 K128. Record whether its base module is present and the battery capacity marked by the vendor; do not infer package contents from an online listing.
4. Check the enclosure, screen, USB-C connector, and seams for shipping damage.
5. Apply the removable opaque camera cover without blocking the display, microphones, speaker, ventilation, or controls.

Stop and contact the seller if the hardware is materially damaged or is the wrong model.

### Step 2: connect without modifying hardware

1. Put the CoreS3 on the nonconductive surface.
2. Connect the proven USB-C data cable to the laptop, then to the CoreS3.
3. Follow the vendor-supported stock power-on behavior. Do not pry the case, attach GPIO wires, or flash new firmware yet.
4. Watch for abnormal heat, odor, repeated resets, display corruption, or USB disconnect/reconnect loops.

For this mule only, its stock side PMIC button is the temporary power control. It does not demonstrate the final latching switch or hardware-certain hard-off requirement.

### Step 3: run the stock-function checklist

Using the vendor image or supported examples, record pass/fail for:

- Display powers on with no missing regions or persistent corruption.
- Touch input responds across the useful screen area.
- Both microphones produce a detectable input in the available stock diagnostic/example.
- Speaker produces clean, low-volume output.
- Wi-Fi can see and join the intended test network.
- USB data connection appears reliably on the laptop.
- Charging/power indication behaves normally with no abnormal heat.
- Camera remains physically covered; do not use a camera feature as part of MVP validation.

If an available stock image does not expose one test, write “not yet tested”; do not convert absence of a test into a pass.

### Step 4: preserve the baseline

Record:

- CoreS3 model and observed revision.
- Laptop operating system, Node version, browser version, and later embedded toolchain version.
- USB cable used.
- Wi-Fi network type, without writing its password into the notebook or repository.
- Results and photographs for each stock-function check.
- Any resets, heat, audio distortion, touch dead zones, or cable sensitivity.

Only after this baseline should the project replace vendor firmware and port the face/caption state machine. That embedded port is the next implementation step, not a hidden requirement for completing the laptop checkpoint.

## Recommended bring-up order after these two checkpoints

Keep this order; each item removes one uncertainty before the next is added:

1. Port only the face, parallel session states, one touchscreen start/stop substitute, and sliding caption to the CoreS3.
2. Verify 30 fps UI and prompt response while offline. Power-on must remain private/idle.
3. Prove local simultaneous microphone capture and speaker playback using the CoreS3's synchronized audio/reference path.
4. Add and measure AEC before connecting live model audio.
5. Run Espressif's direct WebRTC/OpenAI reference path using a short-lived client credential minted by a server that retains the standard key. Treat this as the canonical V1-B media reference, not the final product gateway.
6. Connect the real Realtime session and repeat start, ten exchanges, voice interruption, caption clear, and stop. On the K128, also record the active response/output IDs, rendered-caption cursor, first-caption latency, one-segment lead limit, completion exit, immediate interruption clear, reliable heard-boundary accounting, and 2-inch legibility required by PR-07.
7. After the direct reference works, stream known audio through the ADR 0003 product-gateway adapter in both directions and compare its added latency. Do not make the beginner's first device conversation depend on finishing account/history/tool infrastructure.
8. Only after those pass, consider the product-like illuminated button, latching power switch, relocatable acoustic parts, and temporary enclosure.
9. Only after the enclosed Wi-Fi gate passes, decide whether to buy the separate cellular mule.

BLE onboarding, the mobile app, cloud history sync, physical SIM/APN configuration, and cellular failover remain later tracks. For this build, Wi-Fi credentials can be development configuration; do not present that as the final onboarding design.

## Acceptance checklist

### Laptop interaction/device simulator

- [ ] `npm test` passes on Node.js 20 or newer.
- [ ] `npm start` serves `http://localhost:3000` without exposing the standard API key to browser source or logs.
- [ ] The first screen is private/idle and does not capture automatically.
- [ ] With normal battery/motion settings, the dark pupils begin centered in ivory eyes with subtle continuous outer-eye motion, start a first synchronized large gesture after 3–5 seconds, return to center, and use 6–12 second pauses thereafter. Automated tests cover look-up, look-down, all four corners, side-to-side look-around, clockwise/counterclockwise scan selection, and conversation cancellation.
- [ ] Start/Stop remains independent of the optional face controller; automated receiver/load-order checks verify that import or initialization failure leaves a static centered fallback and that later cosmetic faults cannot remove the already-wired conversation control.
- [ ] Reduced-motion preference suppresses curious idle gestures. If the optional browser battery API exposes a low state, verify its subdued face; otherwise rely on the deterministic low/critical/charging tests. Battery treatment never changes or impersonates the capture indicator.
- [ ] The face contains exactly two large round eyes and no mouth or lips; attentive, thinking, and speaking cues remain visually distinguishable, and battery cues do too when the host exposes a battery signal.
- [ ] The empty caption position is transparent, with no placeholder text, border, or colored panel.
- [ ] There is one visible conversation start/stop control, not per-turn push-to-talk.
- [ ] Start visibly moves through connecting to live.
- [ ] At least ten exchanges work without another button press.
- [ ] The user can speak while assistant audio is playing.
- [ ] Clear near-end speech interrupts assistant playback and cancelled audio does not resume.
- [ ] A sliding assistant caption is directly below the face; its first text enters from beyond the right edge and moves left at a fixed 60 CSS px/s without easing or per-word speed changes, and transcript additions queue ahead without retargeting that motion.
- [ ] Completed playback keeps the caption moving left at 60 CSS px/s until it is fully beyond the left edge; it never reverses toward the right. Interruption clears it immediately; caption reset snaps to its zero position; with the browser/OS reduced-motion preference enabled, position changes snap rather than animate; and late cancelled text does not return.
- [ ] Stop during idle and stop during playback both return locally to private/idle.
- [ ] Talking after stop creates no response.
- [ ] Refresh/restart does not auto-start capture.
- [ ] A ten-minute basic session completes without a stuck state or stale playback.
- [ ] `.env`, keys, raw audio, and secrets are not committed or copied into test artifacts.
- [ ] Prompt tests pass: the `.ftl` begins `You are a companion`, server-rendered fixture context reaches the Realtime session configuration, and browser SDP cannot override it. The localhost defaults do not claim real account history or personalization.

### CoreS3 incoming baseline

- [ ] Received model/package contents are recorded rather than assumed.
- [ ] No visible damage, battery warning sign, abnormal heat, or unstable USB power is present.
- [ ] Camera aperture is opaquely covered.
- [ ] Known-good USB-C data cable enumerates reliably.
- [ ] Display, touch, microphone, speaker, and Wi-Fi checks are recorded as pass/fail/not-yet-tested.
- [ ] Vendor baseline is preserved before custom flashing.
- [ ] The stock PMIC control and touchscreen are labelled as temporary mule substitutes, not final two-control acceptance.

Completing both lists authorizes the embedded face/audio port. It does not pass the full Gate A acoustic/privacy requirements in [the MVP requirements](../requirements/0001_mvp_requirements.md).

## Common basic issues

| Symptom | First checks |
|---|---|
| `node` or `npm` is not found | Install Node.js 20 or newer, close/reopen the terminal, and repeat the version checks. |
| `npm test` fails immediately | Confirm the command is running from the repository root and capture the first full error, not only its last line. |
| Server reports a missing API key | Confirm `.env` exists beside `package.json`, the name is exactly `OPENAI_API_KEY`, and restart `npm start` after saving. Never print the key to diagnose it. |
| Authentication, quota, or billing error | Check the dedicated API project's key status, budget/usage limit, and current account billing. Do not create a key in browser code. |
| Browser never asks for microphone access | Open the exact `http://localhost:3000` address, check site microphone permissions, close duplicate tabs, and reload. |
| Microphone permission was denied | Re-enable microphone access in the browser's site settings, then restart the conversation. |
| Live session turns red after a microphone is unplugged or revoked | Restore the intended microphone, verify its browser permission/input selection, then press `Start listening` again. The prototype fails closed instead of leaving a false cyan state. |
| Connecting remains amber, then times out | Check internet access and the API project, stop duplicate tabs, and retry once. The prototype closes local media after the bounded readiness deadline. |
| No assistant audio | Check the laptop's selected output, mute/volume, Bluetooth audio routing, and whether another application has exclusive audio control. Start at low volume. |
| Assistant repeatedly interrupts itself | Reduce speaker volume, move the microphone/speaker apart, or use wired headphones as a diagnostic. Record this as an echo/AEC issue; headphones are not a product pass. |
| Caption is blank but audio works | Stop and restart once, then check the gateway/browser console for transcript or data-channel errors. Record the event before changing code. |
| Old speech resumes after interruption | Stop the session. Record the words, timing, and console events; this is a cancellation-generation bug, not normal behavior. |
| Stop button does not silence playback/capture | Close the browser tab and stop the server, then record the failure. Local stop is a required invariant and should be fixed before more testing. |
| Browser works on Wi-Fi but not hotspot | Confirm the laptop truly switched networks, the hotspot permits normal internet traffic, and the API project is reachable. Do not call this pager-cellular validation. |
| CoreS3 powers but is absent from the laptop | Try the proven data cable, another laptop USB data port, and the vendor-supported USB/boot procedure. A glowing screen alone does not prove data connectivity. |
| CoreS3 repeatedly resets | Disconnect nonessential USB devices, use the known-good cable/port, preserve the stock image, and record the visible error. Do not open the case or attach an external battery. |
| CoreS3 becomes unusually hot, swells, or smells odd | Disconnect it if safe, move away from combustible material, stop testing, and contact the seller/manufacturer. Do not recharge or puncture it. |

When a basic fix does not resolve an issue, save the smallest reproducible sequence and stop the dependent step. A clear “not yet tested” or failed checkpoint is more useful than adding unplanned hardware.

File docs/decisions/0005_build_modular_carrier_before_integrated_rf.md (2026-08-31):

# ADR 0005 — Build a modular carrier before integrated RF

Status: Accepted for EVT  
Date: 2026-08-30

## Context

A custom PCB is needed for product geometry, power, controls, testability, and repeatability. Integrating a fine-pitch cellular LGA on the first board would simultaneously introduce RF transmission lines, antenna matching, USB differential routing, multi-amp transient power, SIM ESD, modem firmware, assembly yield, regional SKU, certification, and supply-chain risk.

## Decision

The first custom board is a four-layer modular carrier. It contains the bench-validated power/charger/fuel-gauge architecture, exact compute-module connections, exact audio/display/control connectors or circuits, hardware mute, and an independent recovery/debug path. It has accessible test points on ordinary nets; USB differential pairs and future RF paths use impedance-safe inline/probe structures rather than casual stubs.

The 56 × 65 mm-class SIM7600G-H HAT remains an external bench mule, not an enclosure daughterboard. Before carrier freeze, either select an exact smaller replaceable modem board or explicitly accept an externally tethered LTE demonstration. Prove one exact ESP32-S3 modem transport, host/device role, hardware flow control, reset/power sequencing, and recovery path under simultaneous encrypted voice/display/audio load. A 115,200-baud UART cannot carry 24 kHz mono PCM16 at 384 kbit/s; any UART/PPP path requires measured compression, adequate baud rate, and hardware flow control. “USB/UART” is not a frozen interface.

A later board may integrate LEXI-R10-class cellular by following the chosen vendor reference design exactly and receiving RF/DFM review.

## Why

- The carrier still validates nearly every product-specific mechanical, power, audio, and manufacturing choice.
- Known breakouts preserve modem replacement and make power/RF bugs observable.
- Four layers provide continuous ground and controlled routing at little prototype-volume penalty.
- Assembly yield and bring-up remain tractable for a first board.

## Consequences

- The first custom assembly is not yet the smallest possible pager.
- We need explicit connector, host/device-role, debug, cable, and external-mule budgets.
- A second PCB spin is expected, not considered failure.
- Gate C requires measurements, schematic/ERC review, 3D fit, appropriate low-speed and impedance-safe probe access, current limiting, and manufacturer DFM before ordering 5–10 assembled boards plus two bare boards.

## Amendment — 2026-08-30: full-duplex carrier implications

[ADR 0006](0006_use_button_started_full_duplex_sessions.md) makes the existing “exact audio/control circuits” requirement more specific. The carrier needs synchronized microphone capture and speaker render, a documented post-amplifier analog and/or rendered-digital AEC reference, the illuminated conversation control, and hardware mute. The modem/compute gate now runs simultaneous encrypted uplink/downlink audio, AEC, I²S receive/transmit, and display load; note that 115,200-baud UART cannot carry even one 384 kbit/s PCM direction.

## Amendment — 2026-08-31: concrete Opus numbers change the transport math

Espressif's `esp_audio_codec` managed component (v2.6.2, observed 2026-08-30) ships an ESP32-S3-optimized Opus encoder: 8–48 kHz, CBR 20–510 kbps, complexity 0–10; the registry's measured figure is 24.9% CPU / 29.4 KB at 48 kHz stereo, 90 kbps, complexity 0 on ESP32-S3R8 (16 kHz mono voice is substantially cheaper; raising complexity raises CPU). A 16 kHz mono stream at ~20–24 kbps is ~16–19× smaller than 384 kbit/s raw PCM — roughly 9–11 MB/hour per direction versus 173 MB/hour — which materially changes both the UART/PPP feasibility analysis above and monthly cellular data-plan sizing. The "measured compression" this record demands now has a named default candidate; validate its CPU cost alongside AEC inside the 20%-headroom gate rather than assuming the registry figures.

## Amendment — 2026-08-31: two-control scheme

[ADR 0008](0008_use_exactly_two_physical_controls.md) replaces the separate hardware-mute slider with a two-control scheme. On this carrier that means: one capture-enable command gates the microphone path and drives the cyan indicator so firmware cannot command them independently; component, open/short, and stuck faults can still disagree and must be injected in test. The power slide switch physically de-energizes the system, and the earlier "hardware mute" circuit requirement is superseded by that command coupling. The Day-12 switched-microphone rig remains bench instrumentation for gate/fault-injection measurements.

## Revisit when

Integrate RF only after the cellular mule passes attach/reconnect/data/power/thermal tests, regional/carrier and supply choices are firm, antenna keep-outs fit CAD, and a compliance/RF reviewer accepts the plan.

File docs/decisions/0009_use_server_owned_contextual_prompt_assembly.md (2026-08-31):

# ADR 0009 — Use server-owned contextual prompt assembly

Status: Accepted for EVT
Date: 2026-08-31

## Context

Mochi needs a stable companion identity plus optional past conversation, user facts, device state, and retrieved/search context when a Realtime session begins. Putting prompt assembly in the browser or pager would expose private context, let an untrusted client choose system instructions, and make template/version changes require device releases. Treating history retention as automatic permission to personalize would also violate the separate-consent design in [ADR 0007](0007_use_companion_app_and_cloud_history_sync.md).

## Decision

The trusted gateway owns a version-controlled Realtime instruction template and renders it immediately before session creation. The template begins `You are a companion`, keeps behavioral and privacy rules static, and exposes only five scalar slots: companion name, user context, reconstructed history selected as finalized by the production context service, retrieved/search context, and device/session context.

The file uses `.ftl` and FreeMarker's `${name}` spelling, but the dependency-free V1 renderer intentionally supports only those exact scalar placeholders. It does not execute FreeMarker directives, lists, method calls, JavaScript, or recursively introduced placeholders. Each context category has an allowlisted schema and independent count/size limits; unknown fields, malformed records, several recognizable credential shapes, unsupported template syntax, and an oversized final prompt fail closed. Retrieval URL userinfo, query values, and fragments are stripped. Dynamic data is serialized as JSON and lexically escaped inside labelled context boundaries. This preserves structure but does not make untrusted search or history intrinsically safe, so the static template explicitly labels those blocks as data rather than instructions. Tool authorization and device/capture truth remain code-enforced outside the model.

Only authenticated, binding-current, purpose-authorized records may reach the production renderer. History retention, retained-history prompt context, structured memory, and retrieval/search are distinct permissions. Deletion, account change, release/rebinding, or consent withdrawal removes the affected records and derived retrieval/index/cache entries from future prompt eligibility. The production selector/redactor—not the generic renderer alone—must prove history finalization and exclude raw audio, unfinalized deltas, unheard assistant suffixes, Wi-Fi/cellular credentials, provider keys, and arbitrary secrets. The V1 renderer adds only recognizable-pattern defense in depth. Rendered prompts and private values are not routinely logged.

The localhost V1 has no account or history service. Its defaults therefore say user/history context is unavailable and retrieval was not requested; tests may inject fixtures server-side. The browser continues sending SDP only. Production current-session turns remain native Realtime conversation items; the history block is for bounded reconstruction across sessions, not a duplicate transcript database.

## Why

- OpenAI's Realtime session `instructions` field is the default system guidance for model calls and is therefore the right V1 integration seam.
- Server ownership protects the instruction hierarchy, provider credential, private records, authorization scope, and version rollout.
- A constrained renderer is small enough to audit and preserves the repository's zero-runtime-dependency beginner setup.
- Explicit unavailable/not-authorized states prevent the model from interpreting missing context as a negative fact.

## Consequences

- The gateway gains context authorization/retrieval, template versioning, deterministic rendering, size budgets, and deletion/cache invalidation responsibilities.
- Instruction compliance is guidance, not an authorization boundary or guarantee. Consequential tools still need schema validation, user confirmation, and server policy.
- Context placed in session instructions is processed by the provider and may be visible in session configuration events, so it must contain no secrets and privacy copy must cover that processing.
- The V1 `.ftl` is FreeMarker-compatible only for scalar placeholders; adopting a full engine later requires a new security review and migration tests.

## Revisit when

Revisit the constrained renderer if conditional localization or template composition becomes necessary, or if structured conversation replay can replace cross-session history reconstruction without losing product behavior. Do not expand the template language merely for convenience.

## Primary reference

- [OpenAI Realtime call/session configuration](https://developers.openai.com/api/reference/python/resources/realtime/subresources/calls/methods/accept)

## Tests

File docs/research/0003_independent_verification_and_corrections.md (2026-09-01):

# 0003 — Independent verification and corrections

Status: Verification complete; corrections applied
Observed: 2026-08-30/31

The major load-bearing claims listed below were independently reviewed against live sources by a second reviewer, using parallel research passes whose material findings were then adversarially re-checked (a proposed correction was adopted only when a second, independent fetch of the primary source confirmed it). This document records what held, what changed, and what remains unverifiable; it is not a claim that every sentence in the repository was independently reproduced.

## What held (no change needed)

The original research was accurate on nearly every checked claim, including the obscure ones:

- **OpenAI Realtime**: model IDs `gpt-realtime-2.1` / `gpt-realtime-2.1-mini` (with audio pricing $32/$64 vs $10/$20 per 1M tokens — confirming the mini-as-baseline rationale at a ~3.2× spread), the 60-minute session limit, 24 kHz PCM16 as the only PCM rate (8 kHz G.711 is the sole alternative), `response.cancel`, `conversation.item.truncate` `{item_id, content_index, audio_end_ms}`, `server_vad`/`semantic_vad`, WebSocket-with-standard-key-on-backend guidance, and all six cited developers.openai.com URLs. One watch item: Azure's Realtime deployment still cuts sessions at 30 minutes — relevant only if the backend ever moves there.
- **M5Stack CoreS3 Lite**: exists (published 2025-07-18), SKU K128-LITE, $44.90, in stock; every spec matched (2-inch 320×240, 16 MB/8 MB, ES7210 + AW88298, 200 mAh, 54×54×16.5 mm, GC0308 camera present — so the cover/disable plan is necessary); the 6-second power-button hold; the `m5stack/StackChan` repo and `cores3_audio_codec.cc` (duplex TX/RX on one I²S port, `ES7210_SEL_MIC1|MIC2|MIC3`); and — verified to the schematic level — MIC3P/N connect to nets literally named `AEC_P`/`AEC_N`, coupled from the AW88298 outputs `SPK_VOP`/`SPK_VON`: the speaker-feedback reference is real, post-amplifier, and analog.
- **Cellular**: Waveshare SIM7600G-H HAT price/dimensions/antenna contents/5 V input; the SIM7600 hardware design guide's 3.4–4.2 V rail with 2 A transient requirement; Soracom plan-US $5 SIM with a 1 MB default allocation; Blues Notecard hardware-terms §10.5.3 telephony restrictions; Quectel RM520N ~30×52 mm; RG255C RedCap immaturity; Telit LE910Cx-NF US certification (2019 press release, line still shipping via Sixfab).
- **Small parts**: Adafruit 6049 (ICS-43434, $8.95), 3006 (MAX98357A, $5.95), 3923 (8 Ω 1 W, $1.95), 328 (2500 mAh, $14.95, 50×60×7.3 mm, no thermistor, ≤1.2 A charge); XIAO ESP32S3 $7.49; ReSpeaker Lite $24.90/35×86 mm/XU316/AEC-NS-AGC; Waveshare 27057 $14.99/240×280/33.13×41.13 mm; u-blox MAX-M10 current (GNSS was not part of the Trasna sale).
- **ESP32-S3 audio**: ESP-SR AEC is 16 kHz-only with dedicated full-duplex modes (`FD_LOW_COST` ≈ 19.6% CPU / 30.9 KB internal / 90 KB PSRAM); I²S full-duplex TX/RX sharing BCLK/WS; BLE 5 only, no Classic/A2DP.
- **Reference build audit**: video identity (with `[Satisfying]` prefix, published 2026-08-27), the guide's parts list including the “98357BGA” oddity, binary-only firmware via Google Drive + web.esphome.io with no source/license, xiaozhi.me configuration, and the upstream `78/xiaozhi-esp32` status (MIT, active, 4G precedent).

## What changed (corrections applied)

| Correction | Where applied |
|---|---|
| US prepaid data pricing was outdated: T-Mobile data-only is now $20/5 GB, $30/10 GB (+$25 one-time); AT&T from $35 (15 GB); Verizon from $40 (5 GB); MVNOs $10–15 | research 0001 |
| LEXI-R10 documentation is no longer stale: Trasna product page + R18 datasheet live; NA order code LEXI-R10401D (the module on the MIKROE NA Click) | research 0001 |
| SIM7600G-H annotated: not EOL but previous-generation; uncertified-IMEI T-Mobile rejections documented in the field; cheaper Cat-1 rehearsal (Waveshare SIM7670G ~$28) and certified-modem kit (Sixfab $140, Telit LE910C4-NF) named for Gate B | research 0001 |
| ADR 0003's WebRTC stance was stale: Espressif `esp-webrtc-solution` v1.3.0 (2026-08-26) runs the current Realtime API on ESP32-S3 over WebRTC/Opus/AEC with ephemeral client secrets; OpenAI's embedded repo defers to it. Two revisit triggers fired; the gateway now stands on policy grounds, with a Gate A latency comparison against the direct path | ADR 0003 amendment |
| Concrete Opus numbers added: `esp_audio_codec` v2.6.2, 20–510 kbps CBR; 16 kHz mono voice at ~20–24 kbps ≈ 9–11 MB/h per direction vs 173 MB/h raw PCM — changes UART/PPP feasibility and data-plan sizing | ADR 0005 amendment, edu 0002 |
| ESP-IDF 6.0 renamed provisioning: `wifi_provisioning` removed from core → `network_provisioning` component (v1.2.4); Security 2 is SRP6a + AES-GCM and recommended for production. Security defaults differ across releases, so firmware/app must explicitly compile out or reject Security 0/1 | ADR 0007 |
| The initial Starlink conclusion was too broad. A standard terminal remains only external Wi-Fi, but Starlink now advertises Direct-to-Cell IoT plans through participating carriers and compatibility with suitable Release-10+ Cat-1/Cat-1-bis/Cat-4 modems. It is a conditional carrier experiment, not a generic Starlink APN or MVP dependency | ADR 0002 amendment, research 0001 |
| Realtime conversation state is session-scoped, not a cross-device history database. OpenAI API data is not used for training by default, but default abuse-monitoring logs may retain content for up to 30 days; approved MAM/ZDR changes that posture, while `/v1/conversations` retains application state until deleted and is not ZDR eligible | ADR 0003/0007, design 0002 |
| BLE background constraints and its provisioning RAM cost make it the foreground commissioning/recovery link, not the live-audio or history transport. The gateway is the durable binding/config/history authority; Wi-Fi/APN secrets remain BLE-only | ADR 0007, design 0002 |
| Reference build presumed half-duplex: upstream xiaozhi README ties realtime full duplex to AEC-capable hardware, which the ESP32-C3 + INMP441 + MAX98357A path lacks | research 0002 |
| Switch price drift: JS102011SAQN $0.85, PTS645VL39-2 LFS ~$0.31 | research 0001 |
| Dead UN 38.3 URL replaced with the Rev.8 (2023) + Amendment 1 (2025) page | edu 0004 |
| Reconnect timers made uniformly two-tier: 15 s transport restore (NW-02a) with a deliberately tighter 10 s capture-reopen deadline (NW-02c) now cited consistently in the design narrative, edu 0001, and plan Days 11/13 | design 0001, edu 0001, daily plan |

## What was added (owner requirements that were missing entirely)

Three of the product owner's explicit requirements had no coverage anywhere in the repository; they now do:

1. **Sliding caption below the face** → PR-07, design elements, ADR 0003/0006 caption amendments (driven by `response.output_audio_transcript.delta`/`.done`; optional user captions via `session.audio.input.transcription` with `gpt-live-transcribe`, $0.017/min; the display clears immediately on interruption while the device still computes its heard boundary because the provider does not send a truncated transcript back).
2. **Companion mobile app with BLE provisioning, cellular configuration, and conversation history** → [ADR 0007](../decisions/0007_use_companion_app_and_cloud_history_sync.md) and the detailed [sync architecture](../design/0002_companion_app_and_sync_architecture.md): Security-2 foreground commissioning; BLE-only Wi-Fi/APN secrets; gateway-authoritative binding/config/history; opaque-cursor, idempotent, purgeable history sync; and explicit provider-retention disclosure.
3. **Exactly two physical controls** → [ADR 0008](../decisions/0008_use_exactly_two_physical_controls.md), superseding the mic-kill slider, side volume buttons, and shipping push-to-talk fallback. The conversation button always starts/stops a full-duplex session in normal operation; the power slide switch physically de-energizes the system; a boot-only chord enters capture-gated recovery without transferring ownership.

## Unverifiable (kept hedged, do not treat as confirmed)

- The shared ChatGPT page body (title confirmed; the 95×60×30 mm content renders only for logged-in browsers) — snapshot it.
- xiaozhi.me's “Open Source” tier wording (JS app; not fetchable anonymously).
- The reference build's exact module identities beyond the ESP32-C3 and 0.96-inch OLED (AliExpress links login-gated; item IDs recorded in research 0002).
- The guide's wiring-diagram GPIO assignments (image only).
- platform.openai.com pages return 403 to anonymous fetches (valid for logged-in users; not dead).

Prices and stock were observed 2026-08-30/31 and, as research 0001 already mandates, must be rechecked at checkout.

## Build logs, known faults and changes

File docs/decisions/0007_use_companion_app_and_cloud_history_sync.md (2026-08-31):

# ADR 0007 — Use a companion app with BLE provisioning and opt-in cloud history sync

Status: Accepted for EVT
Date: 2026-08-31

## Context

The product owner requires a separate mobile app that connects to the pager over Bluetooth, lets the user enter Wi-Fi SSID/password, configures cellular ("4G information"), and holds conversation history, with app↔pager synchronization over either P2P/BLE or a central server. No prior record covered this; NW-05 said only "BLE is sufficient for provisioning" without naming a protocol, a security scheme, a claiming flow, or a history home.

Facts observed 2026-08-30/31: ESP-IDF 6.0 removed the `wifi_provisioning` component from core; its successor is the `espressif/network_provisioning` managed component (v1.2.4), with `wifi_prov_*` APIs renamed to `network_prov_*` (some gaining a `wifi_` infix, e.g. `network_prov_mgr_is_wifi_provisioned`). Protocomm Security 2 uses SRP6a plus AES-GCM and is Espressif's recommended production scheme. Security defaults have differed across IDF/component releases, so the product cannot rely on a default. Official Android and iOS provisioning libraries support Security 2. The Improv Wi-Fi BLE standard defines no protocol-level encryption or authenticated key exchange, carries only SSID/password, and has no official iOS SDK. Espressif estimates that keeping BLE provisioning active costs roughly 110 KB of runtime RAM, which argues for a bounded foreground commissioning state rather than an always-on synchronization link.

## Decision

Build one companion app for iOS and Android, and treat it as the second client of the ADR 0003 gateway.

**Provisioning.** Use ESP-IDF unified provisioning over BLE via the `network_provisioning` component with protocomm Security 2 and unique per-device proof-of-possession material written at manufacturing. Manufacturing installs the salt/verifier on the pager and prints only device identity plus the corresponding single-use bootstrap secret in the package QR for first unclaimed setup; initial claim permanently disables that verifier. Keep a separate active-setup salt/verifier; a new on-screen setup secret atomically rotates it with `setup_epoch`, because a verifier cannot regenerate a forgotten secret. Each claim/new binding also creates a fresh binding-scoped recovery secret, stores only its verifier with `recovery_epoch`, delivers it once over Security 2 to the new owner for explicit save/export, and invalidates every prior binding proof. Explicitly compile out or reject Security 0 and Security 1 in both firmware and app; do not inherit an SDK default. In the same encrypted session, add schema- and length-bounded custom endpoints: `/cell-config` (local APN profile), `/claim` (gateway claim token), `/info` (non-secret firmware/network status), and `/network-test`. Values are never logged or readable back. Provisioning runs only in a time-bounded setup/recovery state while capture is gated, never during a connecting, live, or reconnecting conversation. The app must remain foregrounded through the transaction, and BLE is shut down afterward so its approximately 110 KB runtime cost is released. Reject Improv BLE and a from-scratch GATT service because neither meets this authenticated, extensible contract as directly as Security 2. BLE is the sole MVP commissioning transport: generic Wi-Fi Direct is not part of this stack, and SoftAP is deferred unless recovery evidence justifies adding it behind the same setup gate and application-layer Security 2.

**Claiming and recovery.** The user signs into the app first. A factory-fresh pager automatically opens capture-gated setup. A claimed pager may reopen a short setup window from its touchscreen while private-idle. The app can request that window only when the pager is online: an authenticated app→gateway command causes that specific private-idle pager to advertise BLE locally. An offline phone cannot wake a BLE stack that is normally off. Offline recovery uses the boot-only chord in [ADR 0008](0008_use_exactly_two_physical_controls.md): hold the conversation button while sliding power on for eight seconds. A static unit QR may carry device identity and the one-time initial bootstrap proof, but the active setup screen also supplies a fresh, expiring challenge bound to that setup epoch. The factory bootstrap is disabled after first claim, and claimed-device recovery requires the current rotating binding proof, so a photographed factory or prior-owner code cannot authorize later recovery.

After the Security 2 channel is established, the signed-in app obtains a short-lived, audience-bound, single-use claim token bound to the account, immutable device identity, `setup_epoch`, expected current `binding_generation`, and server `claim_nonce`, then writes it to `/claim`. The pager redeems it over TLS using its factory identity. The gateway atomically compares generation/nonce, invalidates all outstanding claim tokens, rotates the nonce, binds the device, advances `binding_generation`, and rejects credentials, streams, or retries from an older generation. Claim, release, recovery, and revoke all rotate the nonce, so an unused old token cannot survive an ownership race. Replays, claims against an already owned unit, and expired/setup-epoch/generation/nonce-mismatched tokens fail without exposing account data.

An unprotected local gesture never transfers ownership. The current owner releases the device in the app. The boot chord plus the current binding's recovery secret may repair local networks, but an owned unit remains unclaimable. For account-loss transfer, a server-side account/support recovery requires both account authorization and physical proof: after the app proves that recovery secret over Security 2, the pager signs a fresh server challenge/request ID, device and requested-account IDs, `setup_epoch`, `recovery_epoch`, expected `binding_generation`, current `claim_nonce`, and expiry with its immutable factory key. Requests are bounded, audited, notify the existing account, and use a policy-defined expiry/cooldown when contact remains possible; numeric values and support authority must be frozen before Gate C. The atomic transfer compare-and-swaps generation/nonce/recovery epoch, invalidates tokens and the old recovery proof, advances all three, revokes old streams, and resets new-owner history retention, retained-history context, and structured-memory consent to off. On observing release or the new generation, the pager closes any live session and purges old binding credentials, working context, captions, media queues, volatile transcripts, config cache, prior recovery verifier, and the prior owner's locally stored Wi-Fi and custom cellular/APN/authentication profile before re-entering capture-gated setup; immutable factory identity remains. The new binding receives a new one-time-delivered recovery secret. The prior owner's cloud history stays in that account. Wi-Fi passwords, custom APNs, PDP-auth credentials, and any future SIM PIN never touch Mochi's cloud.

**Cellular configuration.** "4G information" for this hardware class is a provider profile: APN, IP/PDP type, optional PAP/CHAP username/password, roaming permission, and enable flag (`AT+CGDCONT`/`AT+CGAUTH` on SIMCom-class modems). Public, signed carrier-preset metadata may ship in the app/pager or be downloaded from Mochi cloud; it is not a credential. User-entered/custom APNs, derived profiles, and authentication values remain memory-only in the app, travel over BLE, and live only in the pager's protected credential store. The app discards those values after the pager acknowledges the write.

MVP uses an activated physical SIM with its PIN disabled. Cloud release cannot revoke the subscriber credential on that card: resale release requires explicit confirmation that the SIM was removed or carrier-deactivated, and loss/account deletion direct the owner to deactivate it in the carrier portal. Later PIN support must either prompt after every cold boot or securely persist the PIN; "use once and never store" cannot unlock a power-cycled modem. Do not build a generic consumer SGP.22 eSIM flow. SGP.32 IoT eSIM may be evaluated later with a compatible modem/eUICC, carrier, and eSIM IoT remote manager and must add an explicit profile deactivation/transfer workflow; it is an ecosystem decision rather than an app text field. Standard Starlink remains an external dish/router whose Wi-Fi the pager may use. Direct to Cell is a possible participating-carrier coverage path for compatible Release-10-or-newer Cat-1/Cat-1-bis/Cat-4 hardware and bands, not a universal `Starlink` profile or MVP dependency; [ADR 0002](0002_use_wifi_first_and_4g_lte_failover.md) defines its validation gate.

**Non-secret settings synchronization.** The gateway owns one ordered configuration document scoped to `(account_id, device_id, binding_generation)` and containing monotonic `config_revision`, volume, model/voice profile, prompt-profile version, history-retention consent, a separate retained-history-for-context consent, and the separate structured-memory consent. App and pager mutations carry `client_mutation_id`, the current binding generation, and `If-Match: config_revision`; the gateway either commits the next revision or returns the current document as a conflict. Claim, transfer, or recovery creates a fresh binding document with all three consents off and rejects every older-generation write. The pager clears prior binding-scoped preferences, applies the new defaults, and acknowledges ordered revisions. A touchscreen volume change may apply locally offline but remains pending with its base revision; on conflict the gateway document wins and the pager shows the resolution. Consent changes do not take effect until server commit. Neither client clocks nor last-writer-wins merge decide conflicts. Capture state is never remotely writable: the app cannot start a listening session. Custom network credentials remain outside this document and BLE-only.

**Conversation history.** History is a gateway/cloud-account feature, never a BLE/P2P feature. The gateway is its only durable writer and source of truth; the pager stores no history, and the app keeps only an encrypted authenticated cache. Under an explicit "Save conversation history" opt-in — **default off** and separate from the structured-memory opt-in — the gateway may enable machine input transcription even when user captions are hidden, then transactionally commits user-visible finalized items and an outbox/change record. Raw audio is never retained by Mochi by default.

Saving history does not by itself authorize reuse in later prompts. [ADR 0009](0009_use_server_owned_contextual_prompt_assembly.md) adds a separate, default-off "Use saved history for context" permission. Only then may the gateway select a bounded, finalized, binding-authorized history prefix for a future session; structured user facts still require their own memory consent, and search/retrieval remains purpose-scoped. Consent withdrawal, deletion, account change, release, or rebinding removes affected source records plus derived summaries, search indexes, retrieval caches, and prompt caches from future eligibility. Raw audio, transcript deltas, and unheard assistant suffixes are never eligible.

Every record carries `account_id`, `device_id`, `binding_generation`, UUIDv7 `conversation_id`, gateway-assigned globally unique `history_event_id`, `session_epoch`, provider/device `source_item_id`, account-scoped gateway-assigned monotonic `server_seq`, record `version`, kind/role, finalized machine-transcript text, creation time, and interruption metadata. Before assigning the event ID, the gateway deduplicates source commits on `(device_id, conversation_id, session_epoch, source_item_id, kind)`; phone clocks never order changes. Tool history contains only a user-visible action/status and sanitized result, never arbitrary provider payloads or secrets. For interrupted assistant speech, retain only the reliably heard text prefix; if audio/caption alignment cannot establish that boundary, store an interruption marker without presenting the full generated suffix as heard.

Apps fetch changes after an opaque server cursor and use push/stream notifications only as invalidations before the same cursor fetch. The server publishes `oldest_available_seq`, retains content-free tombstones through the maximum valid cursor age, and rejects any older cursor; that client must authenticate and full-reconcile before showing restored cache. This binds cursor validity to tombstone retention so a long-offline or restored client cannot resurrect deleted content. Delete-item, delete-conversation, and delete-all mutations carry a stable `client_mutation_id` and expected record version, making retries idempotent and stale edits detectable. Turning future retention off is separate from deleting existing history, and retained history remains accessible while future saving is off. Releasing a pager does not implicitly delete its prior owner's retained history, but a new binding can never query it. Offline mutations remain visibly pending until server acknowledgement, and switching accounts immediately evicts the prior account's cache. Structured-memory facts carry their source event IDs; deleting those sources cascades by default, while keeping a separately confirmed fact requires an explicit choice.

The encrypted cache is account-scoped. Its database key is device-bound/non-synchronizing in iOS Keychain or non-exportable Android Keystore-backed storage where supported; authentication tokens use the corresponding secure store, and both cache and key are excluded from OS cloud/device backup. A restored cache is never displayed before authentication and full reconciliation. Offline history display requires a signed, installation-bound authorization lease with server issue/expiry and duration of at most 24 hours, renewable only through authenticated server contact. Same-boot validation uses monotonic elapsed time plus wall time; clock rollback or boot/time discontinuity without rollback-resistant platform time fails closed until contact.

**Account deletion.** Re-authenticated, confirmed deletion immediately revokes and unbinds devices at the gateway, advances their generations/nonces/recovery epochs, closes streams, cancels exports, and deletes Mochi account/config/history/memory content under the published server-side SLA. Connected apps purge caches. A disconnected app cannot be remotely wiped: it may display cache only until the current authorization lease expires, then locks it and erases it on the next server contact that returns an authoritative deletion/revocation or revoked-credential response. Offline pagers are unauthorized at the gateway immediately and, on reconnect, purge binding/recovery state plus local Wi-Fi/custom cellular credentials before capture-gated setup. Privacy copy distinguishes these replica timings, the required carrier-SIM action, and the separately configured provider-retention boundary.

This app history policy covers Mochi-controlled storage, not all provider processing. OpenAI states that API data is not used for training unless the customer opts in, but default abuse-monitoring logs may retain content for up to 30 days; eligible customers may apply for Modified Abuse Monitoring or Zero Data Retention. `/v1/conversations` retains application state until deletion and is not Zero Data Retention eligible, so it is not used as Mochi's product database. User-facing privacy copy must describe the actual approved provider data-control configuration rather than promising zero provider retention. The app↔pager BLE channel carries provisioning and bounded diagnostics only—never conversation content or live audio.

**App stack.** React Native is the cross-platform UI candidate, with thin native bridges to Espressif's maintained iOS and Android provisioning libraries as the authoritative Security-2 implementation. A third-party React Native wrapper may accelerate a spike but is not an architectural dependency until custom endpoints, current Security 2, foreground/background behavior, licensing, and failure recovery pass on both platforms. App source lives in `src/app/`.

## Why

- Security 2 gives a possession-proof key exchange and authenticated encryption with maintained first-party phone libraries; Improv would force plaintext credentials and a custom iOS implementation.
- Cloud history matches how the data already flows (device → gateway → provider). BLE history sync would add a phone-proximity dependency exactly when cellular independence is the point, and the pager deliberately stores no durable history to synchronize.
- Default-off retention preserves the documented privacy stance while satisfying the history requirement for users who want it.
- A claim-token flow, `binding_generation`, and an authenticated transfer/recovery process keep the gateway authoritative over device identity and revocation instead of trusting whatever phone happens to pair.

## Consequences

- The gateway grows a second authenticated client type, account binding generations, optimistic configuration revisions, a transactional history store/change feed, and deletion propagation; these need duplicate, replay, offline, multi-app, and account-switch tests.
- Manufacturing must provision a hardware-protected unique device identity/key and single-use factory-bootstrap verifier. Active-setup and binding-recovery verifiers are generated/rotated at runtime; printed bootstrap material is permanently disabled after first claim and is never a later owner-recovery credential.
- The IDF 6.x rename means pre-6.0 provisioning examples must be read with the `network_prov_*` translation.
- History retention, retained-history prompt reuse, and structured memory become separate user-visible toggles whose off states must be honest; provider retention is disclosed separately according to the account's data-control configuration.
- Network credentials cannot be edited remotely through the cloud; the user and phone must be near the private-idle pager for BLE commissioning.
- The 35-day plan gains a parallel companion-app track that must pass before Gate C freezes the carrier (claiming affects manufacturing data).

## Revisit when

Revisit if Security 2 or the Espressif phone libraries stop being maintained, if account-service requirements outgrow the gateway, if a phone-absent onboarding path becomes a support burden worth adding, or if users demand end-to-end-encrypted history, which would foreclose server-side search and memory features for locked items.

## Primary references

- [ESP-IDF 6.0 provisioning migration (wifi_provisioning → network_provisioning)](https://docs.espressif.com/projects/esp-idf/en/stable/esp32/migration-guides/release-6.x/6.0/provisioning.html)
- [espressif/network_provisioning component](https://components.espressif.com/components/espressif/network_provisioning)
- [Protocomm Security 2 (SRP6a + AES-GCM)](https://docs.espressif.com/projects/esp-idf/en/stable/esp32s3/api-reference/provisioning/protocomm.html)
- [esp-idf-provisioning-android](https://github.com/espressif/esp-idf-provisioning-android) / [esp-idf-provisioning-ios](https://github.com/espressif/esp-idf-provisioning-ios)
- [Improv Wi-Fi BLE specification (no encryption)](https://www.improv-wifi.com/ble/)
- [OpenAI Realtime conversations](https://developers.openai.com/api/docs/guides/realtime-conversations)
- [OpenAI API data controls](https://developers.openai.com/api/docs/guides/your-data)
- [GSMA SGP.32 eSIM IoT specification](https://www.gsma.com/solutions-and-impact/technologies/esim/gsma_resources/sgp-32-v1-3/)
- [Starlink Direct to Cell](https://www.starlink.com/business/direct-to-cell)
- [Detailed companion-app and synchronization architecture](../design/0002_companion_app_and_sync_architecture.md)

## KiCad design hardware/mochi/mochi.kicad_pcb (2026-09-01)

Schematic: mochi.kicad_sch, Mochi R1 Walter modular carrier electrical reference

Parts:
C1: 1uF 25V X7R; C1_C0603
C2: 10uF 25V X7R; C2_C0805
C3: 100nF 25V X7R; C3_C0402
C4: 47nF 25V X7R; C4_C0402
C5: 4.7uF 10V X7R; C5_C0603
C6: 10uF 10V X7R; C6_C0805
C7: 10uF 10V X7R; C7_C0805
C8: 10uF 10V X7R; C8_C0805
C9: 100nF 10V X7R; C9_C0402
C10: 1uF 10V X7R; C10_C0603
C11: 10uF 10V X7R; C11_C0805
C12: 10uF 10V X7R; C12_C0805
C13: 22uF 6.3V X7R; C13_C0805
C14: 100uF 6.3V low-ESR; C14_C1210
C15: 100uF 6.3V low-ESR; C15_C1210
C16: 10uF 10V X7R; C16_C0805
C17: 100nF 10V X7R; C17_C0402
C18: 1uF 6.3V X7R; C18_C0603
C19: 10uF 6.3V X7R; C19_C0805
C20: 100nF 6.3V X7R; C20_C0402
D1: CYAN CAPTURE LED; D1_LED0402
D2: AMBER BUTTON LED; D2_LED0402
D3: WHITE CAMERA POWER LED DNP; D3_LED0402; not fitted
D4: ESDA7P60-1U1M; D4_QFN-2
F1: 1206L075/24; F1_F1206
J1: USB4105-GF-A; J1_USB-C-16P
J2: Molex 5023520300; J2_DuraClik-3P-RA
J4: AS01808AO-SC18-WP-R; J4_Speaker-18x13-Spring
J5: WAVESHARE 1.69IN TOUCH LCD 27057; J5_GH1.25-12P-RA-VERIFY
J6: ARDUCAM MEGA 3MP B0400 DNP; J6_XH2.54-1x6-RA; not fitted
L1: 1uH XGL4020-102; L1_L4x4
L2: 0.47uH XFL4015-471; L2_L4x4
MK1: IM69D129F; MK1_MEMS-5-3.5x2.65-BOTTOM-PORT
R1: 5.1k 1%; R1_R0402
R2: 5.1k 1%; R2_R0402
R3: 4.99k 1%; R3_R0402
R4: 5.23k 1%; R4_R0402
R5: 30.1k 1%; R5_R0402
R6: 100k 1%; R6_R0402
R7: 523R 1%; R7_R0402
R8: 511k 1%; R8_R0402
R9: 91k 1%; R9_R0402
R10: 4.7k 1%; R10_R0402
R11: 4.7k 1%; R11_R0402
R12: 10k 1%; R12_R0402
R13: 1.5k 1%; R13_R0402
R14: 100k 1%; R14_R0402
R15: 1.5k 1%; R15_R0402
R16: 100k 1%; R16_R0402
R17: 100k 1% DNP; R17_R0402; not fitted
R18: 1.5k 1% DNP; R18_R0402; not fitted
RS1: 10m 1% Kelvin; RS1_R1206-Kelvin
SW1: LATCHING POWER SLIDE; SW1_Slide-SPST-RA-TBD
SW2: ILLUMINATED CONVERSATION BUTTON; SW2_Top-Button-TBD
TP1: DEBUG_TX; TP1_TestPoint-1mm
TP2: DEBUG_RX; TP2_TestPoint-1mm
TP3: WALTER_DFU_N; TP3_TestPoint-1mm
TP4: WALTER_RESET_N; TP4_TestPoint-1mm
TP5: MAIN_FAULT_N; TP5_TestPoint-1mm
TP6: 3V3_POWER_GOOD; TP6_TestPoint-1mm
TP7: BQ_INTERRUPT; TP7_TestPoint-1mm
TP8: GROUND; TP8_TestPoint-1mm
TP9: WALTER_3V3_OUT; TP9_TestPoint-1mm
TP10: GAUGE_ALERT; TP10_TestPoint-1mm
TP11: BQ_POWER_GOOD; TP11_TestPoint-1mm
U1: TPD2EUSB30; U1_SOT23-3
U3: BQ25628E; U3_WQFN-18-2.5x3
U4: MAX17055ETB+T; U4_TDFN-10-2x2.5
U5: TPS22950; U5_SOT23-6
U6: TPS63802; U6_VSON-10-3x2
U10: WALTER P000000100 N16R2; U10_WALTER-28-REF
U12: TPS22918; U12_SOT23-6
U13: SN74LVC2G125; U13_VSSOP-8
U14: MAX98357AETE+T; U14_TQFN-16-3x3
U15: TPS22918 DNP CAMERA; U15_SOT23-6; not fitted

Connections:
3V3_PERIPH: C13.1, C19.1, C20.1, J5.1 (VCC), R8.1, R10.2, R11.2, R12.2, U6.5 (VOUT), U12.1 (VIN), U14.1 (VDD), U15.1 (VIN)
3V3_PG_TP: TP6.1, U6.7 (PG)
AMBER_LED: D2.1 (A), U10.13 (IO2)
AMBER_LED_K: D2.2 (K), R13.1
AMP_SD: R16.1, U10.12 (IO42), U14.6 (SD_MODE)
BAT_NTC: J2.2 (NTC), R4.2, R5.1, U3.11 (TS)
BB_FB: R8.2, R9.1, U6.6 (FB)
BB_L1: L2.1, U6.3 (L1)
BB_L2: L2.2, U6.4 (L2)
BQ_BTST: C4.1, U3.4 (BTST)
BQ_INT_N_TP: TP7.1, U3.14 (INT_N)
BQ_PG_N_TP: TP11.1, U3.15 (PG_N)
BQ_PMID: C2.1, C3.1, U3.2 (PMID)
BQ_REGN: C5.1, U3.5 (REGN)
BQ_SW: C4.2, L1.1, U3.3 (SW)
BTN_CONV: R12.1, SW2.1 (SIGNAL), U10.10 (IO40)
CAM_3V3: D3.1 (A), J6.1 (VCC), U15.3 (VOUT)
CAM_CS: J6.6 (CS), U10.14 (IO1)
CAM_EN: R17.1, U10.21 (IO17), U15.2 (EN)
CAM_LED_K: D3.2 (K), R18.1
CAPTURE_EN: R14.1, U10.11 (IO41), U12.2 (EN)
CYAN_LED_K: D1.2 (K), R15.1
DBG_RX: TP2.1, U10.2 (IO44/RX0)
DBG_TX: TP1.1, U10.3 (IO43/TX0)
GAUGE_ALRT_N: TP10.1, U4.6 (ALRT_N)
GND: C1.2, C2.2, C3.2, C5.2, C6.2, C7.2, C8.2, C9.2, C10.2, C11.2, C12.2, C13.2, C14.2, C15.2, C16.2, C17.2, C18.2, C19.2, C20.2, D4.2 (A), J1.2 (GND), J1.5 (SHIELD), J5.2 (GND), J6.2 (GND), MK1.2 (GND), MK1.5 (L/R), R1.2, R2.2, R3.2, R5.2, R6.2, R7.2, R9.2, R13.2, R14.2, R15.2, R16.2, R17.2, R18.2, RS1.2 (SYSTEM), SW2.2 (GND), TP8.1, U1.3 (GND), U3.8 (GND), U3.16 (CE_N), U4.3 (CSN), U5.6 (GND), U6.8 (GND), U10.27 (GND), U12.4 (GND), U13.2 (GND), U13.3 (OE1_N), U13.6 (OE2_N), U14.2 (GND), U15.4 (GND)
I2C_SCL: J5.10 (TP_SCL), R11.1, U3.13 (SCL), U4.5 (SCL), U10.24 (IO9)
I2C_SDA: J5.9 (TP_SDA), R10.1, U3.12 (SDA), U4.4 (SDA), U10.23 (IO8)
I2S_BCLK: U10.17 (IO6), U14.3 (BCLK)
I2S_DOUT: U10.19 (IO15), U14.5 (DIN)
I2S_LRCLK: U10.18 (IO7), U14.4 (LRCLK)
LCD_BL: J5.8 (LCD_BL), U10.9 (IO39)
LCD_CS: J5.5 (LCD_CS), U10.25 (IO10)
LCD_DC: J5.6 (LCD_DC), U10.8 (IO38)
MAIN_FLT_N: TP5.1, U5.5 (FLT_N)
MAIN_ILIM: R7.1, U5.4 (ILIM)
MIC_3V3: C18.1, D1.1 (A), MK1.1 (VDD), U12.3 (VOUT), U13.1 (VCC)
PACK_N: J2.3 (PACK-), RS1.1 (PACK), U4.2 (CSP)
PACK_P: C8.1, C9.1, J2.1 (PACK+), U3.6 (BAT), U4.1 (BATT)
PDM_CLK_MCU: U10.15 (IO4), U13.4 (A1)
PDM_CLK_MIC: MK1.3 (CLK), U13.5 (Y1)
PDM_DATA_MCU: U10.16 (IO5), U13.8 (Y2)
PDM_DATA_MIC: MK1.4 (DATA), U13.7 (A2)
PWR_SW_ON: R6.1, SW1.2 (ON), U5.2 (ON)
SPI_MISO: J6.4 (MISO), U10.7 (IO13)
SPI_MOSI: J5.3 (LCD_DIN), J6.5 (MOSI), U10.6 (IO11)
SPI_SCK: J5.4 (LCD_CLK), J6.3 (SCK), U10.5 (IO12)
SPK_N: J4.2 (-), U14.8 (OUTN)
SPK_P: J4.1 (+), U14.7 (OUTP)
SYS_ALWAYS: C6.1, C7.1, C10.1, L1.2, SW1.1 (COMMON), U3.7 (SYS), U5.1 (VIN)
SYS_SW: C11.1, C12.1, C14.1, C15.1, C16.1, C17.1, U5.3 (VOUT), U6.1 (VIN), U6.2 (EN), U10.28 (VIN)
TOUCH_IRQ: J5.12 (TP_IRQ), U10.20 (IO16)
TS_BIAS: R4.1, U3.10 (TS_BIAS)
UI_RST_N: J5.7 (LCD_RST), J5.11 (TP_RST), U10.22 (IO18)
USB_CC1: J1.3 (CC1), R1.1, U1.1 (IO1)
USB_CC2: J1.4 (CC2), R2.1, U1.2 (IO2)
USB_ILIM_500MA: R3.1, U3.9 (ILIM)
VBUS_5V: C1.1, F1.2, U3.1 (VBUS)
VBUS_CONN: D4.1 (K), F1.1, J1.1 (VBUS)
WALTER_3V3_TP: TP9.1, U10.26 (3V3_OUT)
WALTER_DFU_N: TP3.1, U10.4 (IO0/DFU/3V3_EN)
WALTER_RESET_N: TP4.1, U10.1 (RESET/EN)

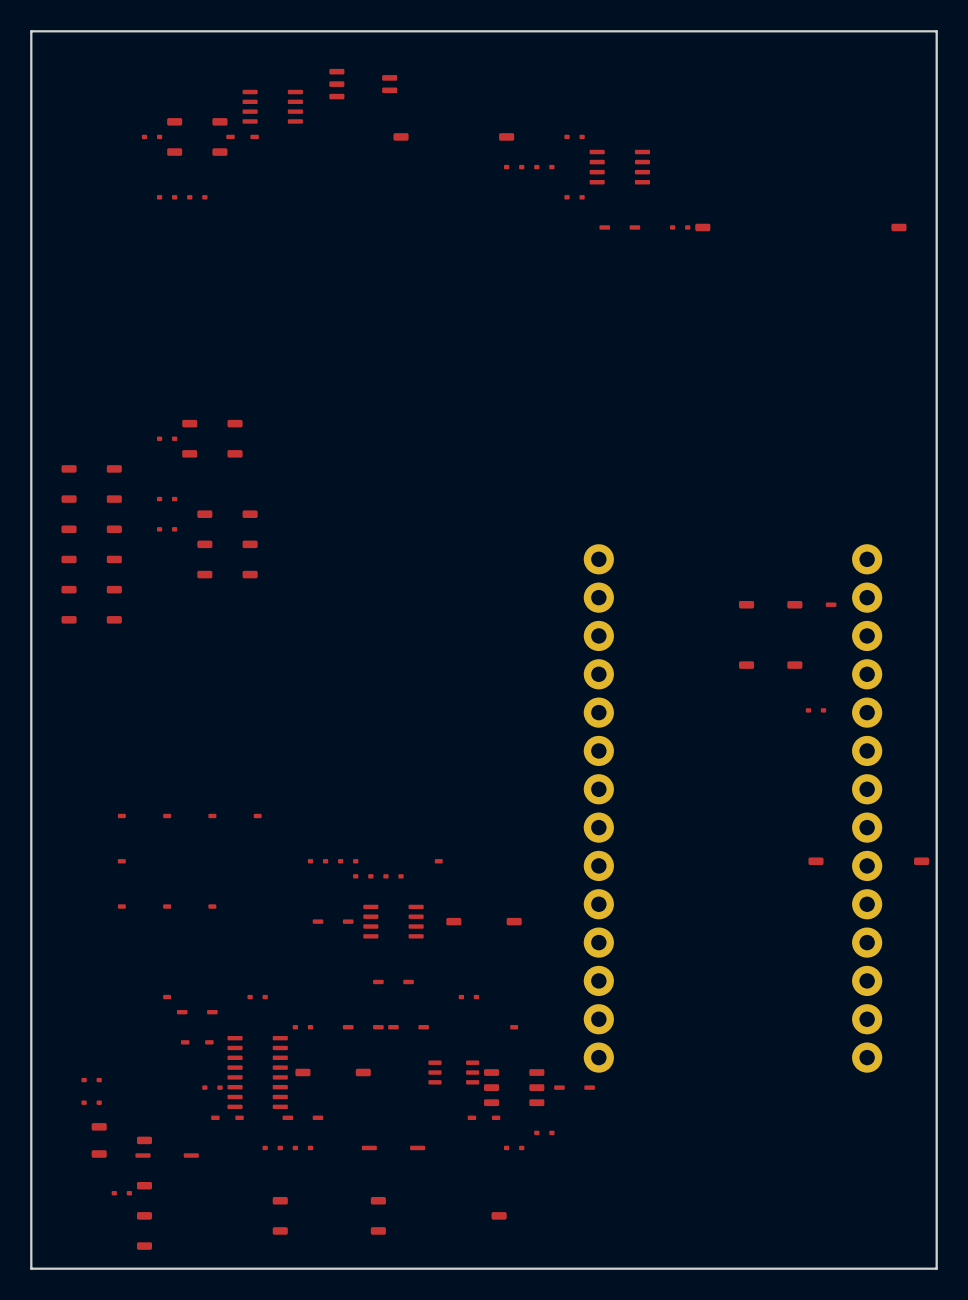
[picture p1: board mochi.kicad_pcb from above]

Board: 4 copper layers, 60.0 x 82.0 mm, 75 parts (1 on the bottom side), 62 nets, no tracks yet.

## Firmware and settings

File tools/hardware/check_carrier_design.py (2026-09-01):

#!/usr/bin/env python3
"""Verify the desk-checkable Mochi R1 Walter-carrier reference claims.

This is deliberately stricter than a document linter and deliberately weaker
than a claim that hardware works.  It checks the generated contract, schematic,
placement PCB, and KiCad ERC/DRC output.  RF, thermal, acoustic, battery, and
certification claims remain physical validation gates.
"""

from __future__ import annotations

import csv
import json
import re
import shutil
import subprocess
import sys
import tempfile
import xml.etree.ElementTree as ET
from pathlib import Path


ROOT = Path(__file__).resolve().parents[2]
HW = ROOT / "hardware" / "mochi"
DOC = HW / "doc"
MANIFEST_PATH = DOC / "design_manifest.json"
CONNECTIVITY_PATH = DOC / "connectivity.csv"
PIN_MAP_PATH = DOC / "pin_map.csv"
BOM_PATH = DOC / "bom.csv"
SCHEMATIC_PATH = HW / "mochi.kicad_sch"
PCB_PATH = HW / "mochi.kicad_pcb"

passes: list[tuple[str, str]] = []
warnings: list[tuple[str, str]] = []
failures: list[tuple[str, str]] = []


def check(condition: bool, name: str, detail: str = "") -> None:
    (passes if condition else failures).append((name, detail))


def warn(name: str, detail: str = "") -> None:
    warnings.append((name, detail))


def read_csv(path: Path) -> list[dict[str, str]]:
    with path.open(newline="", encoding="utf-8") as handle:
        return list(csv.DictReader(handle))


for artifact in (
    MANIFEST_PATH,
    CONNECTIVITY_PATH,
    PIN_MAP_PATH,
    BOM_PATH,
    SCHEMATIC_PATH,
    PCB_PATH,
):
    check(artifact.is_file() and artifact.stat().st_size > 0,
          f"Artifact exists: {artifact.relative_to(ROOT)}")

if failures:
    for name, detail in failures:
        print(f"FAIL  {name}: {detail}")
    sys.exit(1)

manifest = json.loads(MANIFEST_PATH.read_text(encoding="utf-8"))
connectivity = read_csv(CONNECTIVITY_PATH)
pin_map = read_csv(PIN_MAP_PATH)
bom = read_csv(BOM_PATH)
schematic = SCHEMATIC_PATH.read_text(encoding="utf-8")
pcb = PCB_PATH.read_text(encoding="utf-8")

components = {item["ref"]: item for item in manifest["components"]}
bom_refs = {row["reference"] for row in bom}
nets = {
    row["net"]: set(filter(None, row["endpoints"].split(";")))
    for row in connectivity
}


def exact_net(net: str, expected: set[str]) -> None:
    actual = nets.get(net, set())
    check(actual == expected, f"Exact endpoints for {net}",
          f"expected={sorted(expected)} actual={sorted(actual)}")


# Release boundary and generated-artifact consistency.
check(manifest["status"] == "REFERENCE_ONLY_NOT_RELEASED_FOR_FABRICATION",
      "Release boundary is machine-readable", manifest["status"])
check(components.keys() == bom_refs, "Manifest/BOM reference parity",
      f"manifest-only={sorted(components.keys() - bom_refs)}; "
      f"BOM-only={sorted(bom_refs - components.keys())}")
endpoint_refs = {endpoint.split(".", 1)[0] for eps in nets.values() for endpoint in eps}
check(endpoint_refs <= components.keys(), "Connectivity uses known references",
      str(sorted(endpoint_refs - components.keys())))
check("MOCHI R1 WALTER REFERENCE - DO NOT FAB" in pcb,
      "PCB visibly says DO NOT FAB")

# Mechanical/stack-up facts and the intentionally unrouted state.
board = manifest["board_mm"]
check(board == {"width": 60, "height": 82, "thickness": 1.2, "layers": 4},
      "Board envelope and stack-up contract", str(board))
for layer in ("F.Cu", "In1.Cu", "In2.Cu", "B.Cu"):
    check(f'"{layer}"' in pcb,
          f"Copper layer present: {layer}")
check(pcb.count("(keepout ") >= 4,
      "Walter PCB-antenna keepout exists on every copper layer",
      f"keepouts={pcb.count('(keepout ')}")
segments = pcb.count("(segment ")
vias = pcb.count("(via ")
check(segments == 0 and vias == 0,
      "PCB remains an unrouted placement study",
      f"segments={segments}, vias={vias}")
warn("PCB is intentionally not fabrication-ready",
     "All ratsnest opens must be routed after released footprints and layout review.")

# Walter's modem UART, SIM, RF front end, and ESP USB are internal to U10.  The
# carrier therefore has no raw modem voltage translation or second 5 V rail.
check(components["U10"]["value"] == "WALTER P000000100 N16R2",
      "Purchasable Walter LTE-M baseline is frozen",
      components["U10"]["value"])
exact_net("DBG_TX", {"U10.IO43/TX0", "TP1.1"})
exact_net("DBG_RX", {"U10.IO44/RX0", "TP2.1"})
exact_net("WALTER_DFU_N", {"U10.IO0/DFU/3V3_EN", "TP3.1"})
exact_net("WALTER_RESET_N", {"U10.RESET/EN", "TP4.1"})
check({"U5.VOUT", "U6.VIN", "U6.EN", "U10.VIN"} <= nets["SYS_SW"],
      "Master switched rail powers Walter and the peripheral converter",
      str(sorted(nets["SYS_SW"])))
check("J1.VBUS" in nets["VBUS_CONN"] and "U3.VBUS" in nets["VBUS_5V"],
      "User USB-C is charging-only and reaches the BQ power path through F1")
check(not any(net.startswith("USB_DP") or net.startswith("USB_DM") for net in nets),
      "No user-accessible USB data path can back-power Walter")

# Hard-off topology: the small slide only commands a protected, reverse-
# blocking switch.  Charger and gauge remain intentionally battery-attached.
check({"SW1.ON", "U5.ON", "R6.1"} == nets["PWR_SW_ON"],
      "One slide command gates the master load switch",
      str(sorted(nets["PWR_SW_ON"])))
check({"U3.SYS", "L1.2", "C6.1", "C7.1", "SW1.COMMON", "U5.VIN", "C10.1"}
      == nets["SYS_ALWAYS"],
      "Always-alive rail is limited to charger storage and switch entry",
      str(sorted(nets["SYS_ALWAYS"])))
check({"J2.PACK-", "RS1.PACK", "U4.CSP"} == nets["PACK_N"] and
      {"RS1.SYSTEM", "U4.CSN"} <= nets["GND"],
      "MAX17055 low-side Kelvin sense polarity follows vendor application",
      f"PACK_N={sorted(nets['PACK_N'])}")
hard_off = manifest["hard_off"]
check({"SYS_SW", "3V3_PERIPH", "MIC_3V3", "CAM_3V3"} <= set(hard_off["rails_off"]),
      "Hard-off contract names every sensitive rail")
check(components["U5"]["value"] == "TPS22950" and
      any("reverse-current blocking" in item for item in hard_off["backpower_controls"]),
      "Disabled-state reverse blocking is explicit at the master switch")
check("hidden" in " ".join(hard_off["backpower_controls"]).lower(),
      "Walter's directly tied USB/VIN path is an explicit enclosure constraint")

# Privacy truth path: CAPTURE_EN has a fail-safe pull-down, while the cyan LED
# is powered by the downstream microphone rail rather than an independent GPIO.
exact_net("CAPTURE_EN", {"U10.IO41", "U12.EN", "R14.1"})
check(components["R14"]["value"].startswith("100k"),
      "CAPTURE_EN pull-down is populated", components["R14"]["value"])
check({"U12.VOUT", "U13.VCC", "MK1.VDD", "D1.A", "C18.1"} == nets["MIC_3V3"],
      "Cyan LED is inseparable from powered mic/isolation domain",
      str(sorted(nets["MIC_3V3"])))
check(components["D1"]["population"] == "FIT",
      "Cyan capture indicator is fitted")
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

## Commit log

2026-08-31 Build beginner V1 full-duplex prototype
2026-09-01 Add PCB-focused KiCad learning path
2026-09-01 Add Mochi carrier hardware reference design
    [bom.csv, connectivity.csv, mochi.kicad_pcb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]
